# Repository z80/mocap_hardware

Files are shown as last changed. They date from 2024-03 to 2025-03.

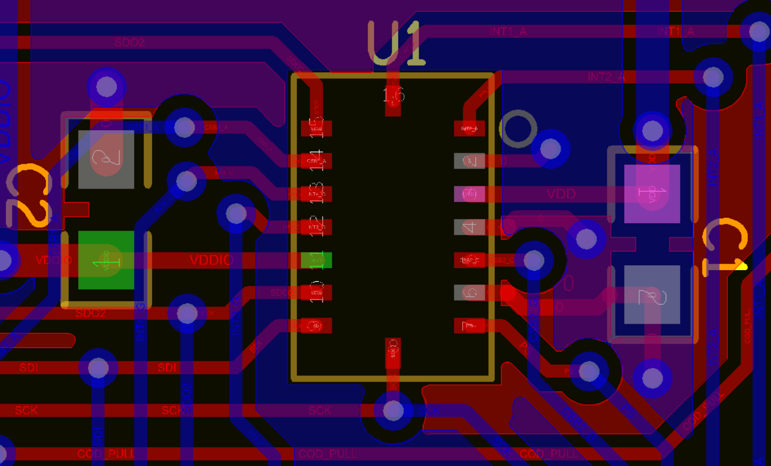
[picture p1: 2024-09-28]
part_datasheets/bmi085/typical_layout.png

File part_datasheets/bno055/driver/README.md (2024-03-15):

CONTENTS OF THIS FILE
=======================
	* Introduction
	* Version
	* Integration details
	* Driver files information
	* Supported sensor interface
	* Copyright

INTRODUCTION
===============
	- This package contains the Bosch Sensortec MEMS BNO055 sensor driver (sensor API)
	- The sensor driver package includes bno055.h, bno055.c and bno055_support.c files

VERSION
=========
	- Version of bno055 sensor driver is:
		* bno055.c 		- V2.0.3
		* bno055.h 		- V2.0.3
		* bno055_support.c 	- V1.0.4

INTEGRATION DETAILS
=====================
	- Integrate bno055.h and bno055.c file in to your project.
	- The bno055_support.c file contains only examples for API use cases, so it is not required to integrate into project.

Driver FILES INFORMATION
===========================
	bno055.h
	-----------
		* This header file has the register address definition, constant definitions, data type definition and supported sensor driver calls declarations.

	 bno055.c
	------------
		* This file contains the implementation for the sensor driver APIs.

	 bno055_support.c
	----------------------
		* This file shall be used as an user guidance, here you can find samples of
    			* Initialize the sensor with I2C communication
        				- Add your code to the I2C bus read and bus write functions.
            					- Return value can be chosen by yourself
           					- API just passes that value to your application code
        				- Add your code to the delay function
        				- Change I2C address accordingly in bno055.h
   			* Power mode configuration of the sensor
   			* Get and set functions usage
			* Reading the sensor read out data

SUPPORTED SENSOR INTERFACE
====================================
	- This BNO055 sensor driver supports I2C interface

COPYRIGHT
===========
	- Copyright (C) 2015 - 2016 Bosch Sensortec GmbH

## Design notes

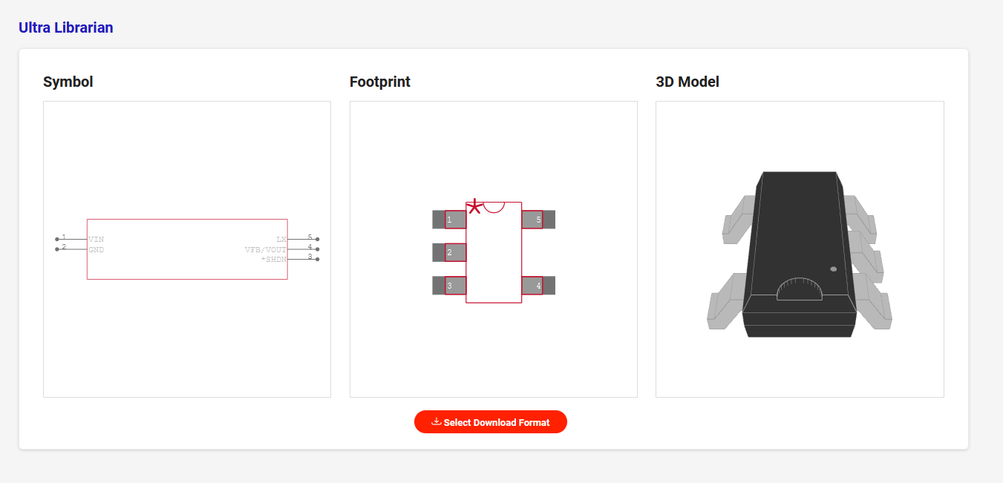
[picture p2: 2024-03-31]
part_datasheets/mcp1603_buck_converter/from_digikey_page.png

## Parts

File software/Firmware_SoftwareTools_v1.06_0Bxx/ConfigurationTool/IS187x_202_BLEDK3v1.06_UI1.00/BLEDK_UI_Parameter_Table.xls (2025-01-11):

Date: 2016/04/20
Name | Display | Range | Help | ID
Name Fragment | Edit Box | 32 characters | NameFragment is a local device name. If a remote device requires a local name, a local device replies the local device name. | IDC_STATIC_NAME_FRAGMENT
HCI Baud Rate Index | ComboBox | 0x00 : 921600 0x01 : 460800 0x02 : 230400 0x03 : 115200 0x04 : 57600 0x05 : 38400 0x06 : 28800 0x07 : 19200 0x08 : 14400 0x09 : 9600 0x0A : 4800 0x0B : 2400 | Baud rate index of the HCI UART port. | IDC_STATIC_HCI_BAUD_RATE_INDEX
H/W Flow Control | ComboBox | Disable Enable | UART H/W flow control (CTS). This parameter need to be set as disable if MCU not support flow control. If Operation Pattern select Manual Pattern, the flow control will be set as disable automatically. | IDC_STATIC_CTS_RTS_FLOW_CONTROL
Check Rx Data Interval | Edit Box | 0x00 ~ 0xFF | The time interval that BLEDK3 checks the received data buffer. When set as “00”, the default value in BLEDK3 for each baud rate is as below: 921600 ~ 19200:0x01 14400 ~ 9600:0x02 4800:0x04 Others:0x07 (Unit: 0.625ms) This parameter can be modified when the default setting can’t meet the requirement. The new set up value must greater than the default value. | IDC_STATIC_CHECK_RX_DATA_INTERVAL
UART RX_IND | ComboBox | Enable Disable | Enable / Disable UART RX IND | IDC_STATIC_UART_RX_IND
Operation Pattern | ComboBox | Auto Pattern Manual Pattern | This parameter is used to set the operation pattern between Auto Pattern and Manual Pattern. | IDC_STATIC_OPERATION_PATTERN
Configure Mode Timeout | Edit Box | 0x00: Disable Configure Mode, 0x01~0xFF | This parameter is used to set BLEDK3 configure mode timeout period in Auto Pattern Tool option. | IDC_STATIC_CONFIGURE_MODE_TIMEOUT
Power On Standby Time | Edit Box | 0x01 ~ 0xFF | The standby time duration after power on. Device will enter Shut Down mode when time is up. 0x00~0xFE: Standby time parameter range. 0xFF: Disable Enter shut down mode. | IDC_STATIC_POWER_ON_STANDBY_TIME
Disconnection Standby Time | Edit Box | 0x01 ~ 0xFF | The standby time duration after link disconnected. Device will enter shut down mode when time is up. 0x00~0xFE: Standby time parameters. 0xFF: Disable enter shut down mode. | IDC_STATIC_REMOTE_DISCONNECT_STANDBY_TIME
Wakeup Externel MCU Wait Time | Edit Box | 0x00 ~ 0xFF | The time interval between UART_TX_IND enabled and UART_TXD start transmit data. | IDC_STATIC_WAKEUP_EXTERNAL_MCU_WAIT_TIME
Wakeup Pin Option | ComboBox | Enable waken up from shutdown mode by wakeup pin Disable waken up from shutdown mode by wakeup pin | This parameter is used to decide BLEDK3 can be woken up from shutdown mode by wakeup pin or not. If option is enabled, GPIO P2_3 will be configured as wakeup Pin. | IDC_STATIC_WAKEUP_PIN_OPTION
Bluetooth 4.0 BLE Security | ComboBox | Disable Pairing Request Permission Enable | This parameter is used to set BLE Security. Refer to BLUETOOTH SPECIFICATION 4.0 or latest version for the detail. | IDC_STATIC_BLE_SECURITY
IO Capability | ComboBox | 0x00: DisplayOnly 0x01: DisplayYesNo 0x02: KeyboardOnly 0x03: NoInputNoOutput 0x04: KeyboardDisplay | This parameter is used to configure IO Capability. Refer to BLUETOOTH SPECIFICATION 4.0 or latest version for the detail. | IDC_STATIC_IO_CAPABILITY
BLE User Confirm Option | ComboBox | Disable LE user confirm refer to passkey Enable LE user confirm refer to passkey | This parameter is used to enable/disable LE(Low Energy) user confirmation referring to passkey. The passkey must set 6 digits if enabled. | IDC_STATIC_BLE_USER_CONFIRM_OPTION
Passkey | Edit Box | 6 Numbers | The Passkey which is six byte ASCII code and be used in passkey confirm. | IDC_STATIC_PASSKEY
Trust Device Connection | ComboBox | Disable Enable | This parameter is used to enable/disable trust (paired) device connection. | IDC_STATIC_TRUST_DEVICE_CONNECTION
LE Secure Connections | ComboBox | Disable Enable LE Secure Connections Only Mode | This parameter is used to enable/disable BlueTooth 4.2 LE Secure Connections. | IDC_STATIC_LE_SECURE_CONNECTIONS
Link Manager Version | ComboBox | Link Manager version is BT4.0 Link Manager version is BT4.2 | This parameter is used to choose Link Manager Version between BT4.0 and BT4.2 . | IDC_STATIC_LINK_MANAGER_VERSION
Data Length Extension | ComboBox | Disable Enable | This parameter is used to enable/disable Data Length Extension. | IDC_STATIC_DATA_LENGTH_EXTENSION
eFlash Footprint | Edit Box | (16 characters) | The 16 ASCII characters for the customers' version control code. The download tool can check by this code and reject to download the eFlash if it's mismatch. | IDC_STATIC_FOOTPRINT
Link Quality Detection | ComboBox | Disable Enable | Enable/Disable link quality detection. The RF_Tx_Power_Control_feature will be disabled if Enable this parameter. | IDC_STATIC_LINK_QUALITY_DETECTION
RSSI Normal Threshold | Edit Box | 50 ~ 90 | RSSI: RF Signal Strength Indication. This parameter is used to set RSSI normal threshold value If detected RSSI value greater or lower than normal threshold level, the configured RSSI_IND GPIO pin will output high or low level respectively. | IDC_STATIC_RSSI_NORMAL_THRESHOLD
RSSI Weak Threshold | Edit Box | 50 ~ 90 | If detected RSSI value greater or lower than weak threshold level, the configured RSSI_IND GPIO pin will output high or low level respectively. | IDC_STATIC_RSSI_WEAK_THRESHOLD
Battery Detection Interval | Edit Box | (1~255) | This parameter is used to set battery detection interval. | IDC_STATIC_BATTERY_DETECTION
High Battery Level | ComboBox | 0x00 : 0.9 V 0x01 : 1.0 V … 0x21 : 4.2 V | High battery level. | IDC_STATIC_HIGH_BATTERY_LEVEL
Normal Battery Level | ComboBox | 0x00 : 0.9 V 0x01 : 1.0 V … 0x21 : 4.2 V | This parameter is defined a normal voltage value of a battery. When the voltage is lower than this value,the device will start low battery warring. | IDC_STATIC_NORMAL_BATTERY_LEVEL
Low Battery Level | ComboBox | 0x00 : 0.9 V 0x01 : 1.0 V … 0x21 : 4.2 V | This parameter is defined a low voltage value of a battery. When the voltage is lower than this value, the configured “LOW_BATTERY_IND” GPIO will output low and the device will enter shutdown mode after the “Low Battery Into Shutdown Time”. | IDC_STATIC_LOW_BATTERY_LEVEL
Dangerous Battery Level | ComboBox | 0x00 : 0.9 V 0x01 : 1.0 V … 0x21 : 4.2 V | When the voltage is lower than Dangerous Battery Level, the device will enter shutdown mode. | IDC_STATIC_DANGEROUS_BATTERY_LEVEL
Low Battery Into Shutdown Time | Edit Box | 0x00:Disable，0x01~0xFF(Unit:640ms) | This parameter is used to set the waiting time befor enter into shutdown mode if low battery happens. (0x00: Disable enter into shutdown mode when low battery happens) | IDC_STATIC_LOW_BATTERY_INTO_POWER_DOWN_TIME
RF Class | ComboBox | 0x01: class 1 0x02: class 2 | The RF_Class is the RF class type. If class 1 is selected, GPIO P1_0 and P2_4 will be set as TX and RX control respectively (High Enable). | IDC_STATIC_RF_CLASS
P36 | Button | 0x01: UART_RTS_CONFIGURE 0x02: BATTERY_LOW_CONFIGURE 0x03: LINK_QUALITY_CONFIGURE 0x05: LINK_DROP_CONFIGURE 0x06: UART_RX_IND_CONFIGURE 0x07: PAIRING_CONFIGURE 0x08: RF_ACTIVE_IND_CONFIGURE 0x09: STATUS1_IND 0x0A: STATUS2_IND | Configure function to the GPIO pins. For detail description please refer to the BLEDK3 release note in “IS187x_BM7X BLEDK3 Application Note” document. | IDC_STATIC_P36
P10 | Button | 0x02: BATTERY_LOW_CONFIGURE 0x03: LINK_QUALITY_CONFIGURE 0x05: LINK_DROP_CONFIGURE 0x06: UART_RX_IND_CONFIGURE 0x07: PAIRING_CONFIGURE 0x08: RF_ACTIVE_IND_CONFIGURE 0x09: STATUS1_IND 0x0A: STATUS2_IND |  | IDC_STATIC_P10
P00 | Button | 0x02: BATTERY_LOW_CONFIGURE 0x03: LINK_QUALITY_CONFIGURE 0x04: UART_CTS_CONFIGURE 0x05: LINK_DROP_CONFIGURE 0x06: UART_RX_IND_CONFIGURE 0x07: PAIRING_CONFIGURE 0x08: RF_ACTIVE_IND_CONFIGURE 0x09: STATUS1_IND 0x0A: STATUS2_IND |  | IDC_STATIC_P00
P31 | Button | 0x02: BATTERY_LOW_CONFIGURE 0x03: LINK_QUALITY_CONFIGURE 0x05: LINK_DROP_CONFIGURE 0x06: UART_RX_IND_CONFIGURE 0x07: PAIRING_CONFIGURE 0x08: RF_ACTIVE_IND_CONFIGURE 0x09: STATUS1_IND 0x0A: STATUS2_IND |  | IDC_STATIC_P31
P32 | Button | 0x02: BATTERY_LOW_CONFIGURE 0x03: LINK_QUALITY_CONFIGURE 0x05: LINK_DROP_CONFIGURE 0x06: UART_RX_IND_CONFIGURE 0x07: PAIRING_CONFIGURE 0x08: RF_ACTIVE_IND_CONFIGURE 0x09: STATUS1_IND 0x0A: STATUS2_IND |  | IDC_STATIC_P32
P33 | Button | 0x02: BATTERY_LOW_CONFIGURE 0x03: LINK_QUALITY_CONFIGURE 0x05: LINK_DROP_CONFIGURE 0x06: UART_RX_IND_CONFIGURE 0x07: PAIRING_CONFIGURE 0x08: RF_ACTIVE_IND_CONFIGURE 0x09: STATUS1_IND 0x0A: STATUS2_IND |  | IDC_STATIC_P33
P34 | Button | 0x02: BATTERY_LOW_CONFIGURE 0x03: LINK_QUALITY_CONFIGURE 0x05: LINK_DROP_CONFIGURE 0x06: UART_RX_IND_CONFIGURE 0x07: PAIRING_CONFIGURE 0x08: RF_ACTIVE_IND_CONFIGURE 0x09: STATUS1_IND 0x0A: STATUS2_IND |  | IDC_STATIC_P34
P07 | Button | 0x02: BATTERY_LOW_CONFIGURE 0x03: LINK_QUALITY_CONFIGURE 0x05: LINK_DROP_CONFIGURE 0x06: UART_RX_IND_CONFIGURE 0x07: PAIRING_CONFIGURE 0x08: RF_ACTIVE_IND_CONFIGURE 0x09: STATUS1_IND 0x0A: STATUS2_IND |  | IDC_STATIC_P07
P11 | Button | 0x02: BATTERY_LOW_CONFIGURE 0x03: LINK_QUALITY_CONFIGURE 0x05: LINK_DROP_CONFIGURE 0x06: UART_RX_IND_CONFIGURE 0x07: PAIRING_CONFIGURE 0x08: RF_ACTIVE_IND_CONFIGURE 0x09: STATUS1_IND 0x0A: STATUS2_IND |  | IDC_STATIC_P11
P22 | Button | 0x02: BATTERY_LOW_CONFIGURE 0x03: LINK_QUALITY_CONFIGURE 0x05: LINK_DROP_CONFIGURE 0x06: UART_RX_IND_CONFIGURE 0x07: PAIRING_CONFIGURE 0x08: RF_ACTIVE_IND_CONFIGURE 0x09: STATUS1_IND 0x0A: STATUS2_IND |  | IDC_STATIC_P22
P24 | Button | 0x02: BATTERY_LOW_CONFIGURE 0x03: LINK_QUALITY_CONFIGURE 0x05: LINK_DROP_CONFIGURE 0x06: UART_RX_IND_CONFIGURE 0x07: PAIRING_CONFIGURE 0x08: RF_ACTIVE_IND_CONFIGURE 0x09: STATUS1_IND 0x0A: STATUS2_IND |  | IDC_STATIC_P24
P35 | Button | 0x02: BATTERY_LOW_CONFIGURE 0x03: LINK_QUALITY_CONFIGURE 0x05: LINK_DROP_CONFIGURE 0x06: UART_RX_IND_CONFIGURE 0x07: PAIRING_CONFIGURE 0x08: RF_ACTIVE_IND_CONFIGURE 0x09: STATUS1_IND 0x0A: STATUS2_IND |  | IDC_STATIC_P35
P12 | Button | 0x02: BATTERY_LOW_CONFIGURE 0x03: LINK_QUALITY_CONFIGURE 0x05: LINK_DROP_CONFIGURE 0x06: UART_RX_IND_CONFIGURE 0x07: PAIRING_CONFIGURE 0x08: RF_ACTIVE_IND_CONFIGURE 0x09: STATUS1_IND 0x0A: STATUS2_IND |  | IDC_STATIC_P12
P13 | Button | 0x02: BATTERY_LOW_CONFIGURE 0x03: LINK_QUALITY_CONFIGURE 0x05: LINK_DROP_CONFIGURE 0x06: UART_RX_IND_CONFIGURE 0x07: PAIRING_CONFIGURE 0x08: RF_ACTIVE_IND_CONFIGURE 0x09: STATUS1_IND 0x0A: STATUS2_IND |  | IDC_STATIC_P13
P16 | Button | 0x02: BATTERY_LOW_CONFIGURE 0x03: LINK_QUALITY_CONFIGURE 0x05: LINK_DROP_CONFIGURE 0x06: UART_RX_IND_CONFIGURE 0x07: PAIRING_CONFIGURE 0x08: RF_ACTIVE_IND_CONFIGURE 0x09: STATUS1_IND 0x0A: STATUS2_IND |  | IDC_STATIC_P16
P17 | Button | 0x02: BATTERY_LOW_CONFIGURE 0x03: LINK_QUALITY_CONFIGURE 0x05: LINK_DROP_CONFIGURE 0x06: UART_RX_IND_CONFIGURE 0x07: PAIRING_CONFIGURE 0x08: RF_ACTIVE_IND_CONFIGURE 0x09: STATUS1_IND 0x0A: STATUS2_IND |  | IDC_STATIC_P17
RF Active IND MCU Include | ComboBox | Indication only when RF active Indication when MCU and RF active | This parameter is used to choose the indication type of RF active. It is activated when RF_ACTIVED_IND function is configured to a GPIO pin. The GPIO will output high when activated. The option is selected between Indication when RF active and Indication when both MCU and RF active. | IDC_STATIC_RF_ACTIVE_IND_MCU_INCLUDE
LE Connection Parameter Update Request | ComboBox | Disable Enable | The LE Connection Setting will be assigned by remote side if select disable. If Enable, device will sent the LE connection parameter update request. | IDC_STATIC_LE_CONNECTION_PARAMETER_UPDATE
Min LE Connection Interval | Edit Box | 0x0008 ~ 0x0C80, Unit: 1.25ms | This parameter is used to set LE min connection interval | IDC_STATIC_MIN_LE_CONNECTION_INTERVAL
Max LE Connection Interval | Edit Box | 0x0010 ~ 0x0C80, Unit: 1.25ms | This parameter is used to set LE max connection interval | IDC_STATIC_MAX_LE_CONNECTION_INTERVAL
LE Slave Latency | Edit Box | 0x0000 ~ 0x03E8 | This parameter is used to set LE slave latency. Slave Latency allows a slave to use a reduced number of connection events. The LE Slave Latency parameter defines the number of consecutive connection events that the slave device is not required to listen for the master. More latency, more power saving but reduced connection event. For example, If slave latency=3, Connection event interval is 100msec, Slave device will wake up every 400msec. (100*(1+3)=400). That is slave only has one Connection event while master already have three connection events. | IDC_STATIC_LE_SLAVE_LATENCY
LE Supervision Timeout | Edit Box | 0x000A ~ 0x0C80 | This parameter is used to set LE supervision timeout | IDC_STATIC_LE_SUPERVISION_TIMEOUT
LE Fast Advertising Interval | Edit Box | 0x0020 ~ 0x4000 | This parameter is used to set “LE fast advertising interval”, which will make LE device work in fast advertising interval after power on. The fast advertising time period is limited and can be set in“LE Fast Advertising Timeout”. | IDC_STATIC_LE_FAST_ADVERTISING_INTERVAL
LE Reduced Power Advertising Interval | ComboBox | 645ms 768ms 961ms 1065ms 1294ms | This parameter is used to set LE reduced power advertising interval. The interval is longer than “Fast Advertising Interval” so that the power consumption can be reduced. | IDC_STATIC_LE_REDUCED_POWER_ADVERTISING
LE Fast Advertising Timeout | Edit Box | 0x00 ~ 0xFF 設為0x00就不會離開Fast Advertising Mode | This parameter is uesd to set LE fast advertising timeout value | IDC_STATIC_LE_FAST_ADVERTISING_TIMEOUT
Power On LE Reduced Power Advertising Timeout | Edit Box |  | This parameter is uesd to show Power On LE Reduced Power Advertising timeout value. Power On LE Reduced Power Advertising timeout = Power on Standby Time - LE Fast Advertising Timeout. | IDC_STATIC_POWER_ON_LE_REDUCED_POWER_ADVERTISING_TIMEOUT
Disconnection LE Reduced Power Advertising Timeout | Edit Box |  | This parameter is uesd to show Disconnection LE Reduced Power Advertising Timeout value. Disconnection LE Reduced Power Advertising Timeout = Disconnection Standby Time - LE Fast Advertising Timeout | IDC_STATIC_DISCONNECTION_LE_REDUCED_POWER_ADVERTISING_TIMEOUT
Advertising Prefered Power Level | ComboBox | 0x00: 0 dBm 0x01: -6 dBm 0x02: -12 dBm 0x03: -18 dBm 0x04: -24 dBm 0x05: -30 dBm | Preferred Tx power level when advertising. There are six power level can be selected.(0,-5,-10,-15,-20,-25 dBm) | IDC_STATIC_ADVERTISING_TX_POWER_LEVEL
Connected Prefered Power Level | ComboBox | 0x00: 0 dBm 0x01: -6 dBm 0x02: -12 dBm 0x03: -18 dBm 0x04: -24 dBm 0x05: -30 dBm | Preferred TX power level when connected. (0,-5,-10,-15,-20,-25 dBm) | IDC_STATIC_CONNECTED_TX_POWER_LEVEL
Advertising Data Setting |  |  | This parameter is uesd to set advertising data. | IDC_STATIC_ADVERTISING_DATA_SETTING
Scan Response Data Setting |  |  | This parameter is uesd to set scan response data | IDC_STATIC_SCAN_RESPONSE_DATA_SETTING
Type | ComboBox | 0x00 : LED1 OFF, LED2 OFF 0x01 : LED1 ON, LED2 ON 0x02 : LED1 ON, LED2 OFF 0x03 : LED1 OFF, LED2 ON 0x04 : LED1 OFF, LED2 FLASH 0x05 : LED1 FLASH, LED2 OFF 0x06 : LED1 ON, LED2 FLASH 0x07 : LED1 FLASH, LED2 ON 0x08 : LED1, LED2 FLASH (simultaneous) 0x09 : LED1, LED2 FLASH (alternate) | The LED0(P0_2)display type setting for Standby, Link, Power On and Low Battery mode. There are 3 types are selectable: Always OFF, Always ON and Flash. The Flash method is set as below: | IDC_STATIC_LED_TYPE
On Duration | Edit Box | (1-255) Unit: 50ms | The LED on time during flash. | IDC_STATIC_LED_ON_TIME
Off Duration | Edit Box | (1-255) Unit: 50ms | The LED off time during flash. | IDC_STATIC_LED_OFF_TIME
Count | Edit Box | (0-3) or (0-255) | This is the number of the flashing times for a cycle. | IDC_STATIC_LED_COUNT
Interval | Edit Box | (0-255) Unit: 50ms | This is the time interval of a cycle. | IDC_STATIC_LED_INTERVAL
Interval | Edit Box | 0x00:Disable，0x01~0xFF(Unit:1sec) | This parameter is uesd to set LED warning time interval if low battery happens | IDC_STATIC_LOW_BATTERY_LED_INTERVAL
LED Brightness | ComboBox | 1 mA 2 mA ... 16 mA |  | IDC_STATIC_LED1_BRIGHTNESS
Beacon Feature | ComboBox | Disable Enable | Enable/Disable Beacon function | IDC_STATIC_BEACON_FEATURE
Beacon Admin Mode | ComboBox | Disable Enable | Enable/Disable Beacon administration mode. | IDC_STATIC_BEACON_ADMIN_MODE
Beacon Admin Timeout | Edit Box | (0-255) Unit: 640ms | This parameter is used to configure Beacon administration timeout value 0x00: Disable Beacon Administration Feature Range: 0x01~0xFF, Unit: 640mS | IDC_STATIC_BEACON_ADMIN_TIMEOUT
Beacon In Connection | ComboBox | Stop Beacon Advertising Beacon Advertising | This option is enabled when BeaconThings function enabled on UI Feature page. If BeaconThings function is enabled: Stop Beacon Advertising: Stop beacon advertising when LE connection is established. Beacon Advertising: Continue beacon advertising when LE connection is established. | IDC_STATIC_BEACON_IN_CONNECTION
Beacon Advertising Interval | Edit Box | (2 Bytes) | This parameter is used to configure the advertising interval for Beacon. | IDC_STATIC_BEACON_ADVERTISING_INTERVAL
Beacon Advertising Data Length | Edit Box | (1 Bytes) | This paraeter is used to configure advertising data length for Beacon using | IDC_STATIC_BEACON_ADVERTISING_DATA_LENGTH
Beacon Advertising Data | Edit Box | Max: 31 bytes | This paraeter is used to configure advertising data for Beacon using | IDC_STATIC_BEACON_ADVERTISING_DATA
Beacon Secret Key | Edit Box | (6 Bytes) | This parameter is used to configure Secret key for Beacon Admin usage | IDC_STATIC_BEACON_SECRET_KEY

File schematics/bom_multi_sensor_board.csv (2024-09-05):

Value | Qty | URL | url
"18p" | 2
"100n" | 6 | https://www.digikey.com/product-detail/en/yageo/CC0603KRX7R7BB104/311-1088-1-ND/302998
"100n" | 5
"4.7uH" | 1 | https://www.digikey.com/en/products/detail/murata-electronics/LQM2HPN4R7MG0L/1893673
"100" | 1 | https://www.digikey.com/en/products/detail/yageo/AC0603JR-07100RL/5896356
"1k" | 4 | https://www.digikey.com/en/products/detail/yageo/RC0603JR-131KL/13694162
"2k" | 83 | https://www.digikey.com/en/products/detail/yageo/AC0603JR-072K2L/5896418
"10k" | 3 | https://www.digikey.com/product-detail/en/yageo/RC0603JR-072K2L/311-2.2KGRCT-ND/729676
"10k" | 2 | https://www.digikey.com/en/products/detail/yageo/RC0603JR-1010KL/13694233
"100k" | 2
+ | 1
- | 1
"1N5819" | 2 | https://www.digikey.com/en/products/detail/stmicroelectronics/1N5819/1037326
"2u2" | 2
"4u7" | 16 | https://www.digikey.com/product-detail/en/samsung-electro-mechanics-america-inc/CL10B475KQ8NQNC/1276-2087-1-ND/3890173
"74HC165" | 4 | https://www.digikey.com/en/products/detail/nexperia-usa-inc/74LV165D-118/1231120
"BM71BLES1FC2-0B02AA" | 1 | https://www.digikey.com/en/products/detail/microchip-technology/BM71BLES1FC2-0B02AA/7164757
bm_cfg | 1
"Crystal" | 1 | https://www.digikey.com/en/products/detail/yic/8M20P2-49US/15648614
gnd | 1
LED | 4
"left hand 0" | 1 | https://www.digikey.com/en/products/detail/assmann-wsw-components/A-MJH-8-EA-GTP-W4/20522480
"left hand 1" | 1 | https://www.digikey.com/en/products/detail/assmann-wsw-components/A-MJH-8-EA-GTP-W4/20522480
"left hand 2" | 1 | https://www.digikey.com/en/products/detail/assmann-wsw-components/A-MJH-8-EA-GTP-W4/20522480
"left hand 3" | 1 | https://www.digikey.com/en/products/detail/assmann-wsw-components/A-MJH-8-EA-GTP-W4/20522480
"left leg 0" | 1 | https://www.digikey.com/en/products/detail/assmann-wsw-components/A-MJH-8-EA-GTP-W4/20522480
"left leg 1" | 1 | https://www.digikey.com/en/products/detail/assmann-wsw-components/A-MJH-8-EA-GTP-W4/20522480
"MCP111" | 1 | https://www.digikey.com/en/products/detail/microchip-technology/MCP111T-315E-TT/716028
"MCP1603" | 1 | https://www.digikey.com/en/products/detail/microchip-technology/MCP1603T-330I-OS/1098431
"MCP73812" | 1 | https://www.digikey.com/en/products/detail/microchip-technology/MCP73812T-420I-OT/1626618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
"MY_USB_B" | 1 | https://www.digikey.com/en/products/detail/on-shore-technology-inc/USB-B1HSB6/2677744
"right hand 0" | 1 | https://www.digikey.com/en/products/detail/assmann-wsw-components/A-MJH-8-EA-GTP-W4/20522480
"right hand 1" | 1 | https://www.digikey.com/en/products/detail/assmann-wsw-components/A-MJH-8-EA-GTP-W4/20522480
"right hand 2" | 1 | https://www.digikey.com/en/products/detail/assmann-wsw-components/A-MJH-8-EA-GTP-W4/20522480
"right hand 3" | 1 | https://www.digikey.com/en/products/detail/assmann-wsw-components/A-MJH-8-EA-GTP-W4/20522480
"right lef 0" | 1 | https://www.digikey.com/en/products/detail/assmann-wsw-components/A-MJH-8-EA-GTP-W4/20522480
"right leg 1" | 1 | https://www.digikey.com/en/products/detail/assmann-wsw-components/A-MJH-8-EA-GTP-W4/20522480
rst | 1
rx | 1
stm_boot | 1
swd | 1
"TCA9548A_TSSOP" | 2 | https://www.digikey.com/product-detail/en/texas-instruments/TCA9548APWR/296-34905-1-ND/3615448
"torso 0" | 1 | https://www.digikey.com/en/products/detail/assmann-wsw-components/A-MJH-8-EA-GTP-W4/20522480
"torso 1" | 1 | https://www.digikey.com/en/products/detail/assmann-wsw-components/A-MJH-8-EA-GTP-W4/20522480
"torso 2" | 1 | https://www.digikey.com/en/products/detail/assmann-wsw-components/A-MJH-8-EA-GTP-W4/20522480
"torso 3" | 1 | https://www.digikey.com/en/products/detail/assmann-wsw-components/A-MJH-8-EA-GTP-W4/20522480
tx | 1
uart1 | 1
Vdd | 1
"~" | 1 | https://www.digikey.com/en/products/detail/stmicroelectronics/stm32f405rgt6/2754208

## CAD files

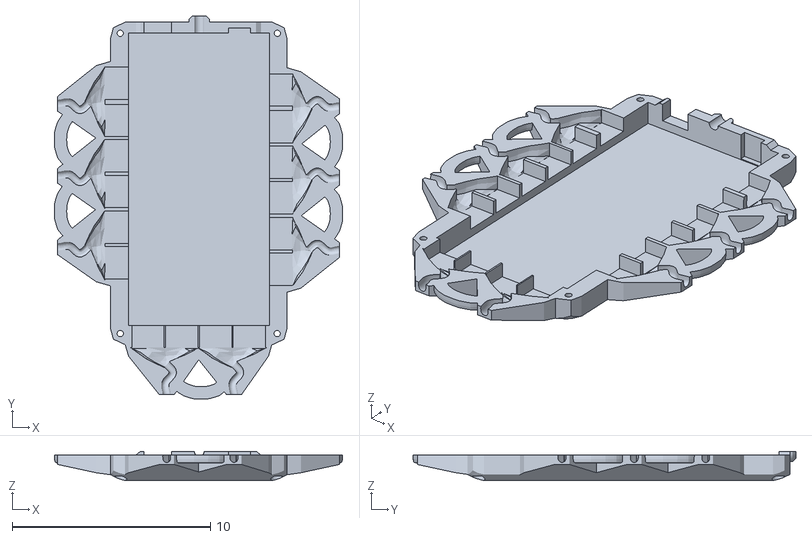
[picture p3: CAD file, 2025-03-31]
cad_drawings/case_for_host_board/case_for_host_board_bottom.stl
14.5 x 19.3 x 1.48

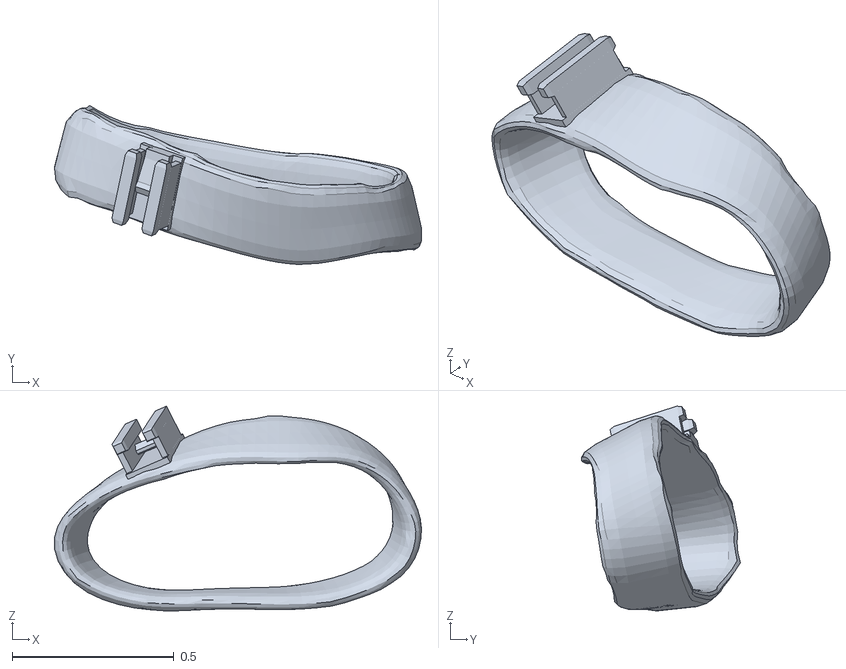
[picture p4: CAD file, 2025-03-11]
cad_drawings/foot/foot_holder_right.stl
1.13 x 0.491 x 0.632

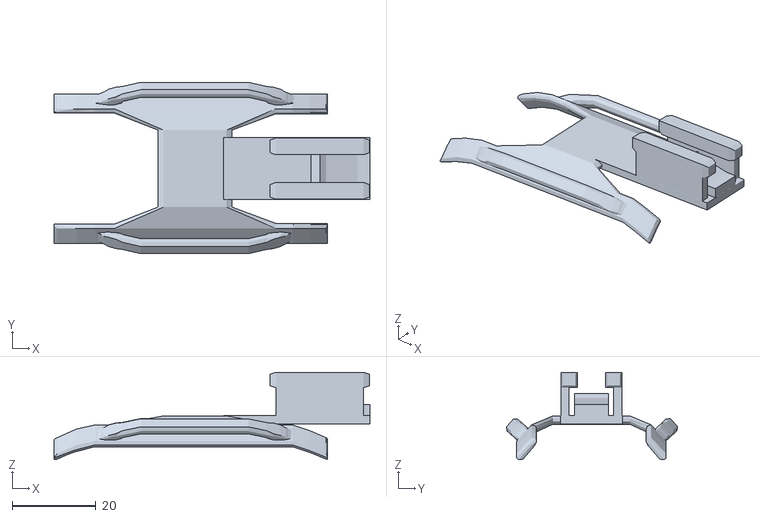
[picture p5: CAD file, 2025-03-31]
cad_drawings/generic_holder/generic_holder.stl
75.3 x 40.8 x 20.9

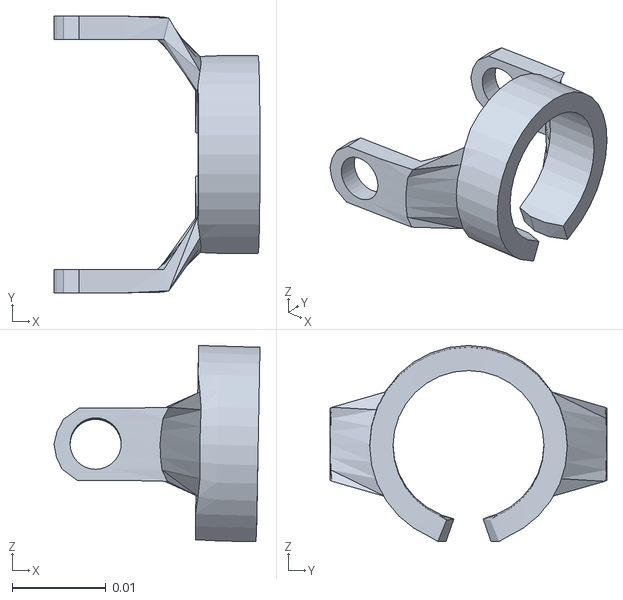
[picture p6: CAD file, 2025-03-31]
cad_drawings/hand/pointing_c.stl
0.022 x 0.0296 x 0.0209

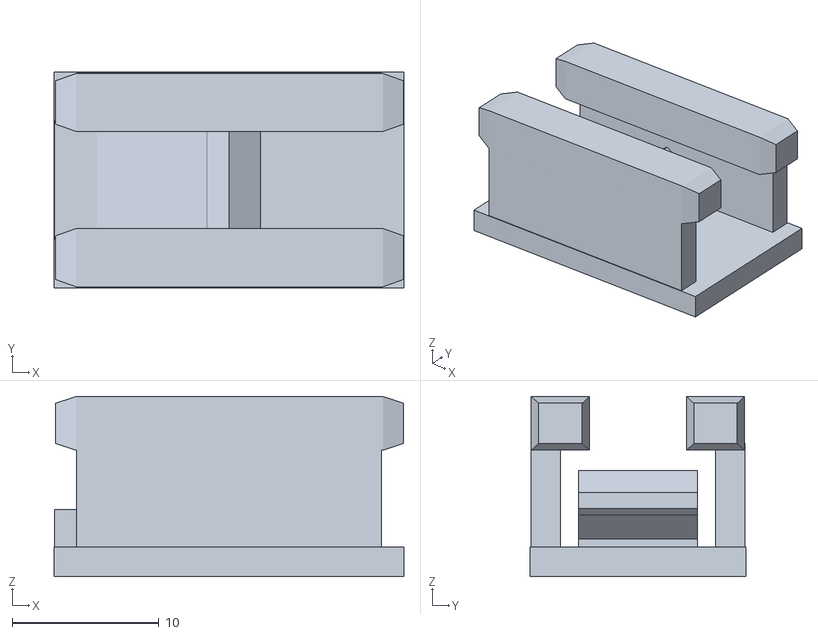
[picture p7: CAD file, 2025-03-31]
cad_drawings/imu_case/receptacle.stl
23.9 x 14.7 x 12.3

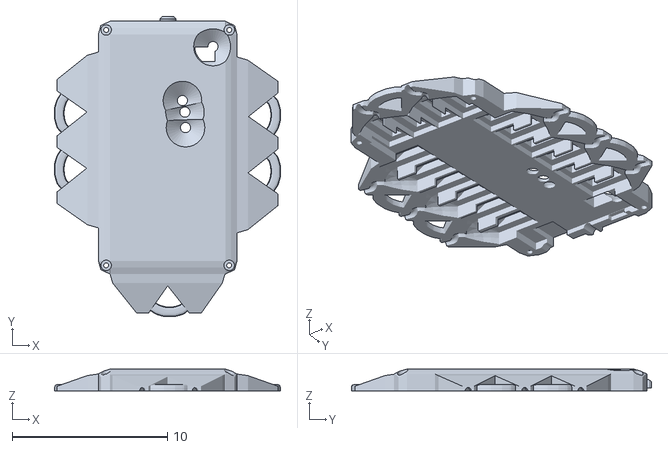
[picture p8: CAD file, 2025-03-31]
cad_drawings/case_for_host_board/case_for_host_board_top.stl
14.5 x 19.3 x 1.40

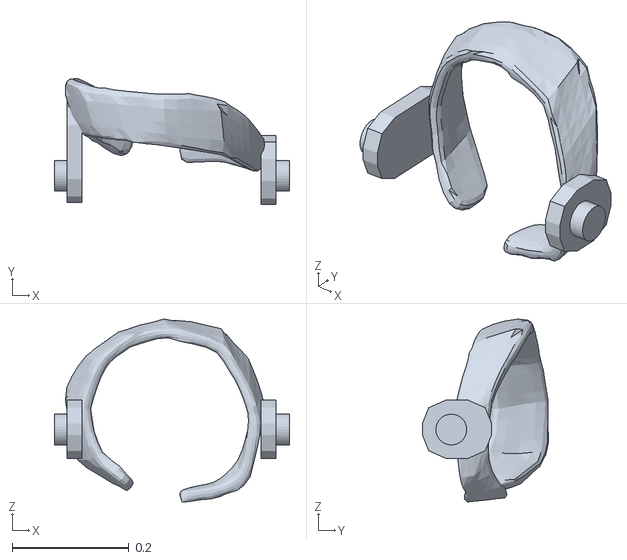
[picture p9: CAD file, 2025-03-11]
cad_drawings/foot/toe_left_a.stl
0.403 x 0.217 x 0.314

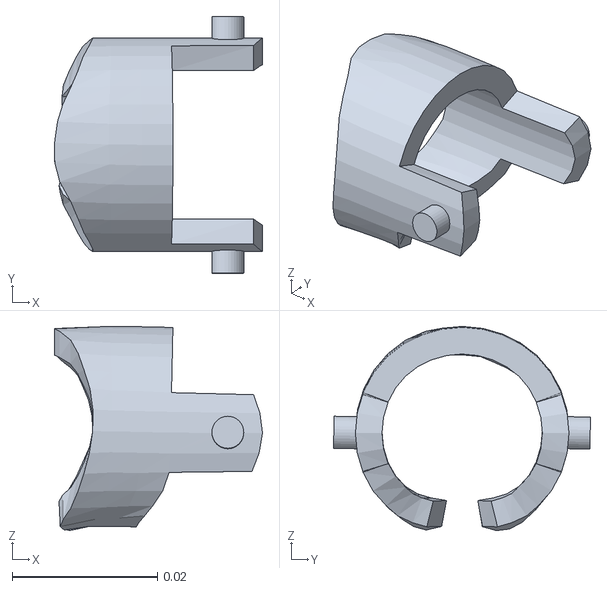
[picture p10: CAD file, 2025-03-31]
cad_drawings/hand/thumb_a.stl
0.0286 x 0.0353 x 0.0281

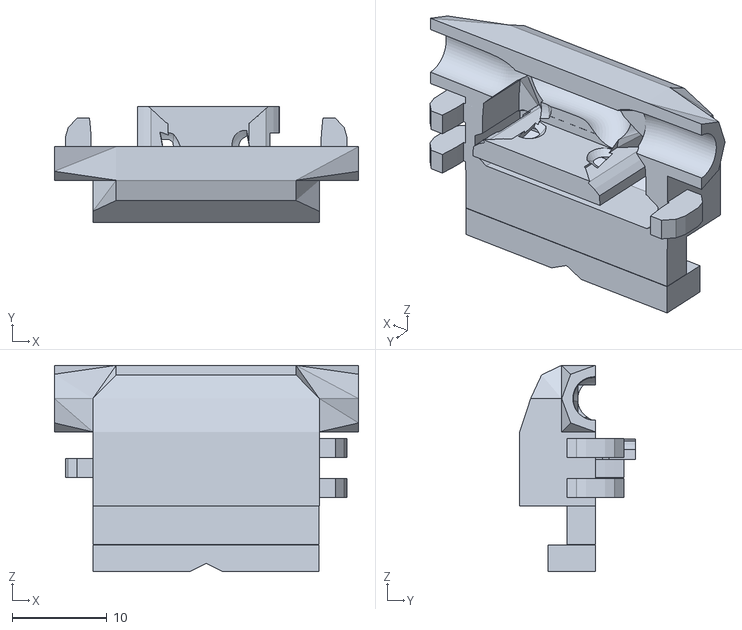
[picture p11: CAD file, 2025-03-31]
cad_drawings/imu_case/imu_case_left.stl
32.1 x 12.2 x 21.8

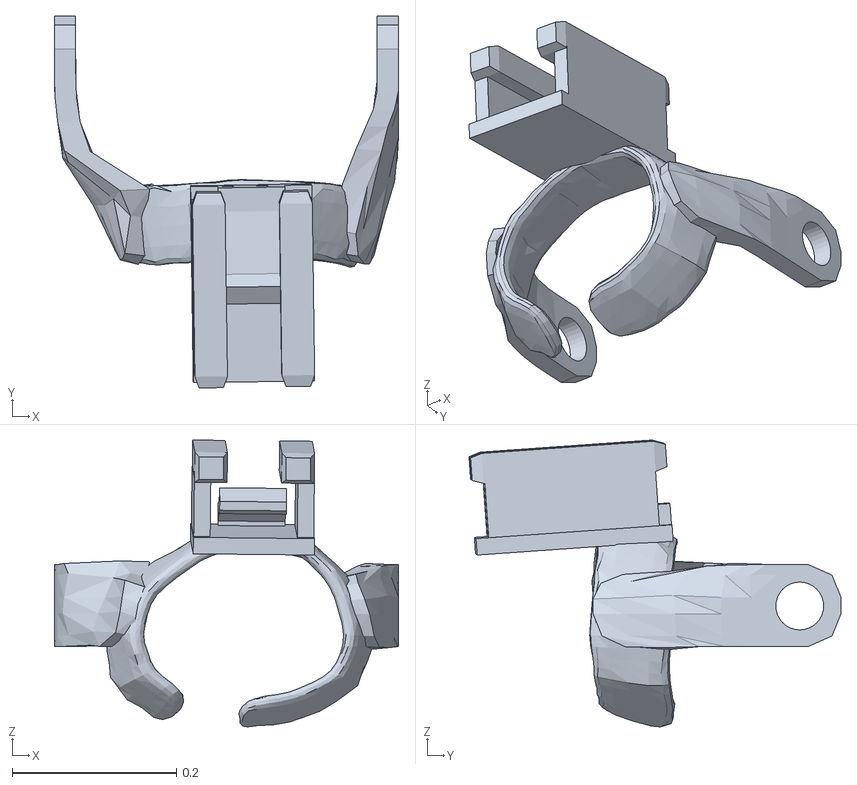
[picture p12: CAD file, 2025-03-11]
cad_drawings/foot/toe_left_b.stl
0.419 x 0.452 x 0.349

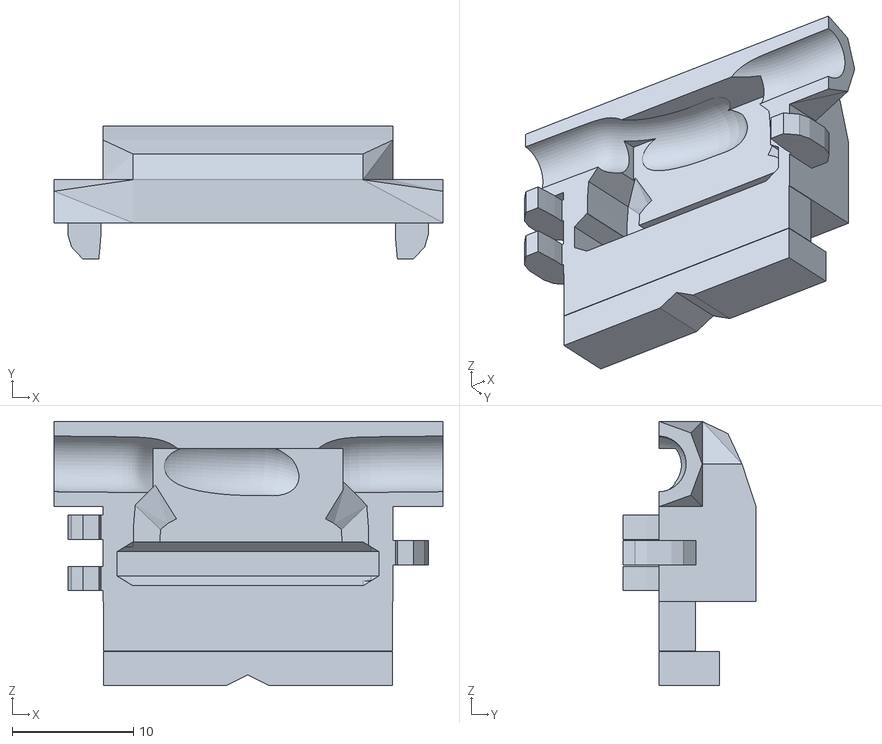
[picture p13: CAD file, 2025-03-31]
cad_drawings/imu_case/imu_case_right.stl
32.1 x 11.0 x 21.8

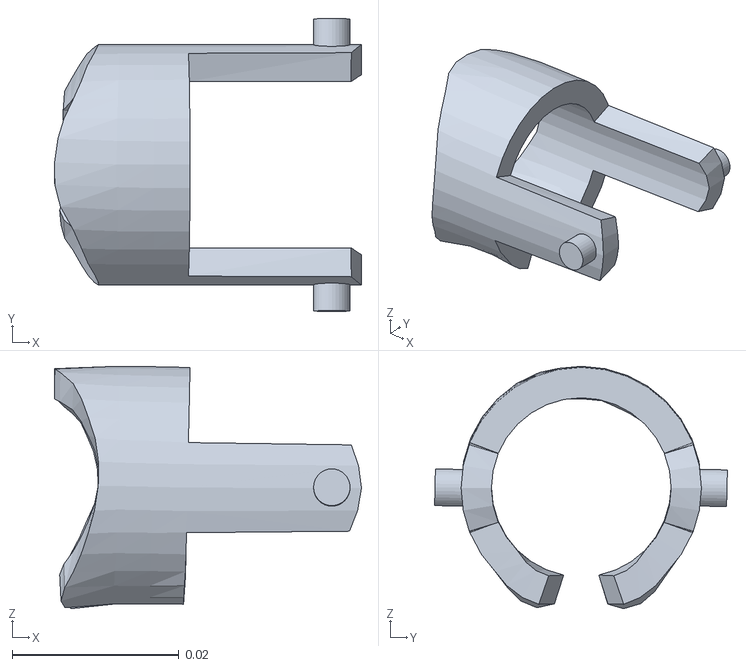
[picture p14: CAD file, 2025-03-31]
cad_drawings/hand/middle_a.stl
0.0369 x 0.0352 x 0.0291

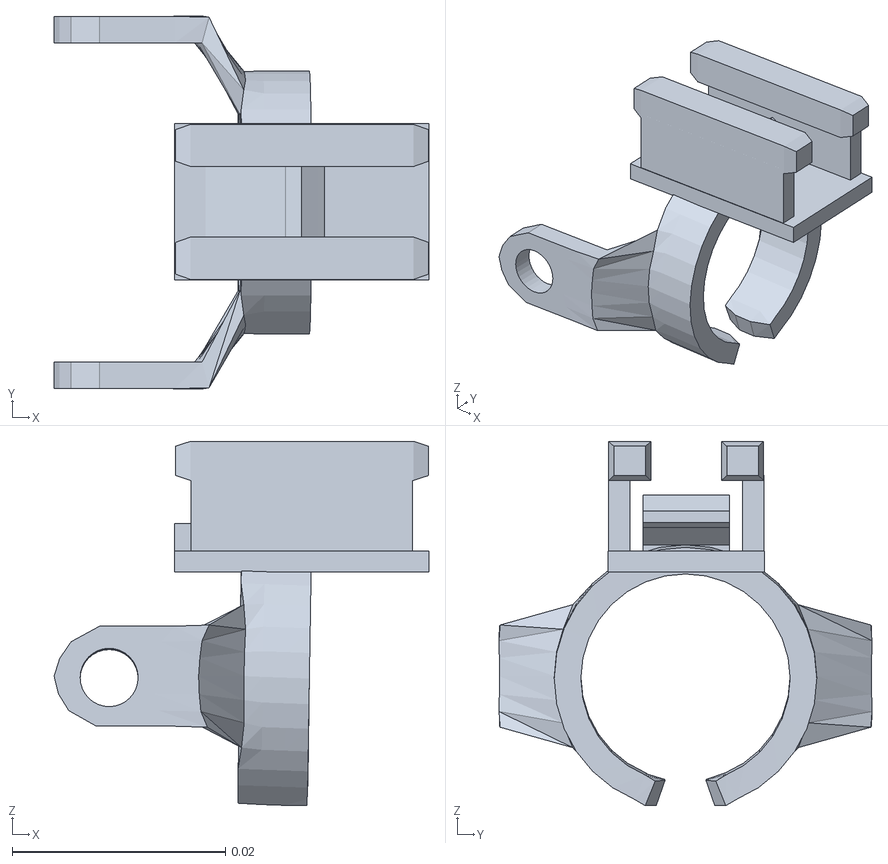
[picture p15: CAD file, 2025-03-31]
cad_drawings/hand/imu_holder_thumb.stl
0.0352 x 0.035 x 0.0342

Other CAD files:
cad_drawings/hand/middle_c.stl
cad_drawings/foot/foot_holder_left.stl
cad_drawings/foot/toe_right_a.stl
cad_drawings/hand/hand_c.stl
cad_drawings/foot/toe_right_b.stl
cad_drawings/generic_holder/generic_holder.blend
cad_drawings/hand/hand.blend
cad_drawings/hand/hand_b.stl
cad_drawings/hand/imu_holder_middle.stl
cad_drawings/hand/imu_holder_palm_l.stl
cad_drawings/hand/imu_holder_palm_r.stl
cad_drawings/hand/imu_holder_pinky.stl
cad_drawings/hand/imu_holder_pointing.stl
cad_drawings/hand/middle_b.stl
cad_drawings/hand/palm_a.stl
cad_drawings/hand/palm_b.stl
cad_drawings/hand/pinky_a.stl
cad_drawings/hand/pinky_b.stl
cad_drawings/hand/pinky_c.stl
cad_drawings/hand/pointing_a.stl
cad_drawings/hand/pointing_b.stl
cad_drawings/hand/thumb_b.stl
cad_drawings/imu_case/imu_case.blend
cad_drawings/locking_mechanism.blend

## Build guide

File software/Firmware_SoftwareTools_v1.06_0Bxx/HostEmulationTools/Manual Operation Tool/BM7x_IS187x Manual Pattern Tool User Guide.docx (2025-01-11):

# IS187x - BLEDK3 v1.00 Manual Pattern Tool

# User Guide

Table of Contents

# 1. Overview

BLEDK3 v0.9 manual pattern test tool is designed to be installed in Microsoft Windows based PC to act as an MCU emulator to transmit and receive commands and events through USB interface during Bluetooth LE profiles communications with a cellular phone.

This document describes how to use the BLEDK3 v0.9 manual pattern test tool, and introduces some supported commands with some examples. Not every single command is defined herein. Please refer to BLEDK3 Command Set document for details.

# 2. Hardware Environment

## 2.1 Top View of BM70BLES1FC2 EVB

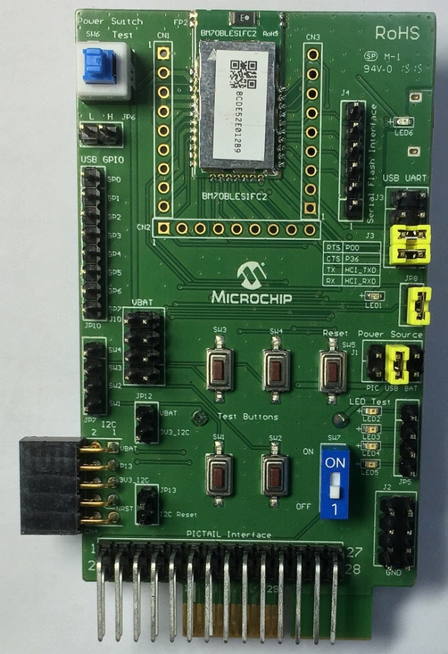
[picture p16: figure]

Figure 2.1 BLEDK3 EVB outlooks

## 2.2 Environment Setup

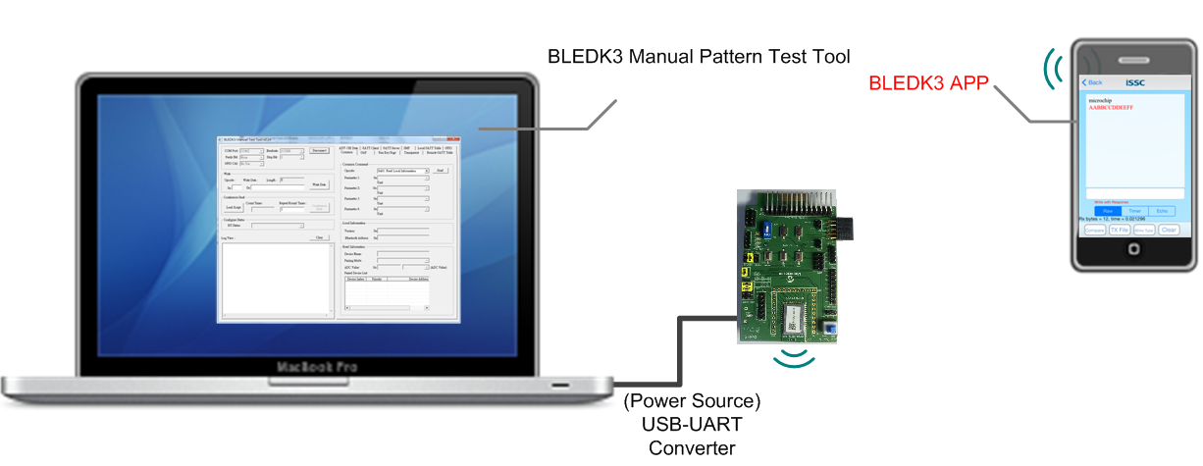
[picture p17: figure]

Figure 2.2 BLEDK3 environment setup

# 3. Tool Overview

Figure 3.1 Tool view

There are four groups of panels labeled by numbers from to in this tool:

1. Settings: The configuration of COM Port, Baud rate, Parity Bit, Stop Bit and GPIO Ctrl. GPIO Ctrl is used to do MCU emulation for specific GPIOs control by MCP2200.

2. Write and Continuous Send: This panel is used for developing only.

3. Log View: It displays all traffic between tool and BLEDK3. Commands will show in red texts and events will come out in blue ones.

4. Function Pages: They are used to do different function controls for BLEDK3. All commands supported by BLEDK3 are divided into several categories: [Common]、[GAP]、[Passkey Page]、[Transparent]、 [ADV/SR Data]、[SMP]、[DIO] 、[GATT Client]、[GATT Server]、[Remote GATT Table] and [Local GATT Table] are described in next chapter.

# 4. BLEDK3 Commands

## 4.1 Common Page

The Common Page includes commands for retrieving configuration or information of BLEDK3.

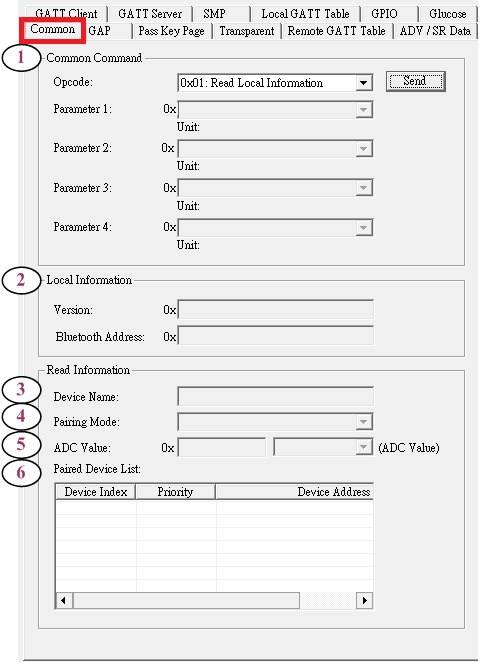
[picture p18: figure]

Figure 4.1 Common page view

1. The command set controller.

2. The response of the command (0x01: Read Local Information).

3. The response of the command (0x07: Read Device Name)

4. The response of the command (0x0A: Read Pairing Mode Setting)

5. The response of the command (0x04: Read ADC Value)

6. The response of the command (0x0C: Read All Paired Device Information)

## 4.2 GAP Page

The GAP Page includes commands for creating or releasing the Link and retrieve some connection information.

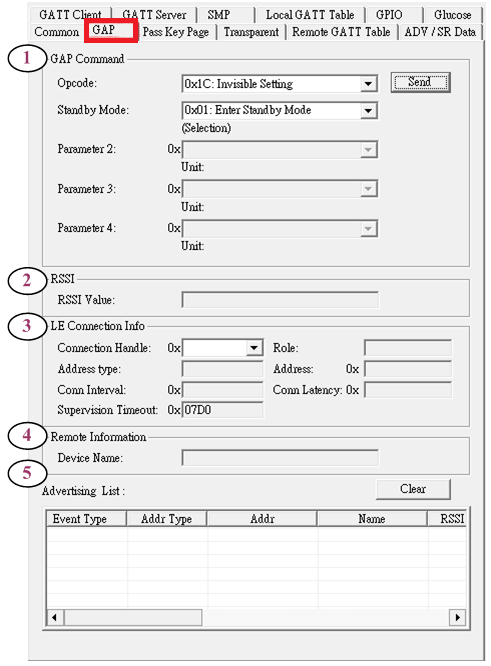
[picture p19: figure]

Figure 4.2 GAP page view

1. The command set controller.

2. The response of the command (0x10: Read RSSI Value).

3. The LE connection information will be displayed here when the LE connection is established.

4. The response of the command (0x1F: Read Remote Device Name).

5. The response of the command (0x16: Set Scan Enable).

## 4.3 Passkey Page

The Passkey Page includes commands for sending Passkey after receiving the pairing request event.

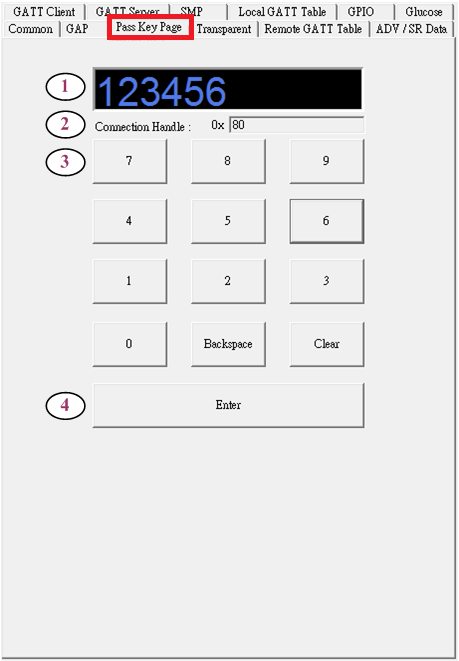
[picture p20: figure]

Figure 4.3 Passkey page view

1. This view will display the Passkey that user entered.

2. When the connection established, the Connection Handle will be filled automatically.

3. These buttons are used to send the command (0x40: Passkey Entry Response).

4. The Enter button is used to send passkey entry completed.

## 4.4 Transparent Page

The Transparent Page includes commands and settings for transmitting data (from BM70 to remote device), a display console for raw data between BM70 and remote device and some related parameter and status display.

Figure 4.4 Transparent page view

1. This is used to send a segment of data.

2. When a connection is established, the Connection Handle will be filled automatically.

3. The repeated round times of data file transmission. (Keep repeating if this parameter set to 0).

4. The delay time between data blocks.

5. The size of an UART data block.

6. The current round of repeating transmission.

7. Amount of transmitted data.

8. Amount of received data.

9. The received data will be sent back while it is enabled.

10. Enable/disable the Compare function. The comparison will be triggered without incoming data for more than 3 seconds.

11. The result of comparison.

12. The elapsed time of the data receiving

13. Load a text file for transmission or received data comparison

14. Start to transmit the file

15. Save received data as a file

16. Clear the received data in the temporary file.

17. The raw data console included transmitted (displayed as red text) and received (displayed as blue text) data.

18. Clear the raw data in the console

## 4.5 ADV / SR Data Page

The ADV / SR Data Page is used for updating the advertising and scan response data.

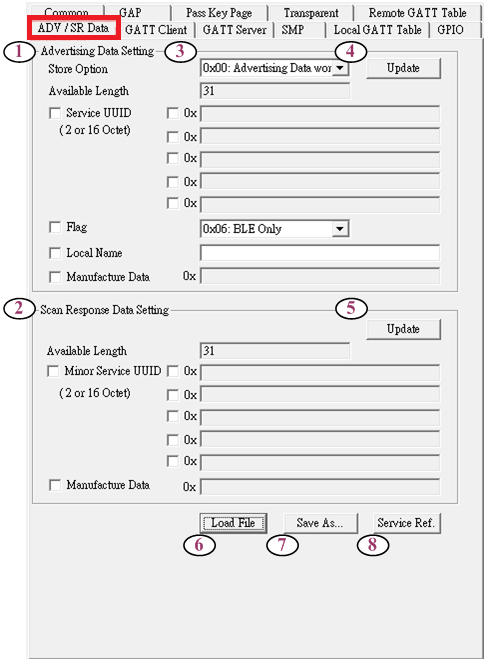
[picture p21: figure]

Figure 4.5 ADV/SR data page view

1. The advertising data editor.

2. The scan response data editor.

3. The store option of advertising data, save in EEPROM or not

4. To update the advertising data by sending command (0x11: Write ADV Data).

To update the scan response data by sending command (0x12: Write Scan Response Data).

To load the ADV / SR data file.

7. To save the ADV / SR data as a file.

8. To visit the services reference on the Bluetooth SIG official website.

## 4.6 SMP Page

The SMP Page is used to initiate pairing procedure.

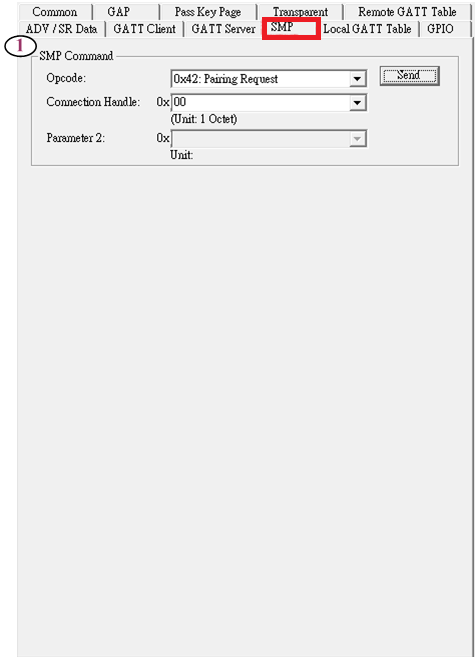
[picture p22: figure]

Figure 4.6 SMP page view

1. The command set controller.

## 4.7 DIO Page

The DIO Page includes commands for control Configurable DIOs and PWM of BLEDK3.

Figure 4.7 DIO page view

1. The command set of DIO control.

2. The command set of PWM control.

## 4.8 GATT Client Page

The GATT Client Page includes GATT client group commands for GATT client procedure.

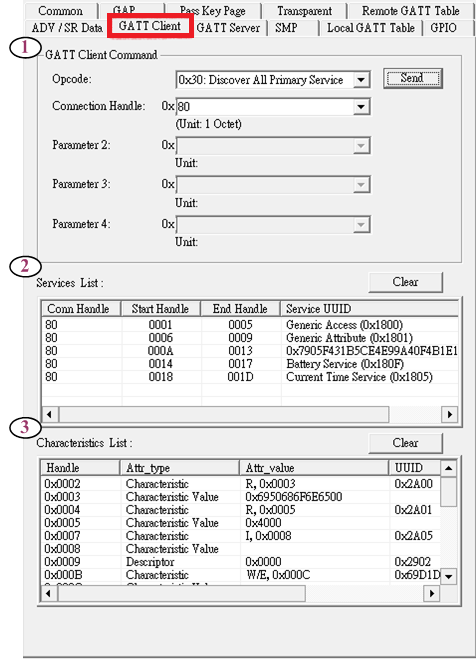
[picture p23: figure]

Figure 4.8 GATT client page view

1. The command set controller.

2. The response of the command (0x30: Discover All Primary Services).

3. The response of the command (0x31: Discover Specific Primary Service Characteristics and Descriptor)(0x32: Read Characteristic Value).

## 4.9 GATT Server Page

The GATT Server Page includes GATT Server group commands for GATT server procedure.

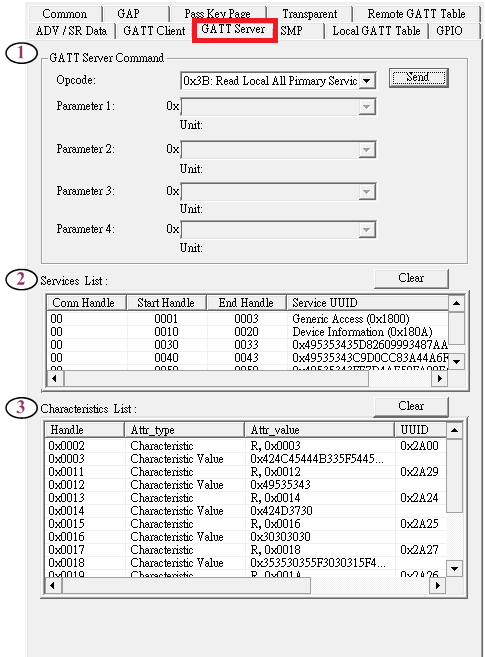
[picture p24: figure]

Figure 4.9 GATT server page view

1. The command set controller.

2. The response of the command (0x3B: Read Local All Primary Services).

3. The response of the command (0x3C: Read Local Specific Primary Service)(0x3A: Read Characteristic Value).

## 4.10 Remote GATT Table Page

The Remote GATT Table Page is used for asking client’s service from server.

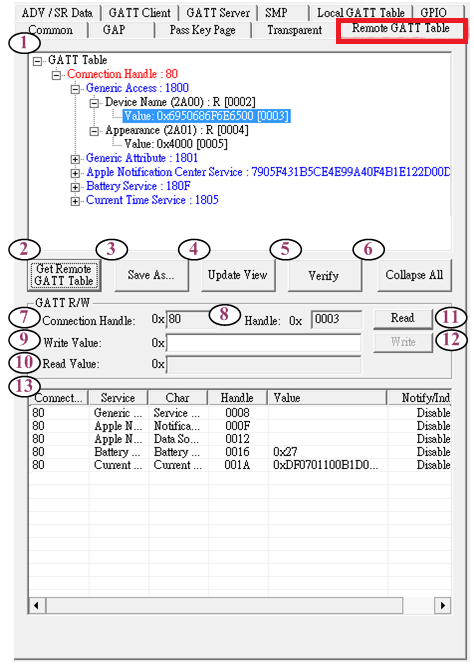
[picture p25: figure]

Figure 4.10 Remote GATT table page view

1. Show supported service of client

2. Start to get the GATT table.

3. Save the GATT table.

4. To update the GATT table.

5. To verify the GATT table.

6. To collapse or expand the GATT table.

7. When the GATT table is clicked, the Connection Handle will be filled automatically.

8. When the GATT table is clicked, the Characteristic Handle will be filled automatically

9. Write a characteristic value

10. Show characteristic value

11. Read Characteristic Value from server.

12. Write Characteristic Value to server.

13. Show support service of client

## 4.11 Local GATT Table Page

The Local GATT Table Page is used for asking server’s service.

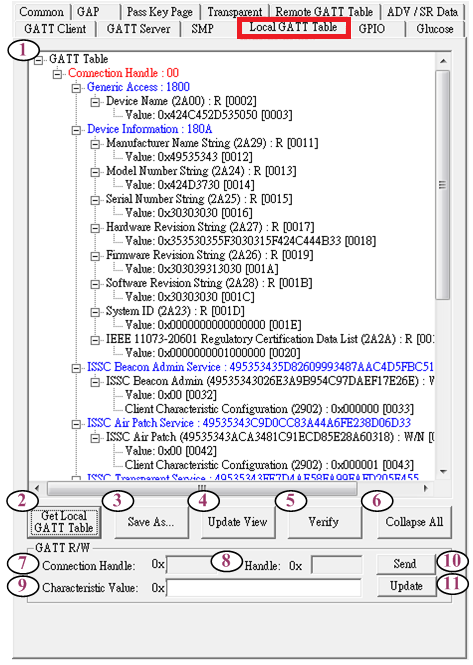
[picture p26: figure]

Figure 4.11 Local GATT table page view

1. Show support service of server

2. Start to get the Local GATT table.

3. Save the Local GATT table.

4. Update the Local GATT table.

5. Verify the Local GATT table.

6. Collapse or expand the Local GATT table.

7. When the Local GATT table is clicked, the Connection Handle will be filled automatically.

8. When the Local GATT table is clicked, the Characteristic Handle will be filled automatically

9. Write a characteristic value

10. Send characteristic value to GATT client

11. Update existing characteristic value of BLEDK3.

# 5. Examples of Operation

## 5.1 Connection

### 5.1.1 Slave Role

As a slave role, BLEDK3 must enter Standby Mode to be discoverable before a connection is established.

1. Select [GAP] Page.
2. Choose the command (0x1C: Invisible Setting).
3. Set the Enter Standby Mode to be discoverable. (0x01 or 0x02).
4. Press the [Send] button to let BLEDK3 advertise and enter Standby Mode.

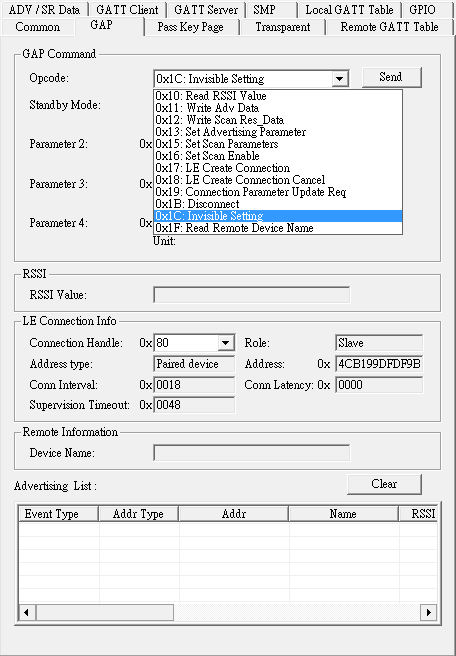
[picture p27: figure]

Figure 5.1.1 BLEDK3 enter standby mode

### 5.1.2 Connection Complete

The following information shows you how to check BLE connection is established successfully.

1. The BT Status will change to LE Connected Mode
2. The connection parameters will be displayed in the [GAP] page.

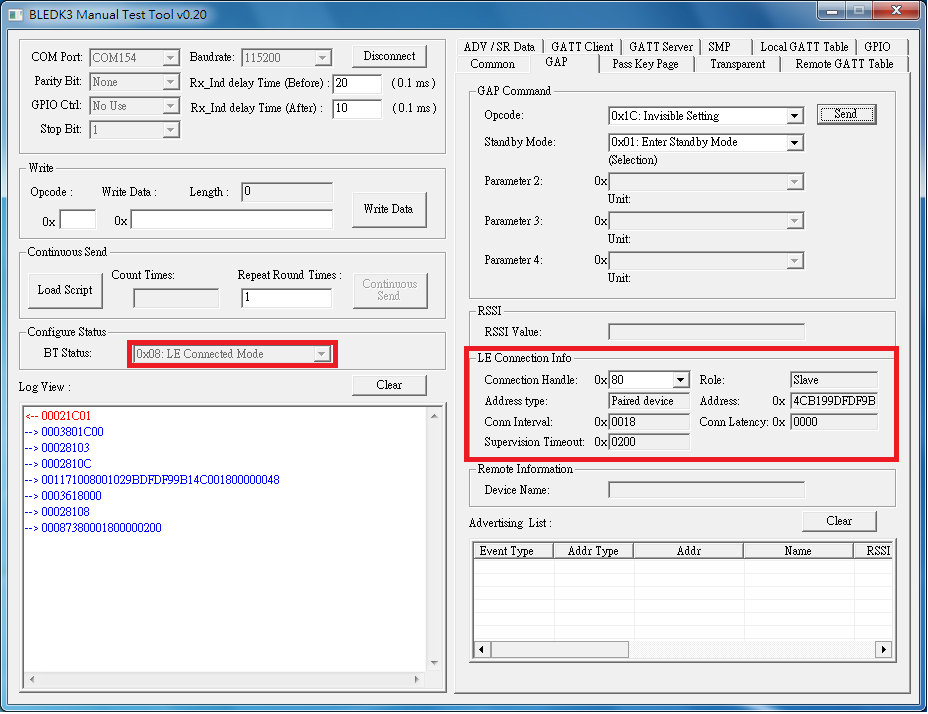
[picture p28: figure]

Figure 5.1.2 BLEDK3 in connected mode

## 5.2 Disconnection

Disconnect a link as below steps:

1. Select the [GAP] Page.
2. Choose the command (0x1B: Disconnect).
3. Press the [Send] button to disconnect the connection.

Figure 5.2.1 BLEDK3 disconnect the connection

There will pop up a message to show the disconnection reason after disconnection is completed.

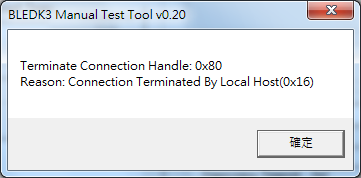
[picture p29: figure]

Figure 5.2.2 The disconnection message

## 5.3 Transparent Service

### 5.3.1 Transparent Operation

There are three ways to transmit data, send data、send a file and loop back mode.

- Send data:
1. Input a segment of send data in the field.
2. Press [Send] button to start the transmission.

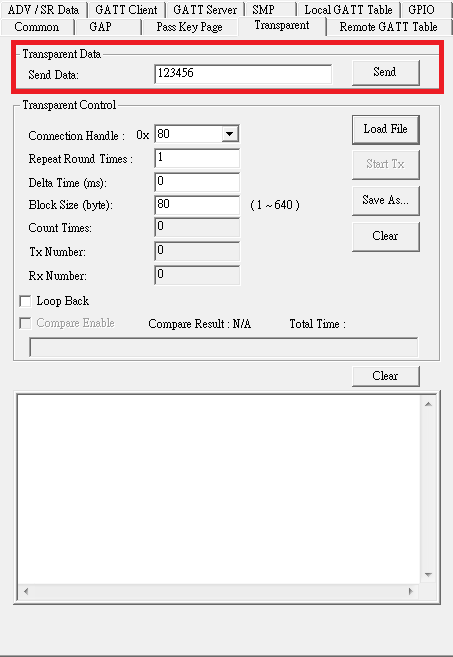
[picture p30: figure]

Figure 5.3.1 Send data

- Send a file:
1. Press [Load File] button to load a text file.
2. Type the [Repeat Round Times], [Delta Time] and [Block Size].
3. Press [Start TX] button to start the transmission.

Figure 5.3.2 Send file

#### Loop back mode:

1. Check the Loop Back item.
2. The received data will be sent back.

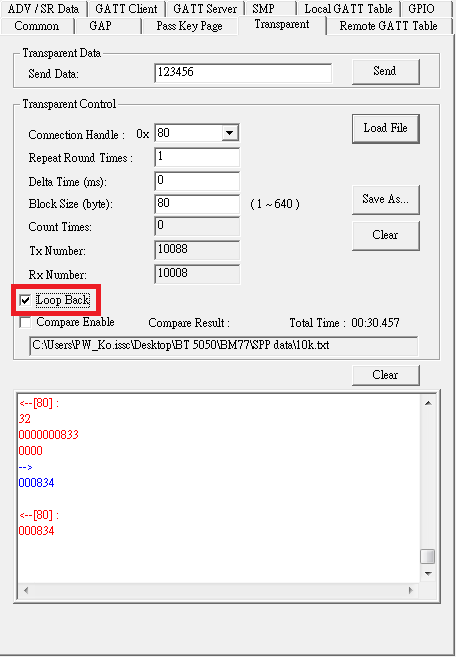
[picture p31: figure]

Figure 5.3.3 Send data with loopback mode

## 5.4 ADV / SR Data Editor

1. Edit the advertising data and the scan response data.
2. Save / update ADV data.

### 5.4.1 Edit the advertising data and the scan response data

The data setting is the same with the BLEDK3 UI tool, users can edit the Service UUID、Local name、Flag and Manufacture Data.

Figure 5.4.1 ADV/SR data editor

### 5.4.2 Save as a file

Press [Save As…] to save the setting as a file. The file can be reused next time by [Load File]. This step is optional.

### 5.4.3 Update ADV data

Press [Update] to update the ADV/SR data and start advertising automatically.

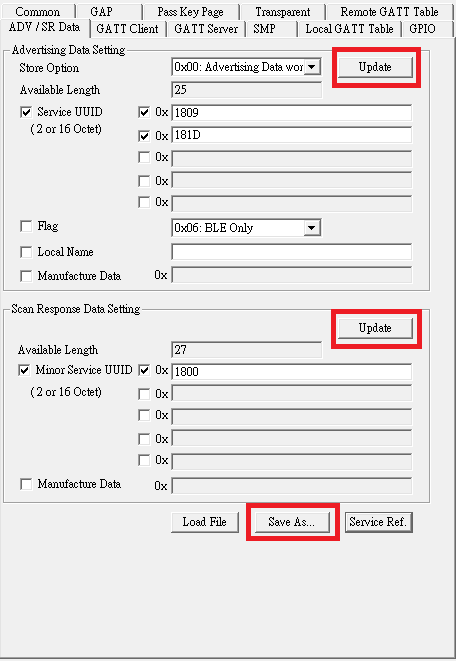
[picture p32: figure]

Figure 5.4.2 Update ADV/SR data

## 5.5 Pairing

### 5.5.1 Pairing Mode

There are 4 pairing mode: JustWork、Passkey Entry、User Confirm and Passkey Confirm ，but MCU just needs to take care of Passkey Entry and User Confirm only.

- Passkey Entry Request

MCU needs to send the passkey after receiving the following message.

Figure 5.5.1 Passkey entry request message

  - Send Pass Key

Press Enter button after entering the passkey.

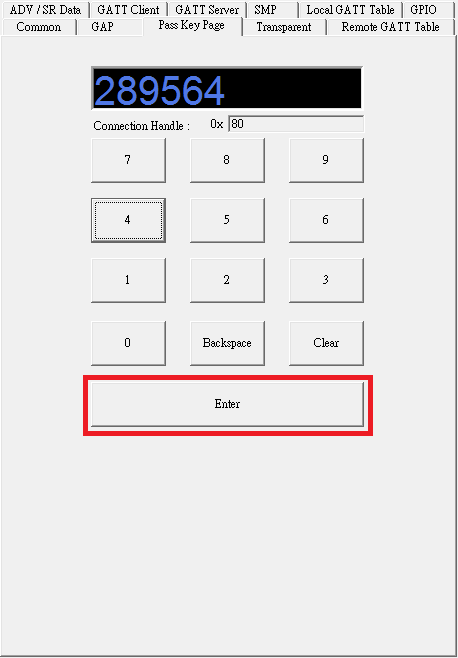
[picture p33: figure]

Figure 5.5.2 Send passkey

- Passkey Confirm Request

MCU need to send passkey confirm after receiving the following message.

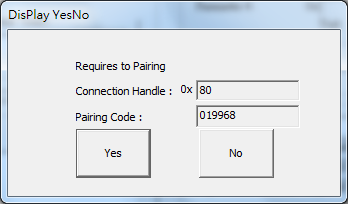
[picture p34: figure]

Figure 5.5.3 Passkey confirm request message

### 5.5.2 Pairing Mode Setting

- Read Pairing Mode
1. Select the [Common] Page.
2. Choose the command (0x0A: Read Pairing Mode Setting).
3. Press the [Send] button to read the pairing mode.

Figure 5.5.4 Read pairing mode

- Write Pairing
1. Select the [Common] Page.
2. Choose the command (0x0B: Write Pairing Mode Setting).
3. Select [Pairing Mode]
4. Press the [Send] button to disconnect the connection.

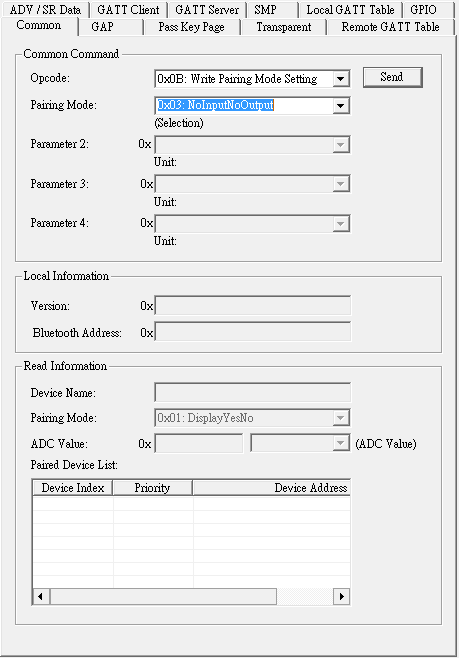
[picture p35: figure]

Figure 5.5.5 Write pairing mode

### 5.5.3 Paired Device Information

- Read Pairing Data
1. Select the [Common] Page.
2. Choose the command (0x0C: Read All Paired Device Information).
3. Press the [Send] button to read all paired device information.

Figure 5.5.6 Read paired device information

- Erased Pairing Data

There two command to erase the paired device information saved in BLEDK3 eFlash.

  - Delete Paired Device
1. Select the [Common] Page.
2. Choose the command (0x0D: Delete Paired Device).
3. Choose the index of the paired device you want to remove.
4. Press the [Send] button to delete the paired device by index.

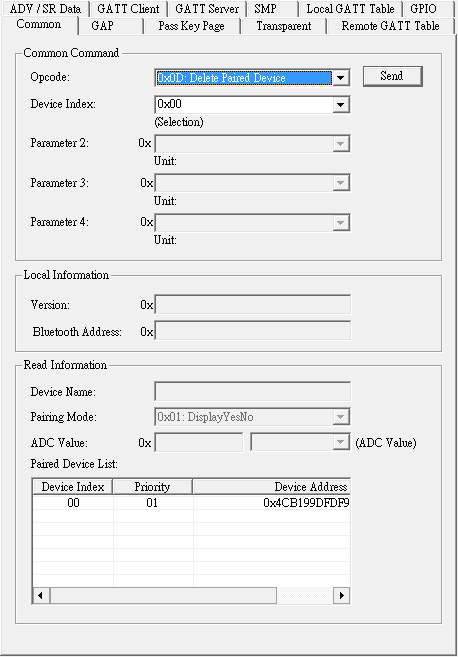
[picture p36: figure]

Figure 5.5.7 Delete paired device

  - Delete all Paired Devices
1. Select the [Common] Page.
2. Choose the command (0x09: Erase All Paired Device Information).
3. Press the [Send] button to erase all paired devices.

Figure 5.5.8 Delete all paired device

### 5.5.4 Pairing Complete

When the pairing process is finished, MCU will receive a paining complete event from BLEDK3.

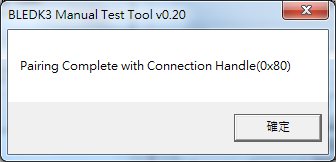
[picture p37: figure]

Figure 5.5.9 Pairing complete message

## 5.6 Get Remote GATT Table

When the connection is established, the client can ask the service from the server.

1. Select the [Remote GATT Table] Page.
2. Press the [Get Remote GATT Table] button.

Figure 5.6.1 Get remote GATT table

## 5.7 Get Local GATT Table and Specific service

The server can ask the service from local, and if server support [Weight Scale]、[Heart Rate]、[Health Thermometer]、[Blood Pressure] or [Glucose], after get Local GATT Table the Manual Pattern Test Tool will show specific service page.

1. Select the [Local GATT Table] Page.
2. Press the [Get Local GATT Table] button.

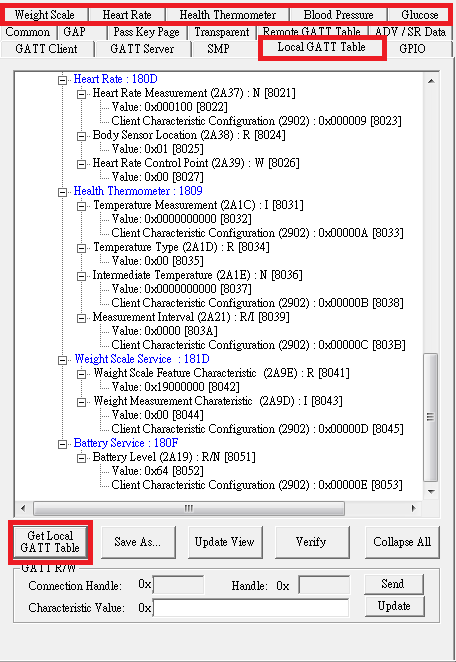
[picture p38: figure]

Figure 5.7.1 Get local GATT table

### 5.7.1 Weight Scale Service

The Weight Scale Service exposes weight and related data from a weight scale (Server) intended for consumer healthcare as well as sports/fitness applications.

Figure 5.7.2 Weight scale service view

1. Demo Weight Scale Service.

2. Indicate Battery Level Characteristics

3. Read Battery Level Characteristics.

4. Read Weight Scale Feature Characteristics.

5. Indicate Weight Measurement Characteristics.

### 5.7.2 Heart Rate Service

The HEART RATE Service exposes heart rate and other data related to a heart rate sensor intended for fitness applications.

Figure 5.7.3 Heart rate service view

1. Demo Heart Rate Service.

2. Read Body Sensor Location Characteristics.

3. Indicate Heart Rate Measurement Characteristics.

### 5.7.3 Health Thermometer Service

The Health Thermometer service exposes temperature and other data from a thermometer intended for healthcare and fitness applications.

Figure 5.7.4 Health thermometer service view

1. Demo Health Thermometer Service.

2. Read Temperature Type Characteristics.

3. Read Measurement Interval Characteristics.

4. Indicate Measurement Interval Characteristics.

5. Indicate Intermediate Temperature Characteristics.

6. Indicate Temperature Measurement Characteristics.

### 5.7.4 Blood Pressure Service

The Blood Pressure Service exposes blood pressure and other data related to a blood pressure monitor.

Figure 5.7.5 Blood pressure service view

1. Demo Blood Pressure Service.

2. Read Blood Pressure Feature Characteristics.

3. Choose indicate Blood Pressure Measurement Characteristics or Intermediate Cuff Pressure Characteristics.

### 5.7.5 Glucose Service

The Glucose Service exposes glucose and other data related to a glucose sensor for consumer and professional healthcare applications.

Figure 5.7.6 Glucose service view

1. Demo Glucose Service.

2. Glucose Measurement Characteristics.

3. Glucose Feature Characteristics.

4. Glucose Measurement Context Characteristics,

5. Record Access Control Point Characteristics.

- Glucose Measurement Characteristics

Figure 5.7.7 Glucose measurement characteristics

- Glucose Feature Characteristics

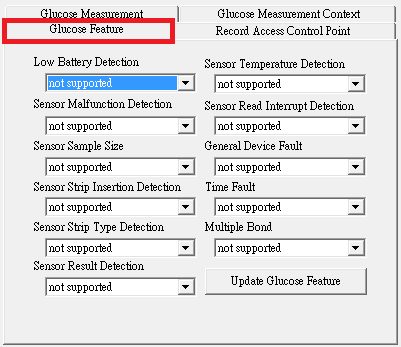
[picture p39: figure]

Figure 5.7.8 Glucose feature characteristics

- Glucose Measurement Context Characteristics

Figure 5.7.9 Glucose Measurement context characteristics

- Record Access Control Point Characteristics

Figure 5.7.10 Record access control point chatacteristics

1. Display received Record Access Control Point command.

2. Indicate the Record Access Control Point with stored records.

3. Indicate the Record Access Control Point with number of stored records.

4. Indicate the Record Access Control Point with a Response Code Op Code and Response Code Value.

# 6. Revision History

Version | Date | History
D026R01 | 2015/03/31 | First Edition of BLEDK3 Manual Pattern Tool User Guide

BLEDK3 Manual Pattern Tool User Guide

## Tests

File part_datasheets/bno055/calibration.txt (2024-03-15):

https://www.youtube.com/watch?v=Bw0WuAyGsnY

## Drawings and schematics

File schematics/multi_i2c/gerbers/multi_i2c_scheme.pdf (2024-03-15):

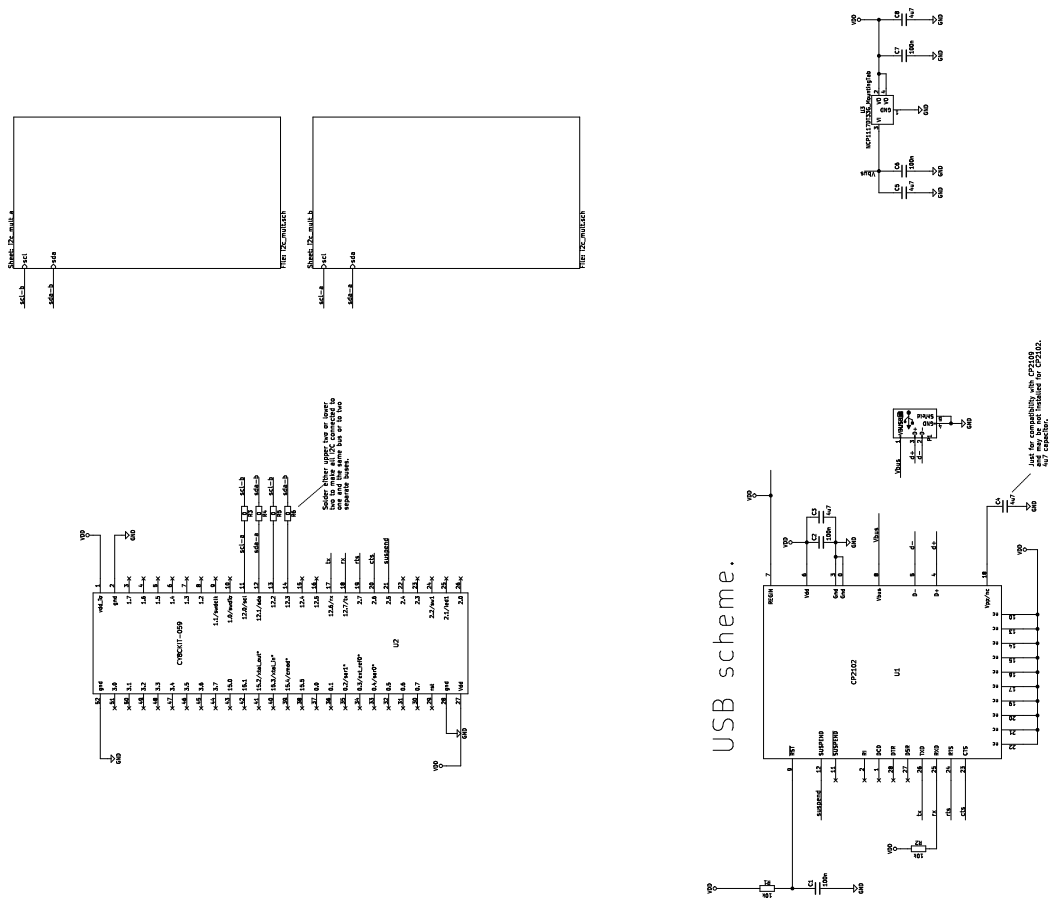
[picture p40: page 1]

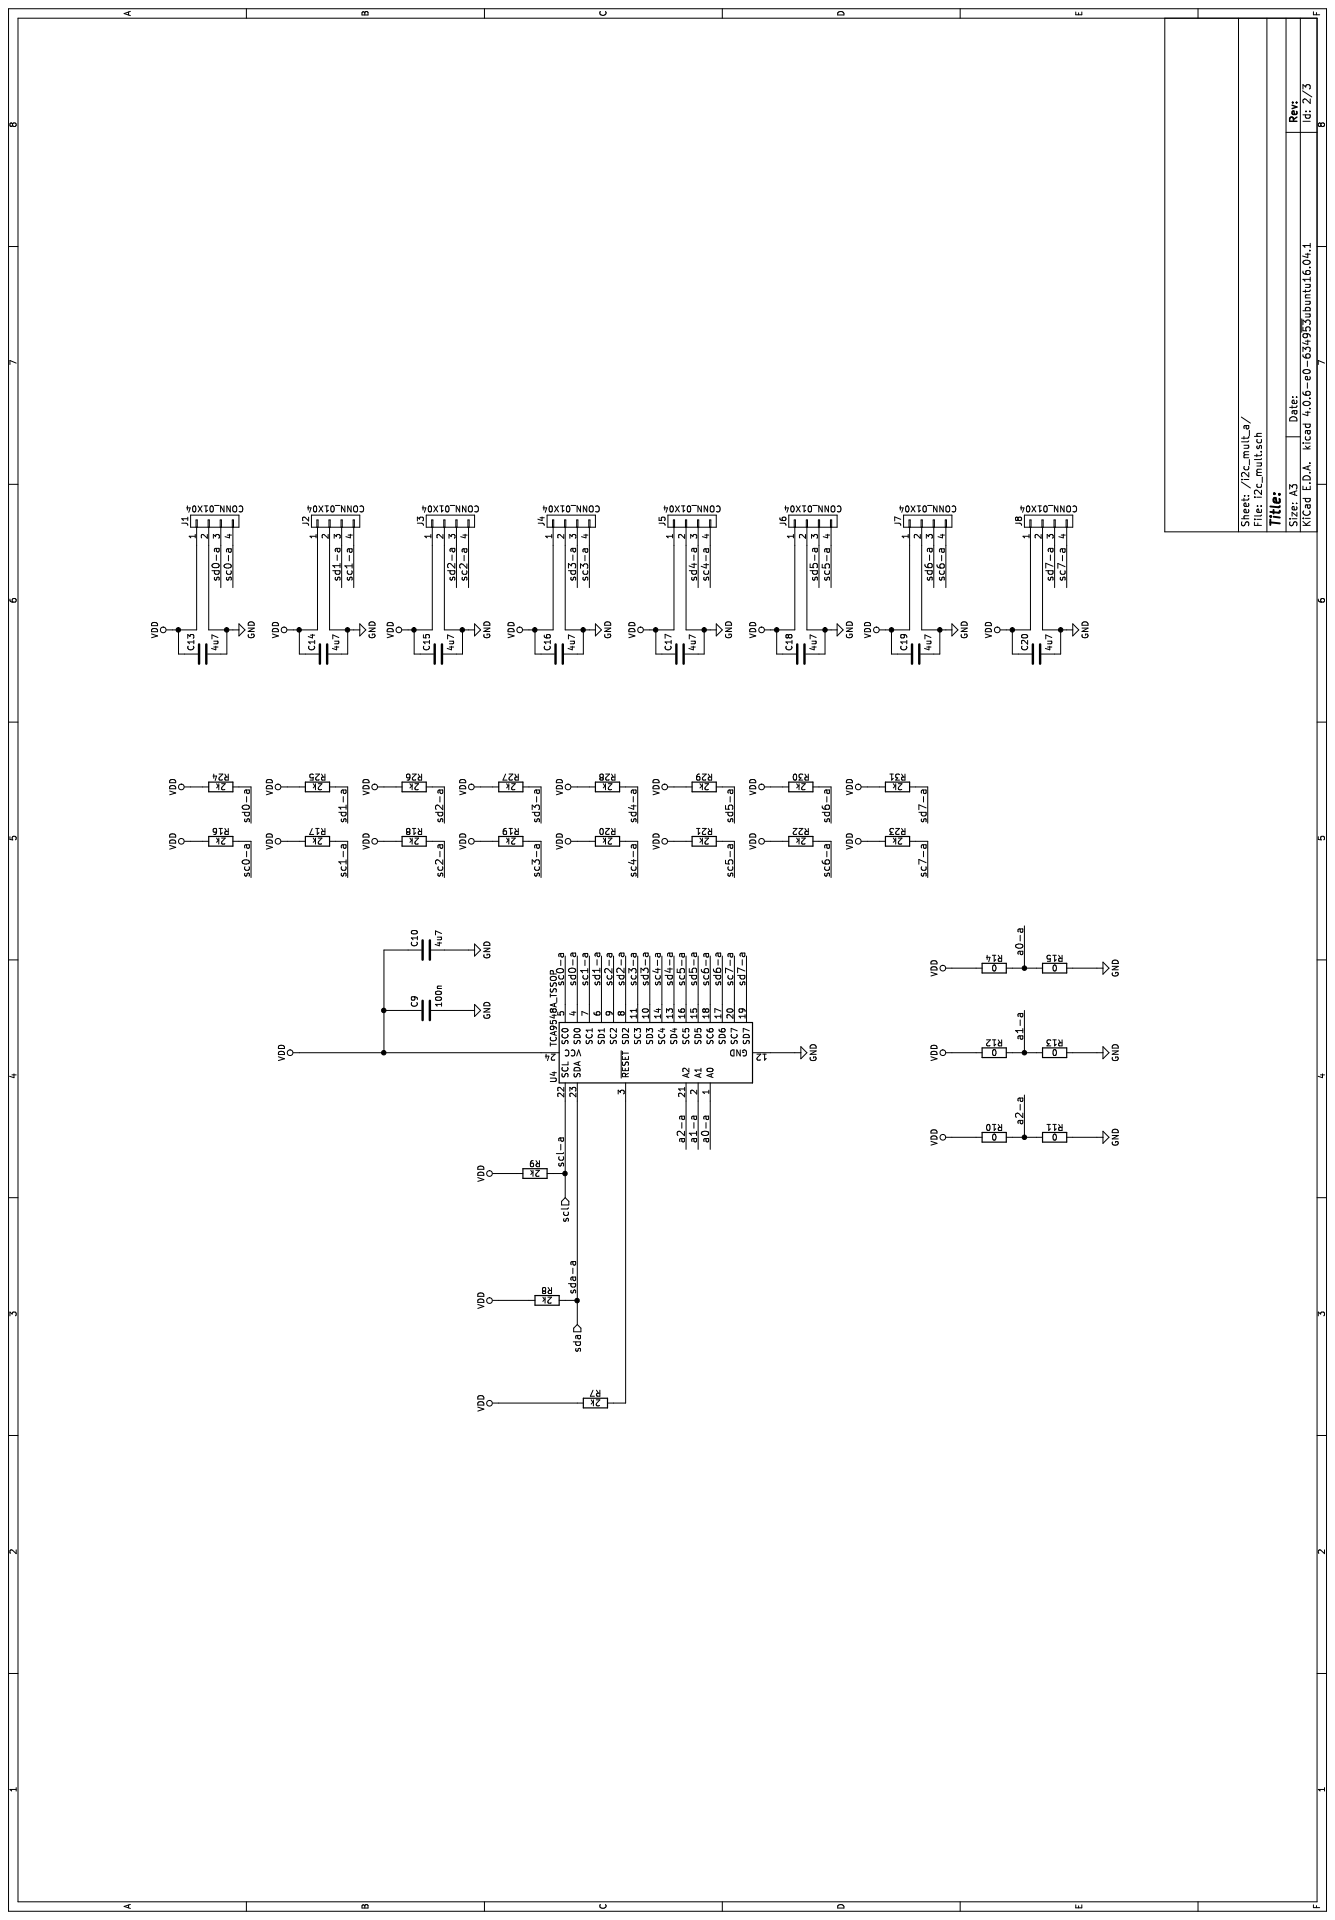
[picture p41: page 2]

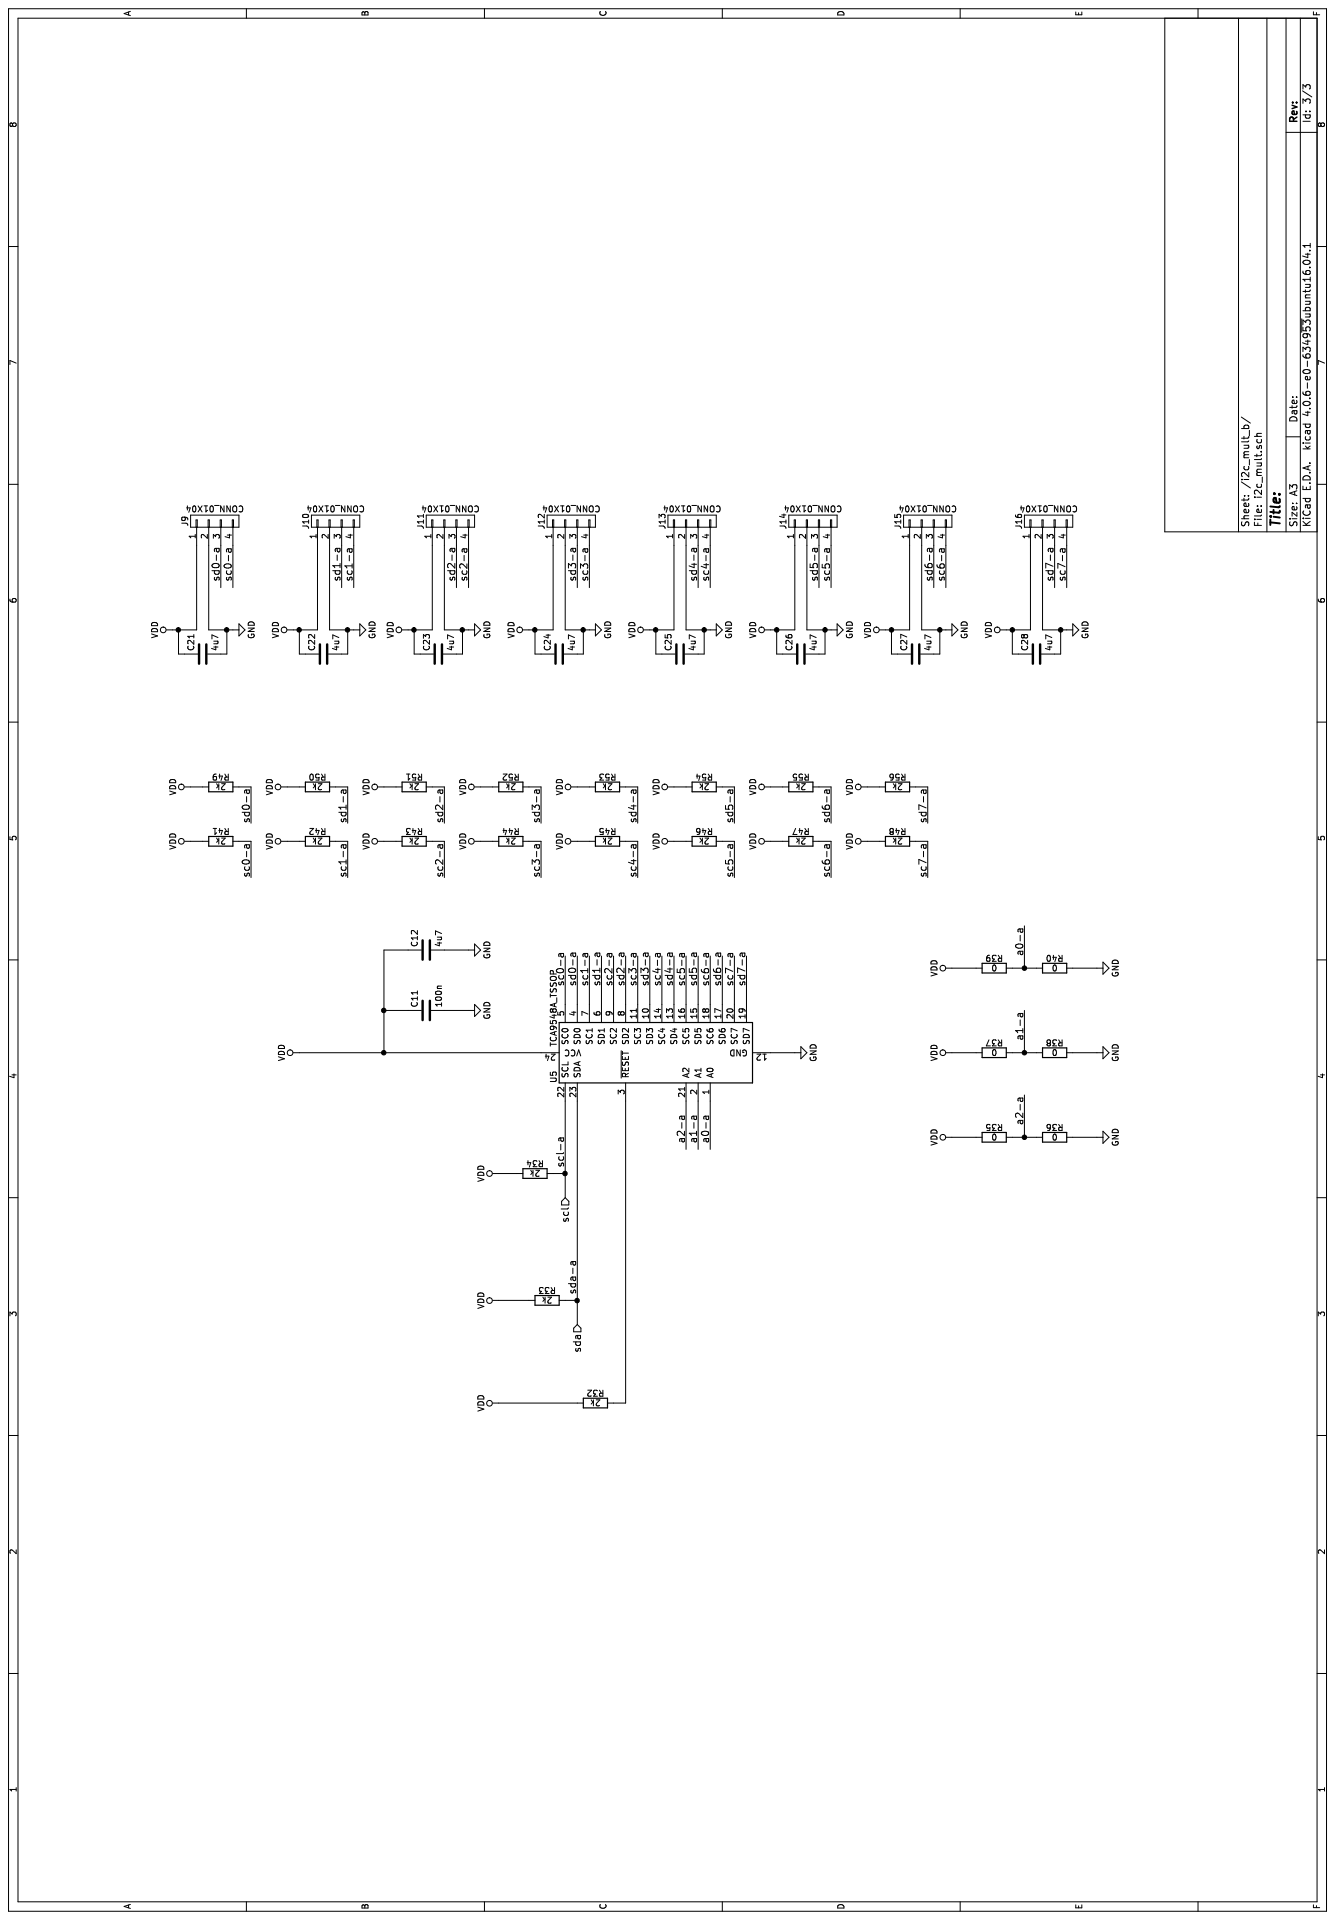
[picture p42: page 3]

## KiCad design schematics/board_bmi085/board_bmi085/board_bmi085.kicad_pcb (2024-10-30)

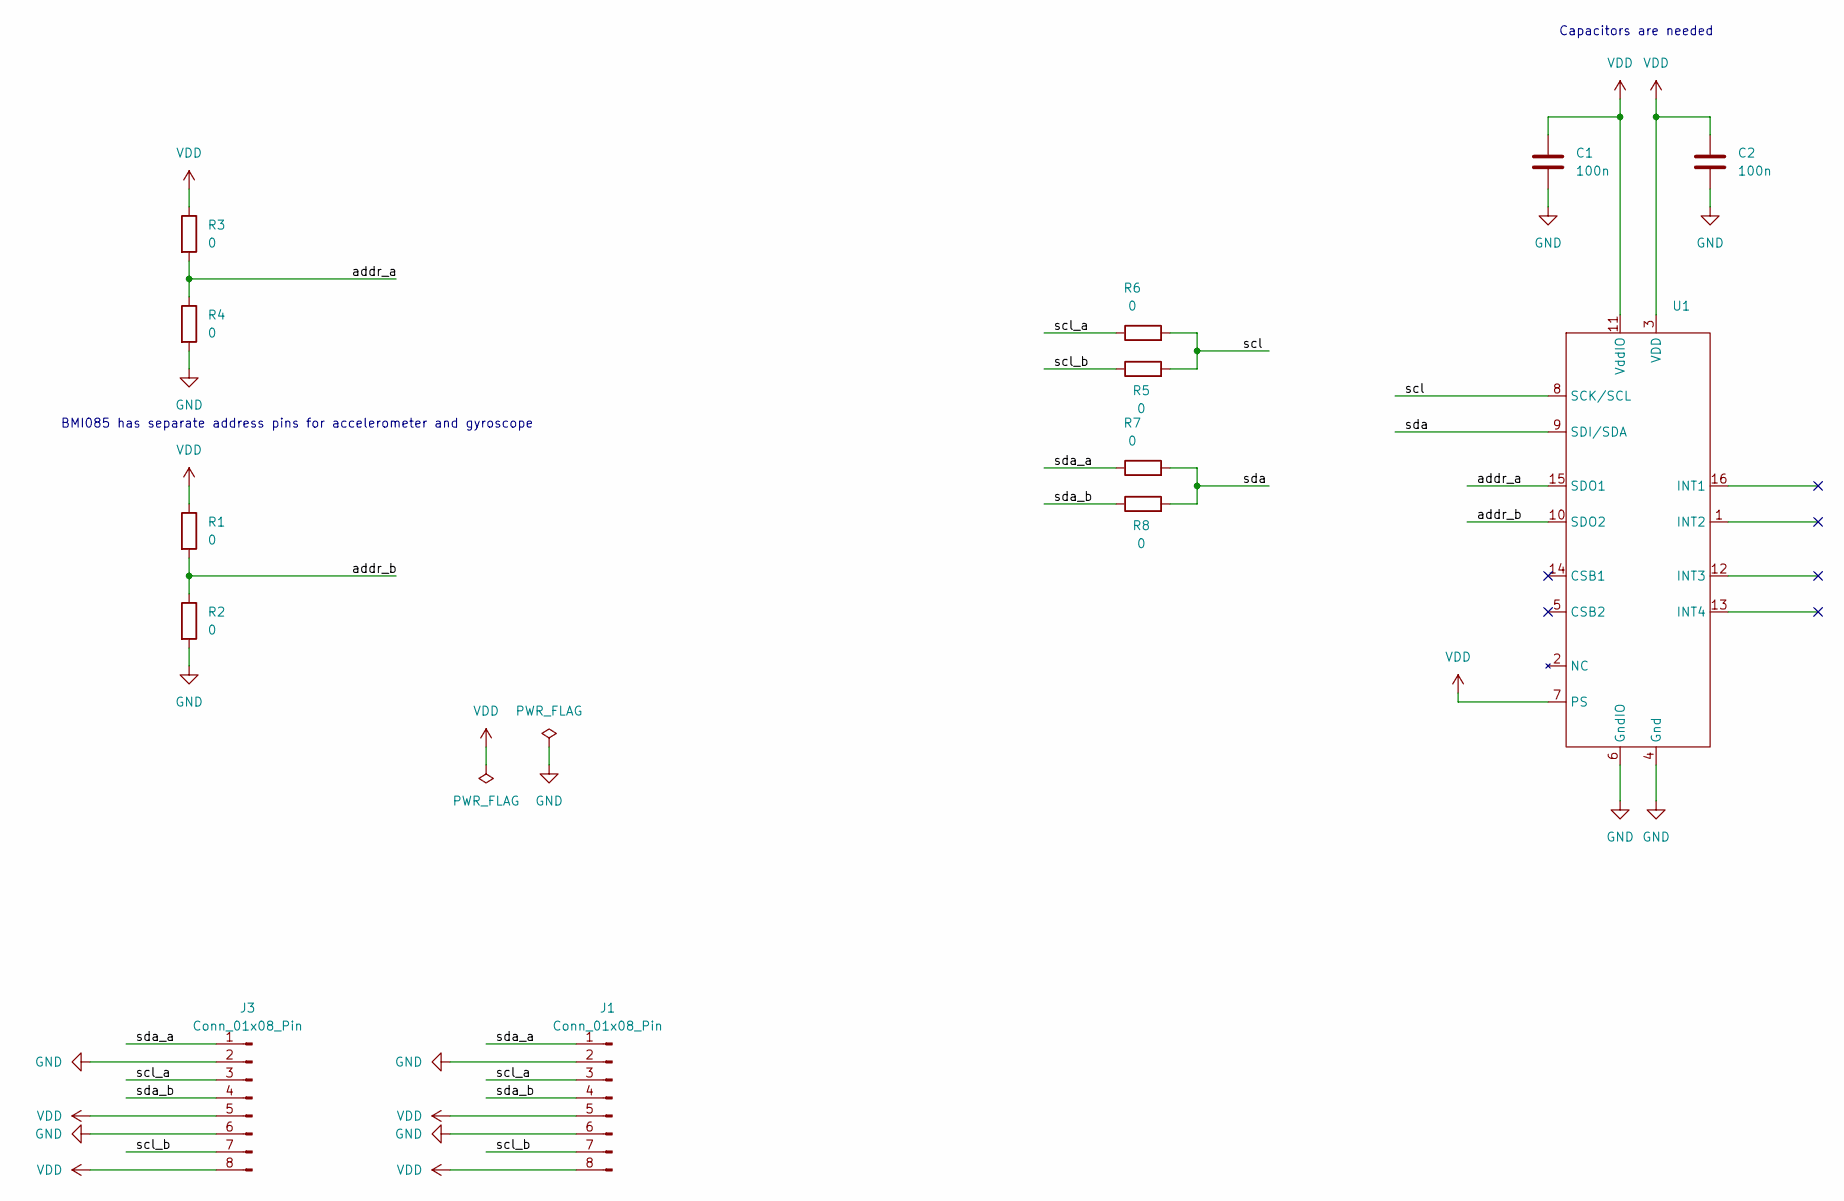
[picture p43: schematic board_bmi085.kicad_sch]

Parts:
C1, C2: 100n; C_0603_1608Metric
J1, J3: Conn_01x08_Pin; PinHeader_1x08_P1.27mm_Vertical
R1, R2, R3, R4, R5, R6, R7, R8: 0; R_0402_1005Metric
U1: BMI085

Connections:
/addr_a: R3.2, R4.1, U1.15 (SDO1)
/addr_b: R1.2, R2.1, U1.10 (SDO2)
/scl: R5.2, R6.2, U1.8 (SCK/SCL)
/scl_a: J1.3, J3.3, R6.1
/scl_b: J1.7, J3.7, R5.1
/sda: R7.2, R8.2, U1.9 (SDI/SDA)
/sda_a: J1.1, J3.1, R7.1
/sda_b: J1.4, J3.4, R8.1
GND: C1.2, C2.2, J1.2, J1.6, J3.2, J3.6, R2.2, R4.2, U1.4 (Gnd), U1.6 (GndIO)
VDD: C1.1, C2.1, J1.5, J1.8, J3.5, J3.8, R1.1, R3.1, U1.3 (VDD), U1.7 (PS), U1.11 (VddIO)

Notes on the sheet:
Capacitors are needed
BMI085 has separate address pins for accelerometer and gyroscope

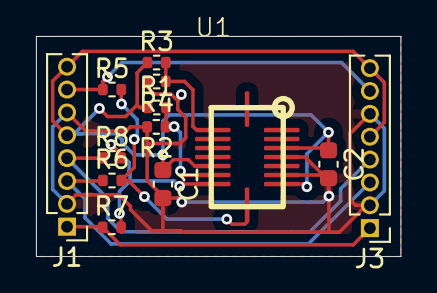
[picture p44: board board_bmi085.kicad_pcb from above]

Board: 2 copper layers, 20.2 x 12.2 mm, 13 parts (0 on the bottom side), 10 nets.

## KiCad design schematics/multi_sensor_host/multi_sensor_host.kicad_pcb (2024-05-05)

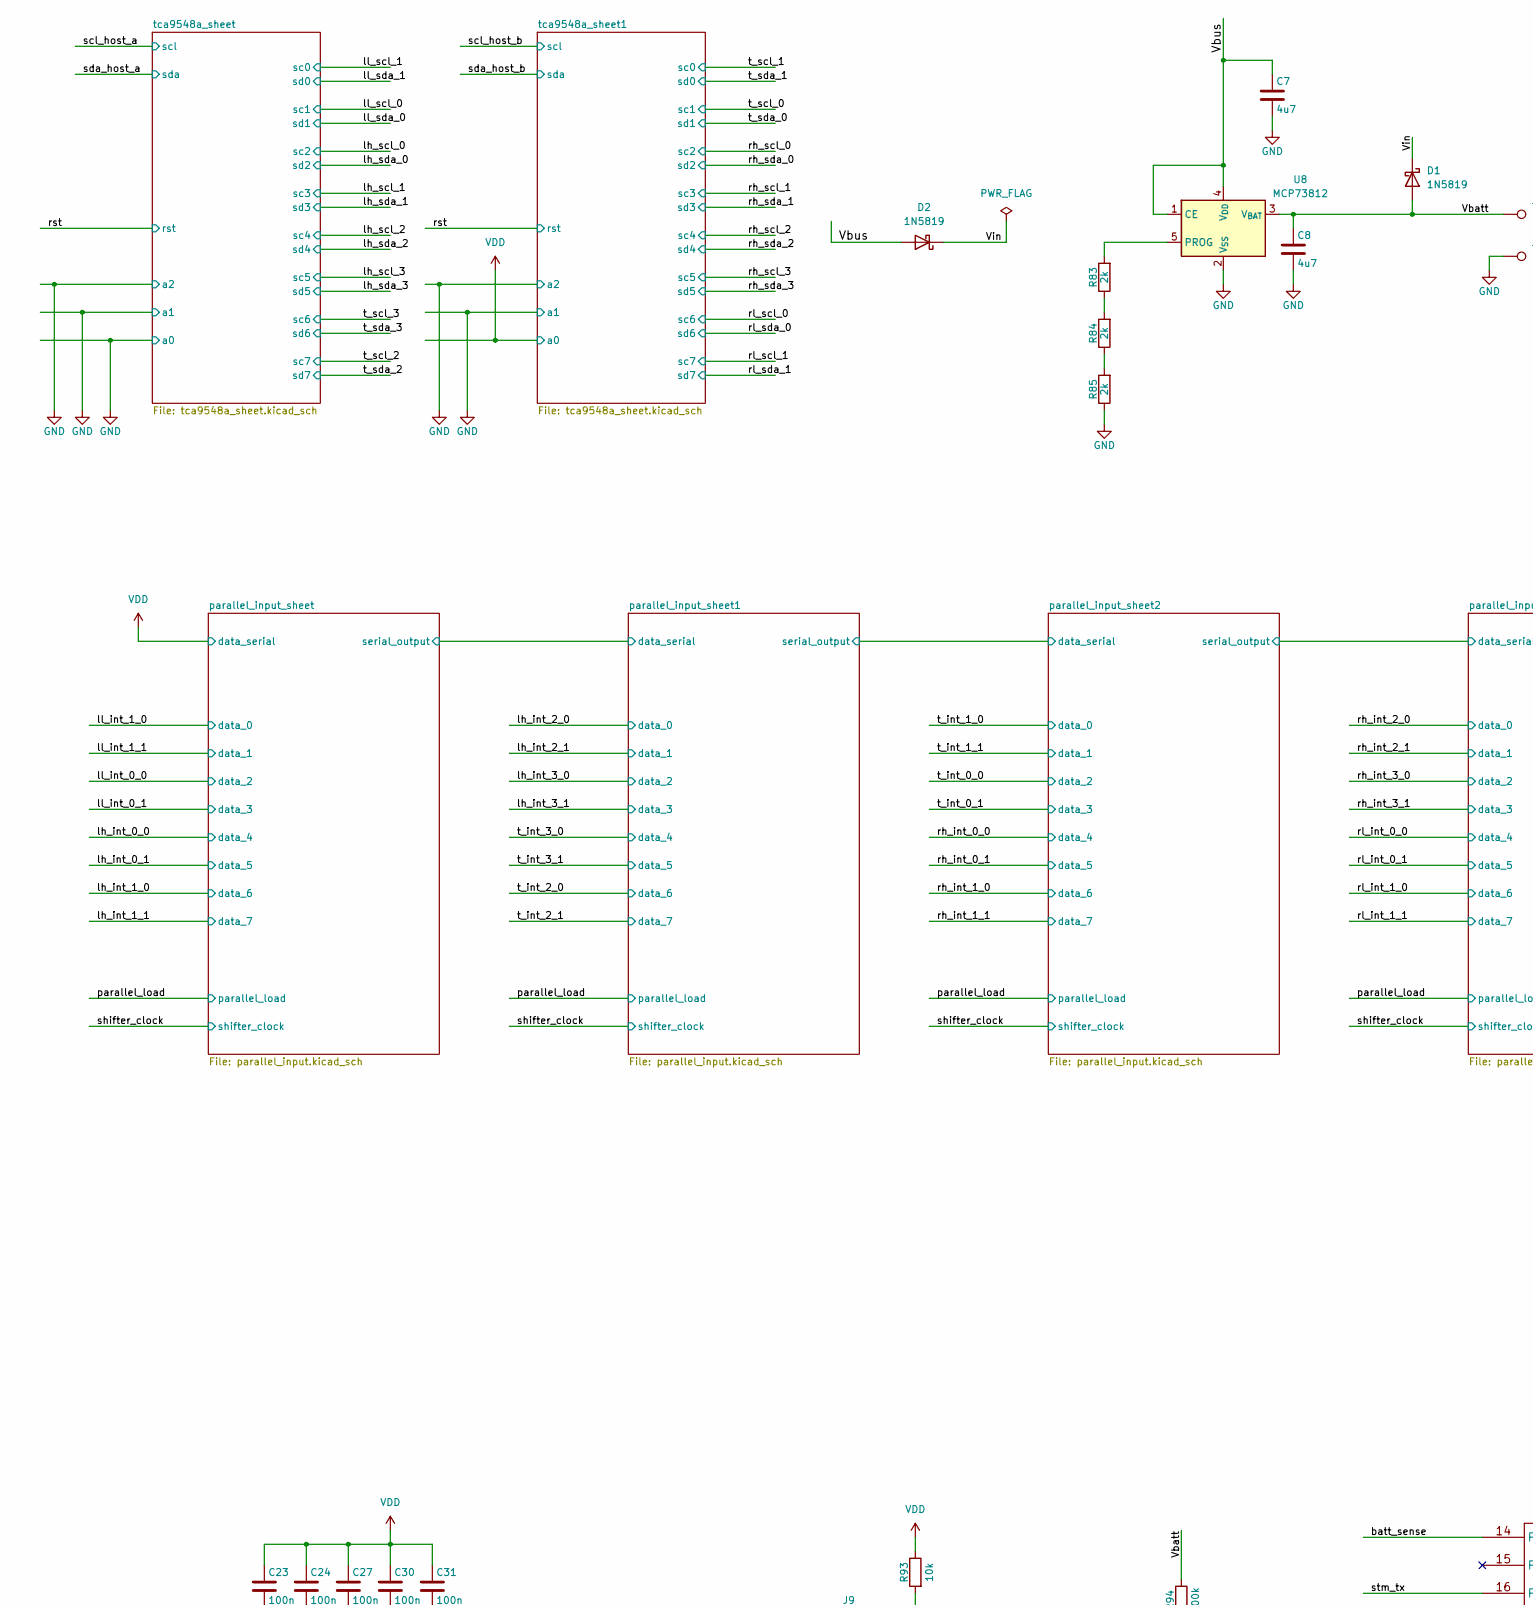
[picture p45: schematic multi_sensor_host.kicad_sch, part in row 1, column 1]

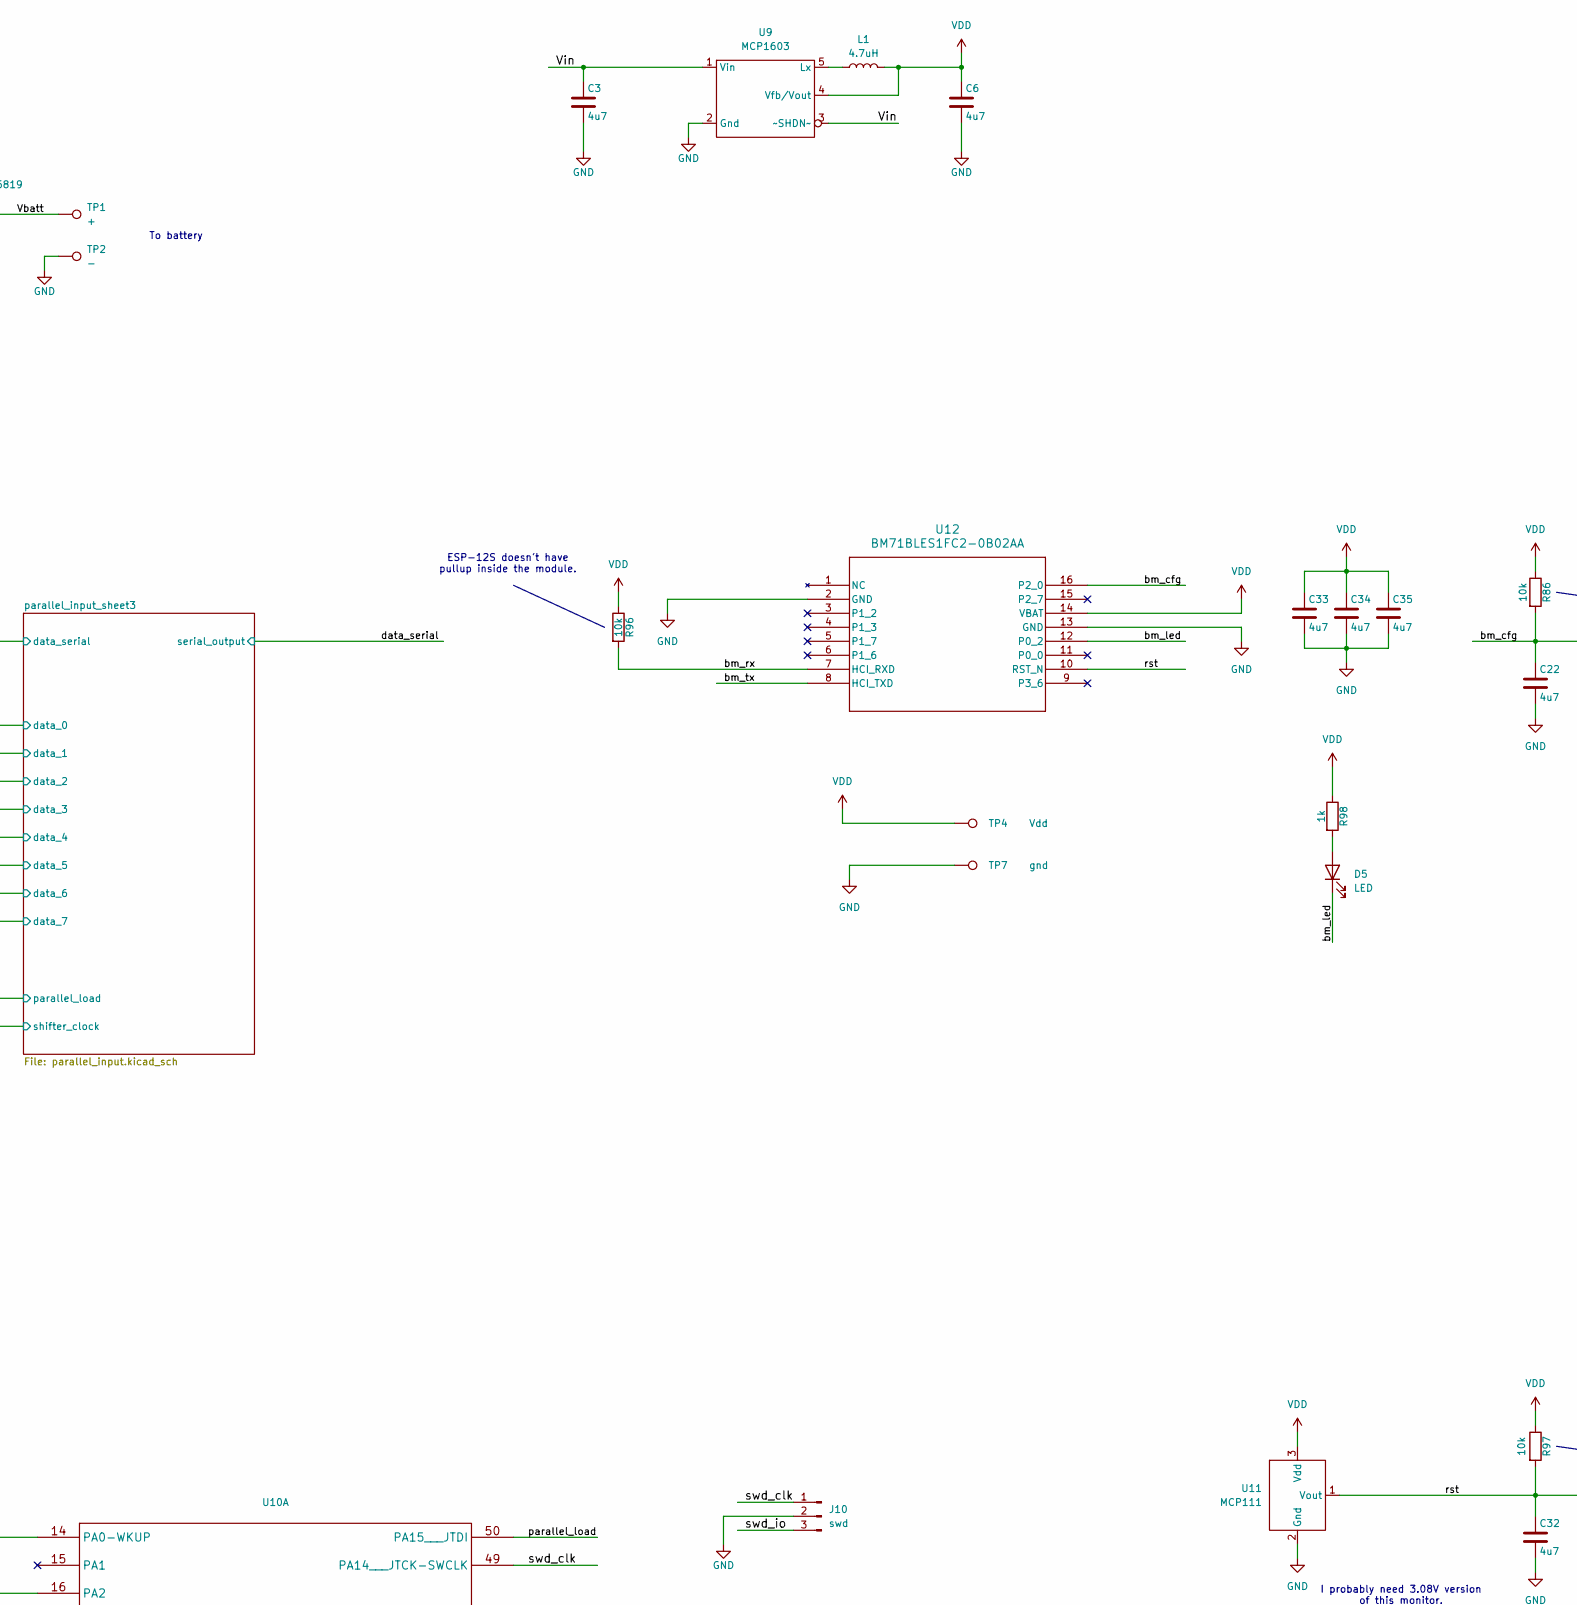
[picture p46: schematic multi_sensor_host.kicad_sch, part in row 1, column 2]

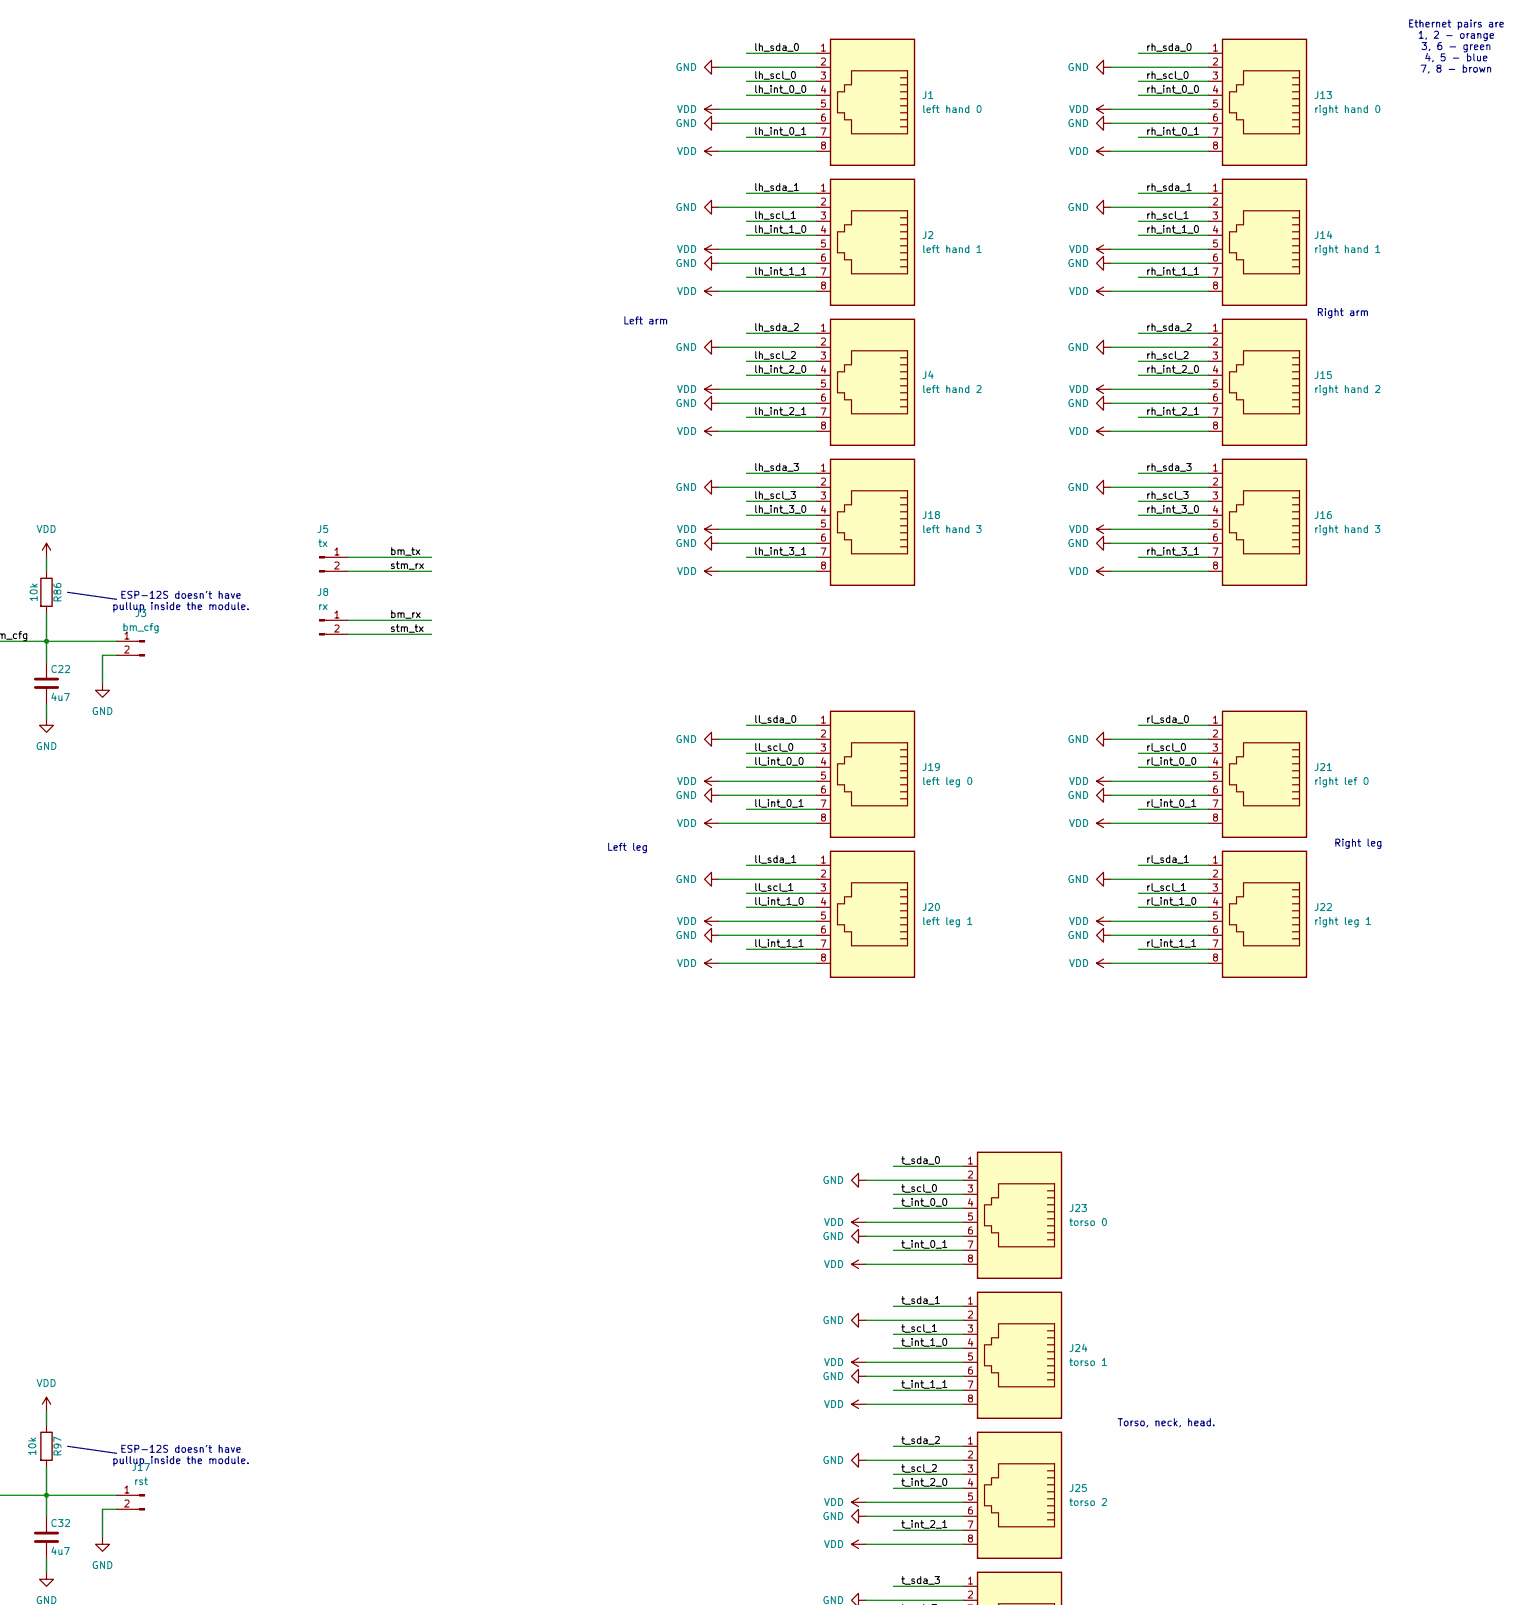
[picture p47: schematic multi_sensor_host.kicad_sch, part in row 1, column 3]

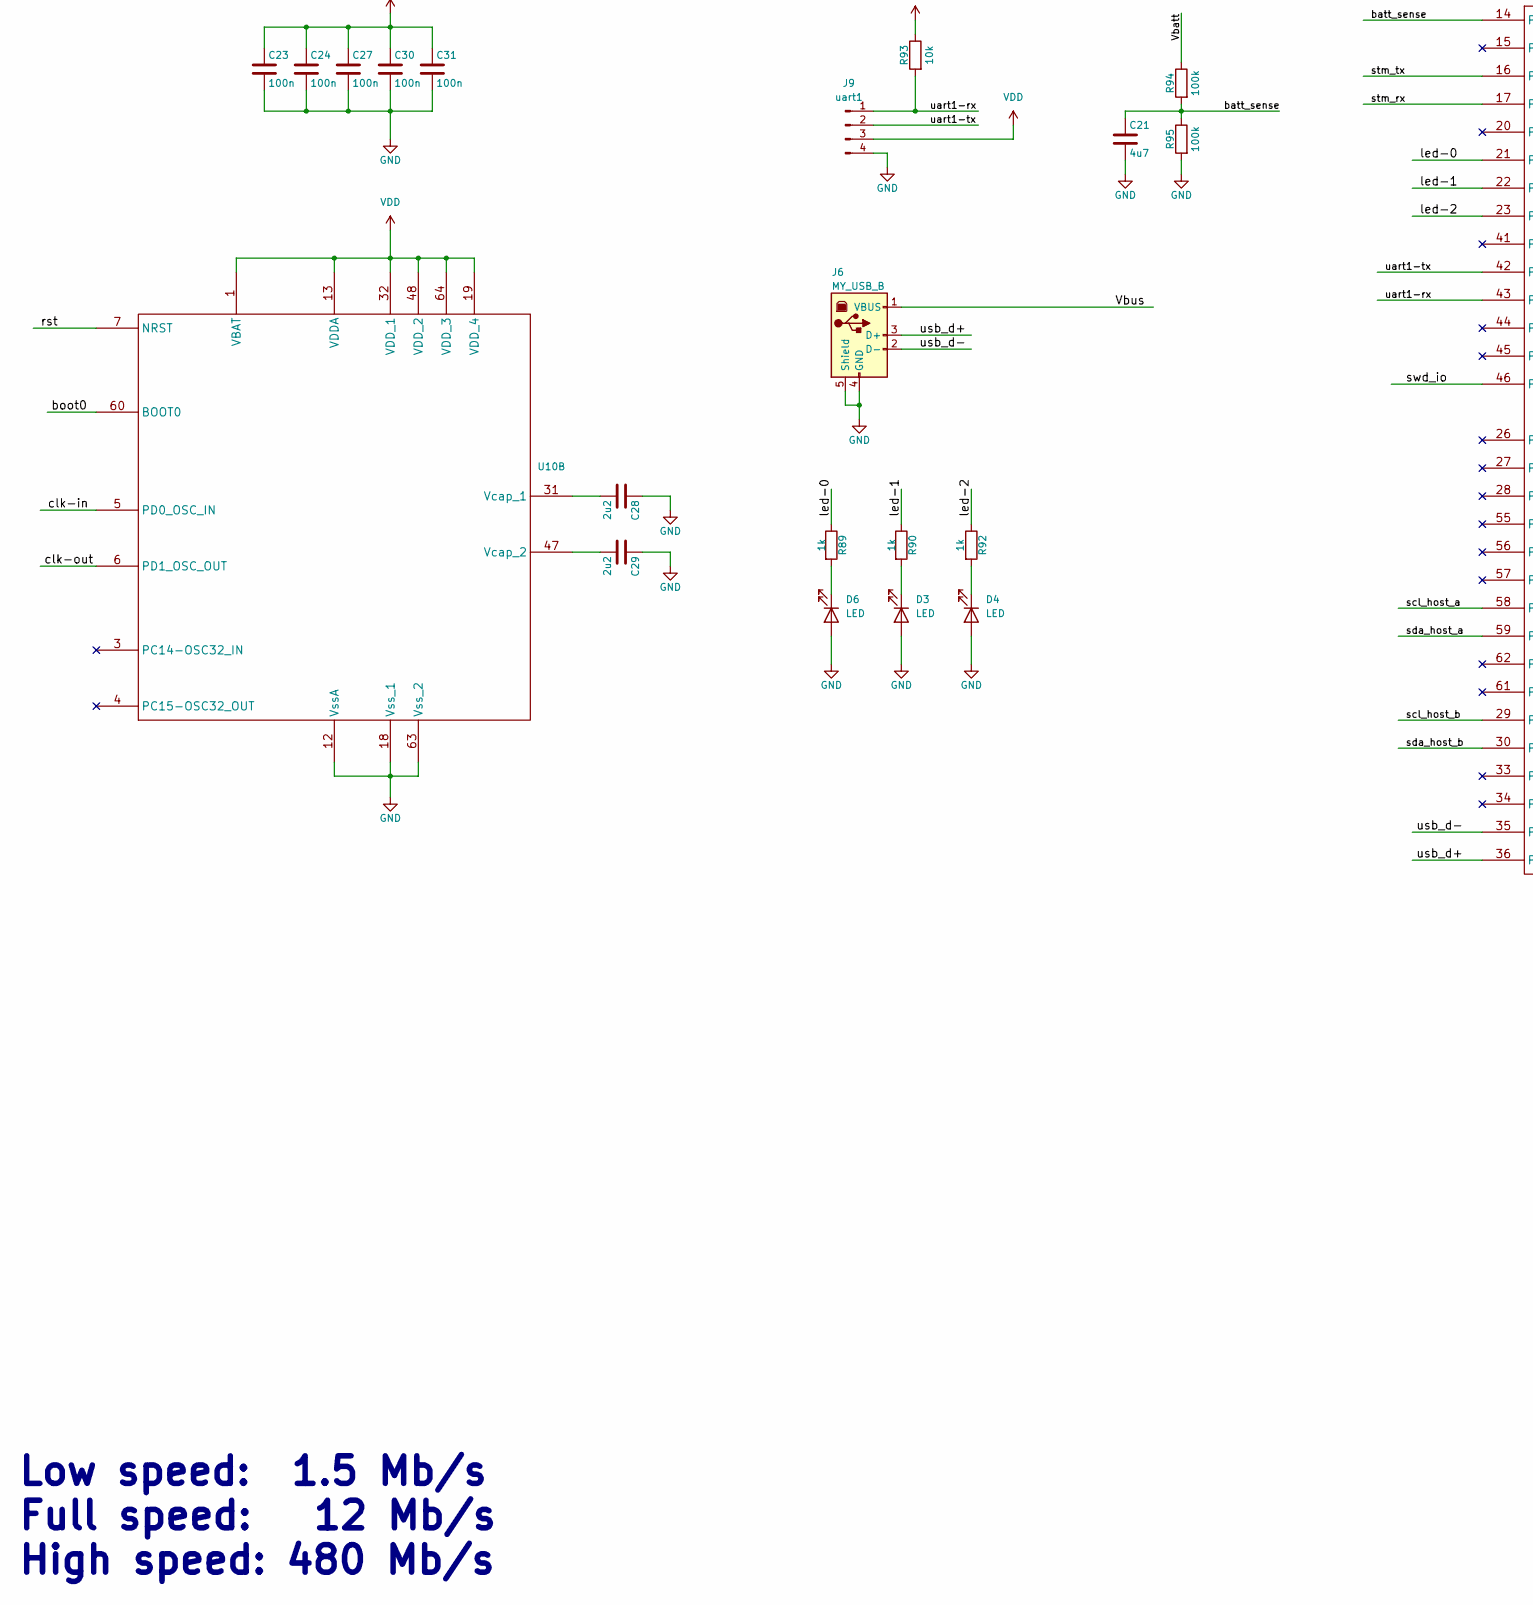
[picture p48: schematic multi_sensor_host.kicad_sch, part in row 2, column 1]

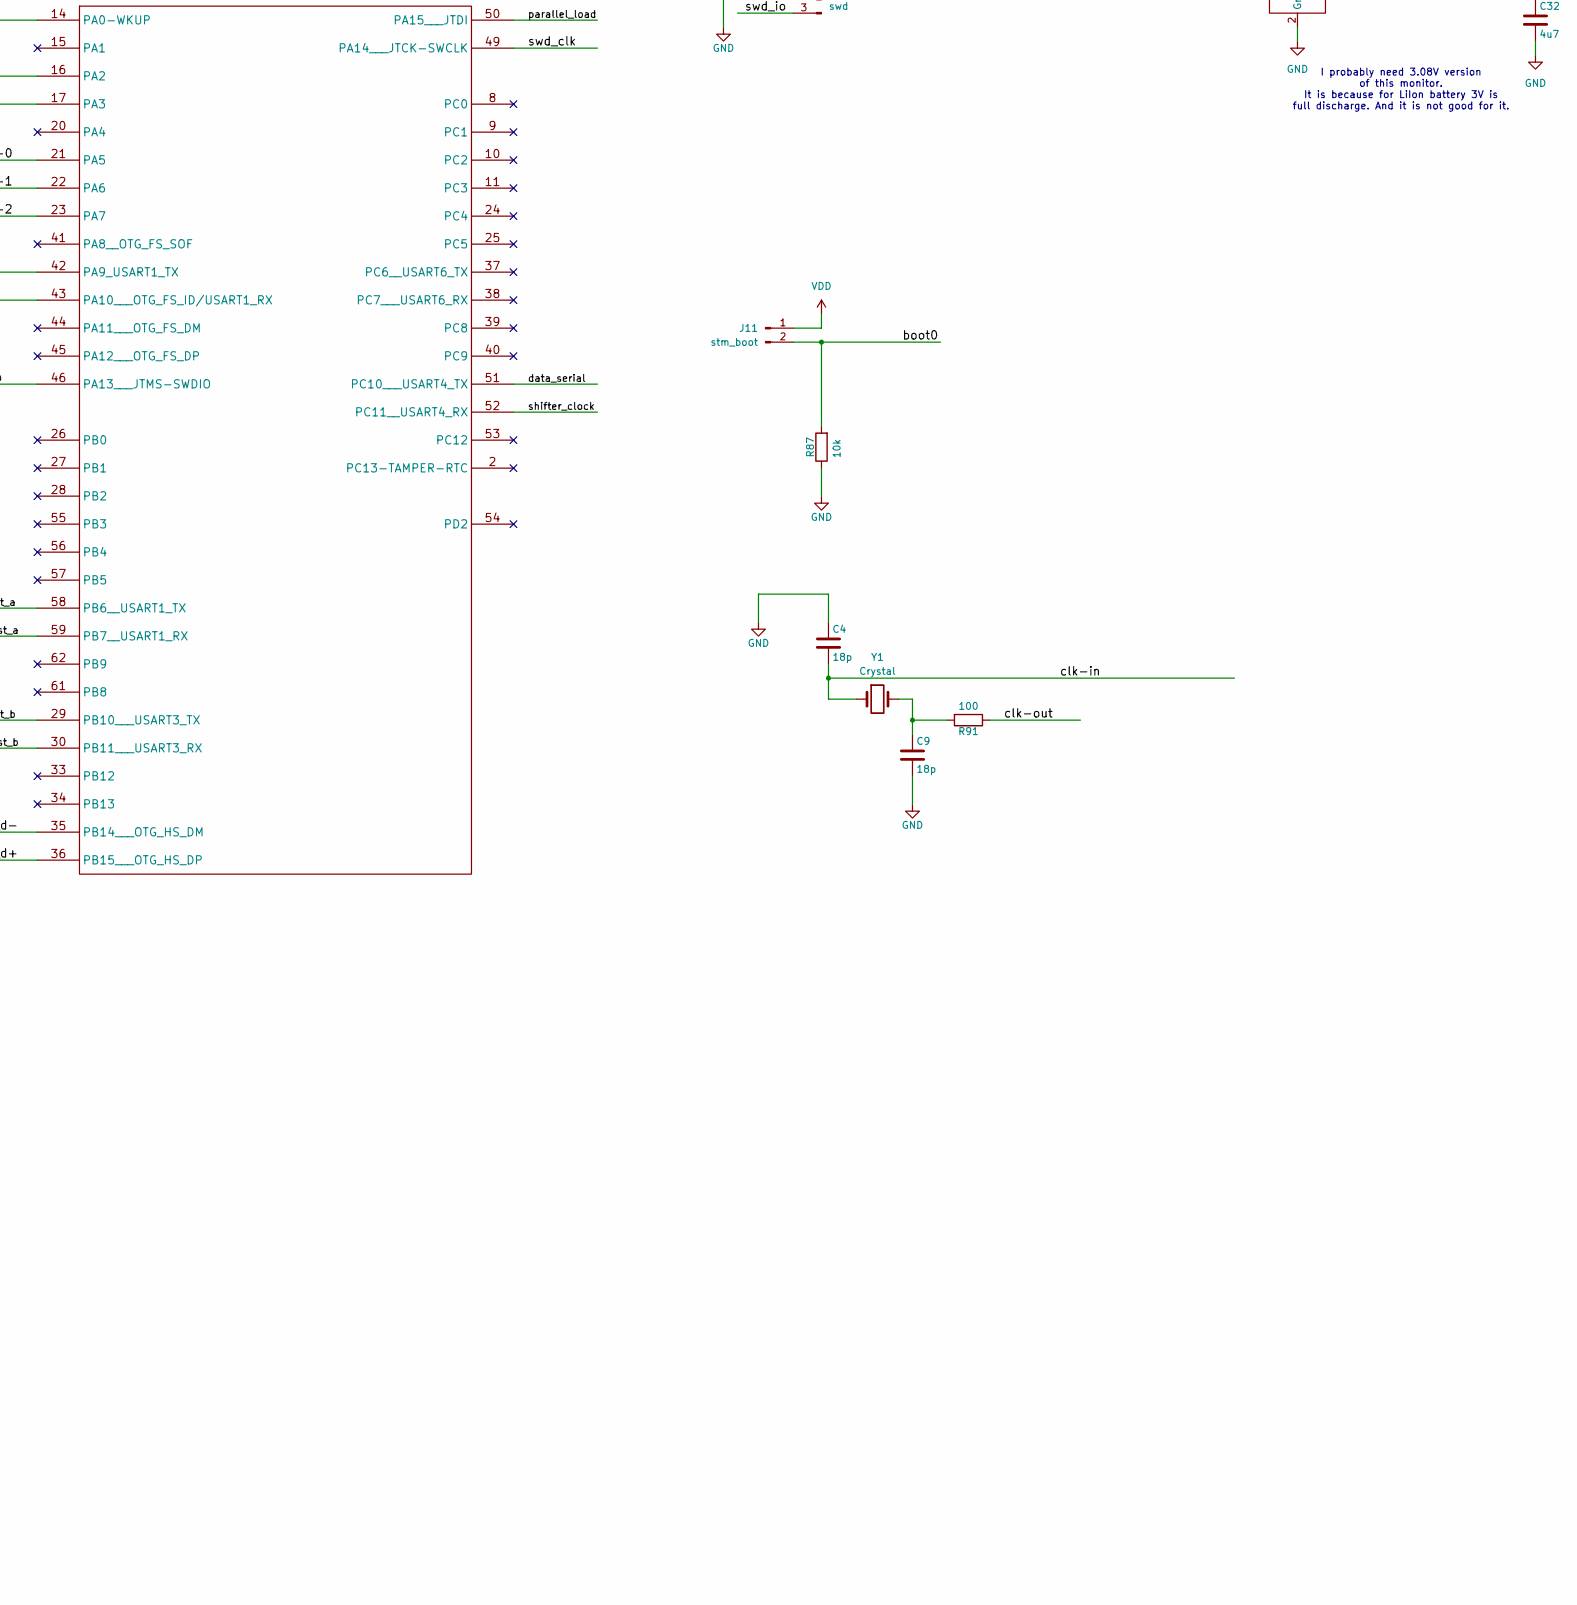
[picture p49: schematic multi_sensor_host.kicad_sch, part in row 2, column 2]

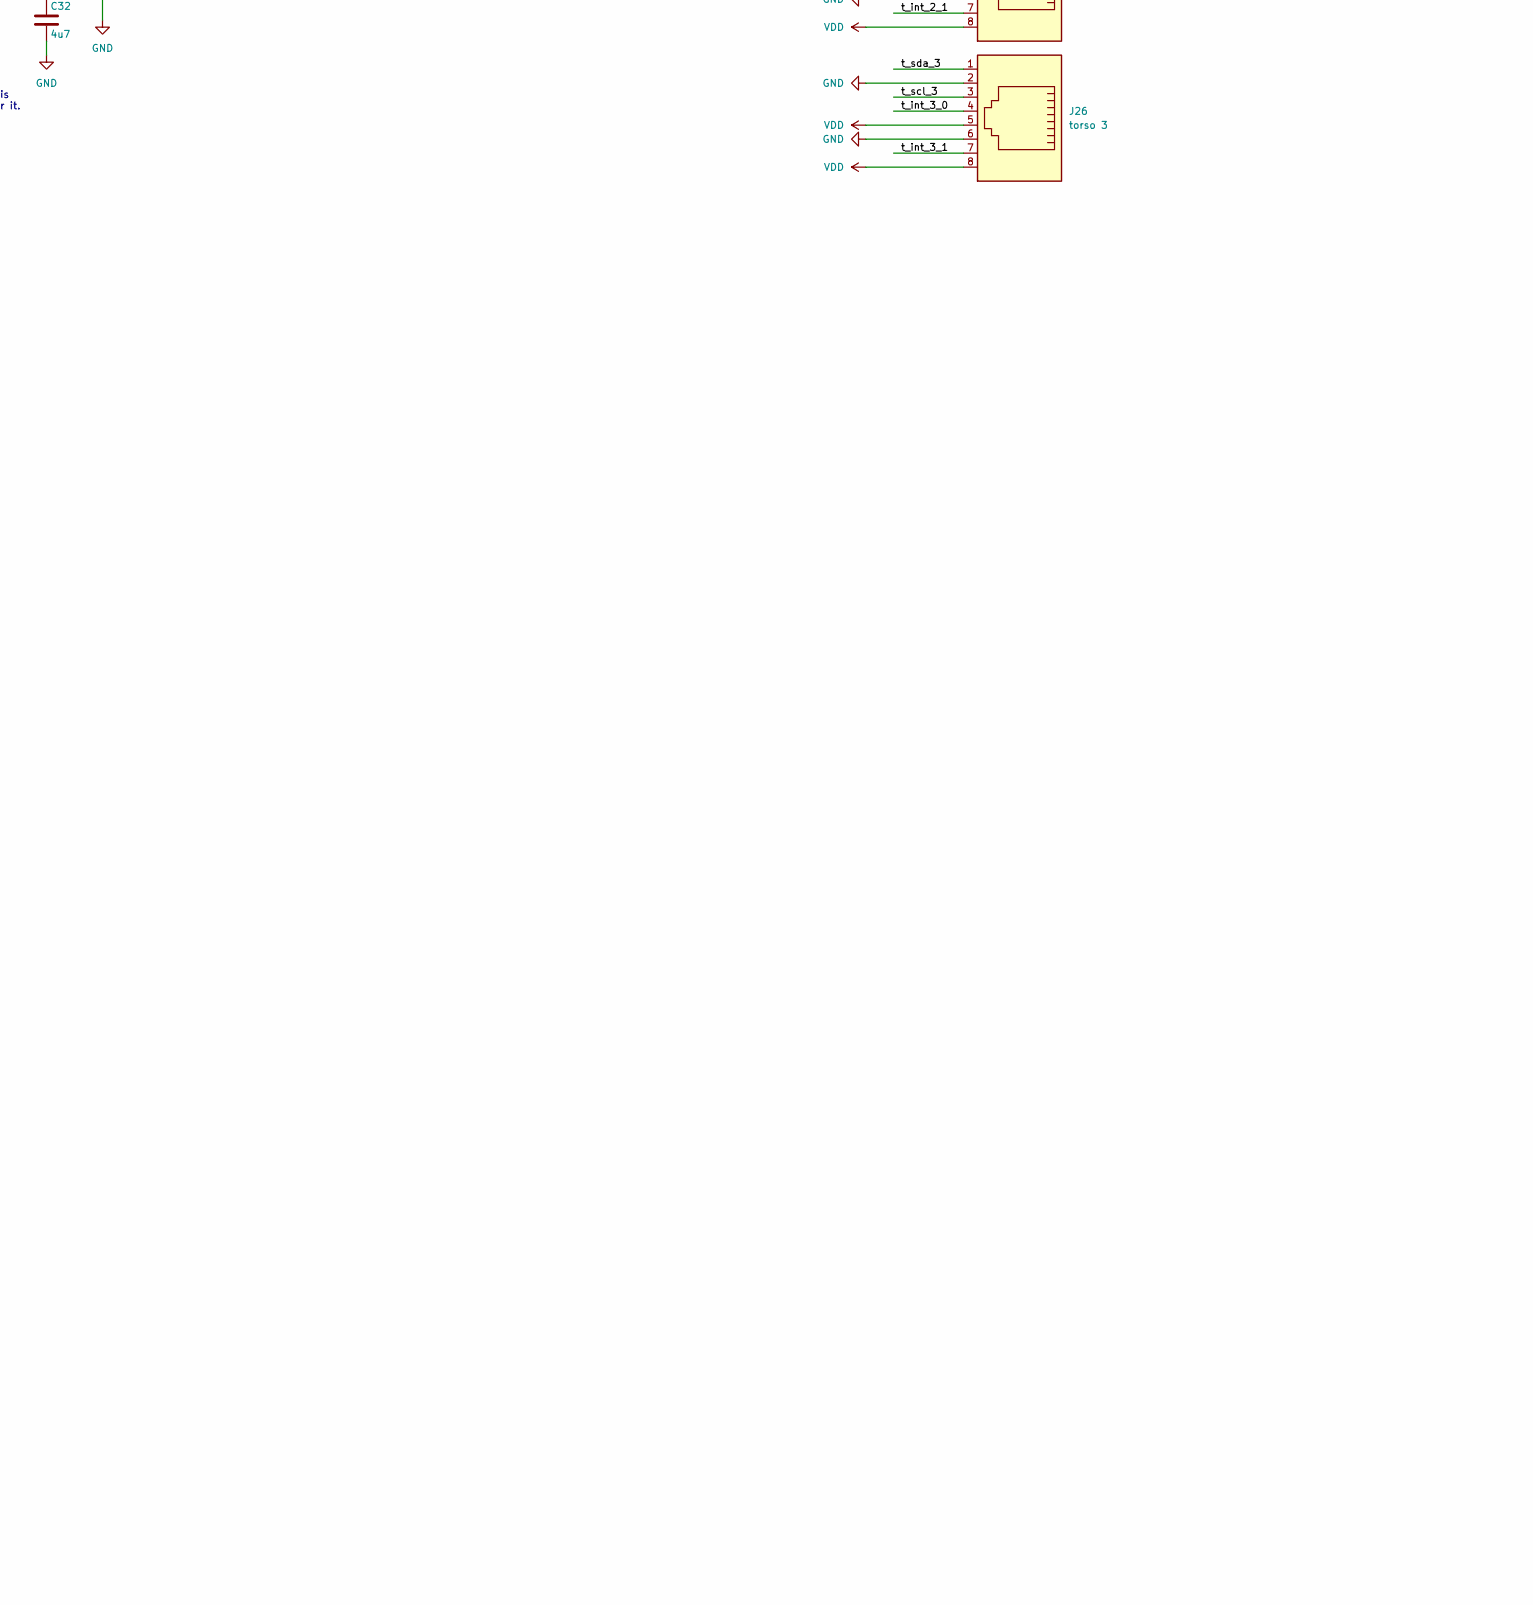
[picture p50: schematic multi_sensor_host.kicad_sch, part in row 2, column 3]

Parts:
C3, C6, C7, C8, C21, C22, C32, C33, C34, C35: 4u7; C_0603_1608Metric
C4, C9: 18p; C_0603_1608Metric
C23, C24, C27, C30, C31: 100n; C_0603_1608Metric
C28, C29: 2u2; C_0603_1608Metric
D1, D2: 1N5819; D_DO-41_SOD81_P7.62mm_Horizontal
D3, D4, D5, D6: LED; LED_D3.0mm
J1: left hand 0; RJ45_OST_PJ012-8P8CX_Vertical
J2: left hand 1; RJ45_OST_PJ012-8P8CX_Vertical
J3: bm_cfg; PinHeader_1x02_P2.54mm_Vertical
J4: left hand 2; RJ45_OST_PJ012-8P8CX_Vertical
J5: tx; PinHeader_1x02_P2.54mm_Vertical
J6: MY_USB_B; USB_B_Lumberg_2411_02_Horizontal
J8: rx; PinHeader_1x02_P2.54mm_Vertical
J9: uart1; PinHeader_1x04_P2.54mm_Vertical
J10: swd; PinHeader_1x03_P2.54mm_Vertical
J11: stm_boot; PinHeader_1x02_P2.54mm_Vertical
J13: right hand 0; RJ45_OST_PJ012-8P8CX_Vertical
J14: right hand 1; RJ45_OST_PJ012-8P8CX_Vertical
J15: right hand 2; RJ45_OST_PJ012-8P8CX_Vertical
J16: right hand 3; RJ45_OST_PJ012-8P8CX_Vertical
J17: rst; PinHeader_1x02_P2.54mm_Vertical
J18: left hand 3; RJ45_OST_PJ012-8P8CX_Vertical
J19: left leg 0; RJ45_OST_PJ012-8P8CX_Vertical
J20: left leg 1; RJ45_OST_PJ012-8P8CX_Vertical
J21: right lef 0; RJ45_OST_PJ012-8P8CX_Vertical
J22: right leg 1; RJ45_OST_PJ012-8P8CX_Vertical
J23: torso 0; RJ45_OST_PJ012-8P8CX_Vertical
J24: torso 1; RJ45_OST_PJ012-8P8CX_Vertical
J25: torso 2; RJ45_OST_PJ012-8P8CX_Vertical
J26: torso 3; RJ45_OST_PJ012-8P8CX_Vertical
L1: 4.7uH; L_1008_2520Metric
R83, R84, R85: 2k; C_0603_1608Metric
R86, R96, R97: 10k; C_0603_1608Metric
R87, R93: 10k; R_0603_1608Metric
R89, R90, R92: 1k; R_0603_1608Metric
R91: 100; R_0603_1608Metric
R94, R95: 100k; R_0603_1608Metric
R98: 1k; C_0603_1608Metric
TP1: +; TestPoint_Pad_D4.0mm
TP2: -; TestPoint_Pad_D4.0mm
TP4: Vdd; TestPoint_Pad_D2.0mm
TP7: gnd; TestPoint_Pad_D2.0mm
U8: MCP73812; SOT-23-5
U9: MCP1603; SOT-23-5_HandSoldering
U10: LQFP-64_10x10mm_P0.5mm
U11: MCP111; TSOT-23_HandSoldering
U12: BM71BLES1FC2-0B02AA; BM71BLES1FC2_MCH
Y1: Crystal; Crystal_HC52-8mm_Vertical

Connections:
/Vbatt: C8.1, D1.2 (A), R94.1, TP1.1, U8.3 (V_{BAT})
/Vbus: C7.1, D2.2 (A), J6.1 (VBUS), U8.1 (CE), U8.4 (V_{DD})
/Vin: C3.1, D1.1 (K), D2.1 (K), U9.1 (Vin), U9.3 (~SHDN~)
/batt_sense: C21.1, R94.2, R95.1, U10.14 (PA0-WKUP)
/bm_cfg: C22.1, J3.1, R86.2, U12.16 (P2_0)
/bm_led: D5.1 (K), U12.12 (P0_2)
/bm_rx: J8.1, R96.2, U12.7 (HCI_RXD)
/bm_tx: J5.1, U12.8 (HCI_TXD)
/boot0: J11.2, R87.2, U10.60 (BOOT0)
/clk-in: C4.2, U10.5 (PD0_OSC_IN), Y1.1
/clk-out: R91.1, U10.6 (PD1_OSC_OUT)
/data_serial: U10.51 (PC10___USART4_TX); also elsewhere on the board
/led-0: R89.1, U10.21 (PA5)
/led-1: R90.1, U10.22 (PA6)
/led-2: R92.1, U10.23 (PA7)
/lh_int_0_0: J1.4; also elsewhere on the board
/lh_int_0_1: J1.7; also elsewhere on the board
/lh_int_1_0: J2.4; also elsewhere on the board
/lh_int_1_1: J2.7; also elsewhere on the board
/lh_int_2_0: J4.4; also elsewhere on the board
/lh_int_2_1: J4.7; also elsewhere on the board
/lh_int_3_0: J18.4; also elsewhere on the board
/lh_int_3_1: J18.7; also elsewhere on the board
/lh_scl_0: J1.3; also elsewhere on the board
/lh_scl_1: J2.3; also elsewhere on the board
/lh_scl_2: J4.3; also elsewhere on the board
/lh_scl_3: J18.3; also elsewhere on the board
/lh_sda_0: J1.1; also elsewhere on the board
/lh_sda_1: J2.1; also elsewhere on the board
/lh_sda_2: J4.1; also elsewhere on the board
/lh_sda_3: J18.1; also elsewhere on the board
/ll_int_0_0: J19.4; also elsewhere on the board
/ll_int_0_1: J19.7; also elsewhere on the board
/ll_int_1_0: J20.4; also elsewhere on the board
/ll_int_1_1: J20.7; also elsewhere on the board
/ll_scl_0: J19.3; also elsewhere on the board
/ll_scl_1: J20.3; also elsewhere on the board
/ll_sda_0: J19.1; also elsewhere on the board
/ll_sda_1: J20.1; also elsewhere on the board
/parallel_load: U10.50 (PA15___JTDI); also elsewhere on the board
/rh_int_0_0: J13.4; also elsewhere on the board
/rh_int_0_1: J13.7; also elsewhere on the board
/rh_int_1_0: J14.4; also elsewhere on the board
/rh_int_1_1: J14.7; also elsewhere on the board
/rh_int_2_0: J15.4; also elsewhere on the board
/rh_int_2_1: J15.7; also elsewhere on the board
/rh_int_3_0: J16.4; also elsewhere on the board
/rh_int_3_1: J16.7; also elsewhere on the board
/rh_scl_0: J13.3; also elsewhere on the board
/rh_scl_1: J14.3; also elsewhere on the board
/rh_scl_2: J15.3; also elsewhere on the board
/rh_scl_3: J16.3; also elsewhere on the board
/rh_sda_0: J13.1; also elsewhere on the board
/rh_sda_1: J14.1; also elsewhere on the board
/rh_sda_2: J15.1; also elsewhere on the board
/rh_sda_3: J16.1; also elsewhere on the board
/rl_int_0_0: J21.4; also elsewhere on the board
/rl_int_0_1: J21.7; also elsewhere on the board
/rl_int_1_0: J22.4; also elsewhere on the board
/rl_int_1_1: J22.7; also elsewhere on the board
/rl_scl_0: J21.3; also elsewhere on the board
/rl_scl_1: J22.3; also elsewhere on the board
/rl_sda_0: J21.1; also elsewhere on the board
/rl_sda_1: J22.1; also elsewhere on the board
/rst: C32.1, J17.1, R97.2, U10.7 (NRST), U11.1 (Vout), U12.10 (RST_N); also elsewhere on the board
/scl_host_a: U10.58 (PB6__USART1_TX); also elsewhere on the board
/scl_host_b: U10.29 (PB10___USART3_TX); also elsewhere on the board
/sda_host_a: U10.59 (PB7__USART1_RX); also elsewhere on the board
/sda_host_b: U10.30 (PB11___USART3_RX); also elsewhere on the board
/shifter_clock: U10.52 (PC11__USART4_RX); also elsewhere on the board
/stm_rx: J5.2, U10.17 (PA3)
/stm_tx: J8.2, U10.16 (PA2)
/swd_clk: J10.1, U10.49 (PA14___JTCK-SWCLK)
/swd_io: J10.3, U10.46 (PA13___JTMS-SWDIO)
/t_int_0_0: J23.4; also elsewhere on the board
/t_int_0_1: J23.7; also elsewhere on the board
/t_int_1_0: J24.4; also elsewhere on the board
/t_int_1_1: J24.7; also elsewhere on the board
/t_int_2_0: J25.4; also elsewhere on the board
/t_int_2_1: J25.7; also elsewhere on the board
/t_int_3_0: J26.4; also elsewhere on the board
/t_int_3_1: J26.7; also elsewhere on the board
/t_scl_0: J23.3; also elsewhere on the board
/t_scl_1: J24.3; also elsewhere on the board
/t_scl_2: J25.3; also elsewhere on the board
/t_scl_3: J26.3; also elsewhere on the board
/t_sda_0: J23.1; also elsewhere on the board
/t_sda_1: J24.1; also elsewhere on the board
/t_sda_2: J25.1; also elsewhere on the board
/t_sda_3: J26.1; also elsewhere on the board
/uart1-rx: J9.1, R93.2, U10.43 (PA10___OTG_FS_ID/USART1_RX)
/uart1-tx: J9.2, U10.42 (PA9_USART1_TX)
/usb_d+: J6.3 (D+), U10.36 (PB15___OTG_HS_DP)
/usb_d-: J6.2 (D-), U10.35 (PB14___OTG_HS_DM)
GND: C3.2, C4.1, C6.2, C7.2, C8.2, C9.2, C21.2, C22.2, C23.2, C24.2, C27.2, C28.1, C29.1, C30.2, C31.2, C32.2, C33.2, C34.2, C35.2, D3.2 (A), D4.2 (A), D6.2 (A), J1.2, J1.6, J2.2, J2.6, J3.2, J4.2, J4.6, J6.4 (GND), J6.5 (Shield), J9.4, J10.2, J13.2, J13.6, J14.2, J14.6, J15.2, J15.6, J16.2, J16.6, J17.2, J18.2, J18.6, J19.2, J19.6, J20.2, J20.6, J21.2, J21.6, J22.2, J22.6, J23.2, J23.6, J24.2, J24.6, J25.2, J25.6, J26.2, J26.6, R85.1, R87.1, R95.2, TP2.1, TP7.1, U8.2 (V_{SS}), U9.2 (Gnd), U10.12 (VssA), U10.18 (Vss_1), U10.63 (Vss_2), U11.2 (Gnd), U12.2 (GND), U12.13 (GND); also elsewhere on the board
unnamed: C9.1, R91.2, Y1.2
unnamed: D3.1 (K), R90.2
unnamed: D4.1 (K), R92.2
unnamed: D5.2 (A), R98.2
unnamed: D6.1 (K), R89.2
unnamed: R83.1, R84.2
unnamed: R84.1, R85.2
unnamed: R83.2, U8.5 (PROG)
unnamed: L1.1, U9.5 (Lx)
unnamed: C28.2, U10.31 (Vcap_1)
unnamed: C29.2, U10.47 (Vcap_2)
VDD: C6.1, C23.1, C24.1, C27.1, C30.1, C31.1, C33.1, C34.1, C35.1, J1.5, J1.8, J2.5, J2.8, J4.5, J4.8, J9.3, J11.1, J13.5, J13.8, J14.5, J14.8, J15.5, J15.8, J16.5, J16.8, J18.5, J18.8, J19.5, J19.8, J20.5, J20.8, J21.5, J21.8, J22.5, J22.8, J23.5, J23.8, J24.5, J24.8, J25.5, J25.8, J26.5, J26.8, L1.2, R86.1, R93.1, R96.1, R97.1, R98.1, TP4.1, U9.4 (Vfb/Vout), U10.1 (VBAT), U10.13 (VDDA), U10.19 (VDD_4), U10.32 (VDD_1), U10.48 (VDD_2), U10.64 (VDD_3), U11.3 (Vdd), U12.14 (VBAT); also elsewhere on the board

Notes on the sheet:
ESP-12S doesn't have pullup inside the module.
Ethernet pairs are 1, 2 - orange 3, 6 - green 4, 5 - blue 7, 8 - brown
I probably need 3.08V version of this monitor. It is because for LiIon battery 3V is full discharge. And it is not good for it.
Right leg
Torso, neck, head.
Left arm
To battery
Right arm
Low speed: 1.5 Mb/s Full speed: 12 Mb/s High speed: 480 Mb/s
Left leg

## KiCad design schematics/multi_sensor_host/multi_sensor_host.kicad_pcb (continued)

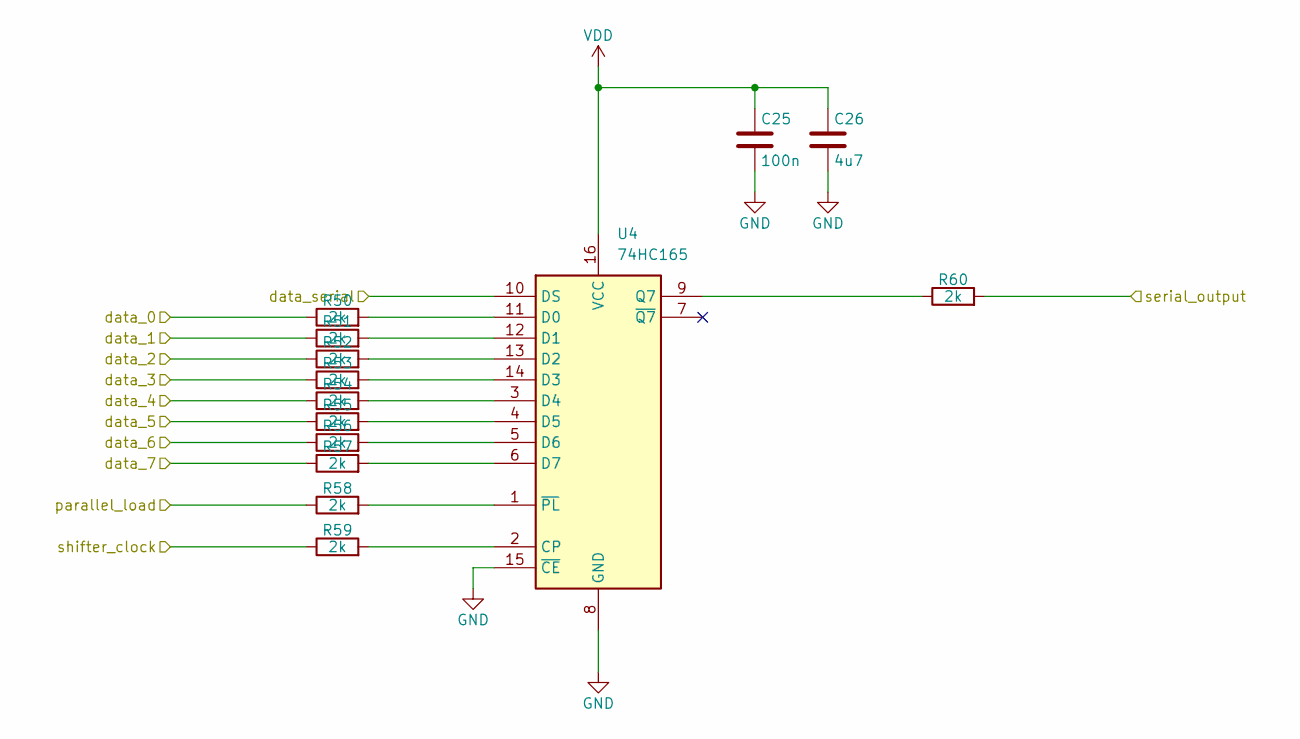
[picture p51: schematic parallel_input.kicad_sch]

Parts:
C25: 100n; C_0603_1608Metric
C26: 4u7; C_0603_1608Metric
R50, R51, R52, R53, R54, R55, R56, R57, R58, R59, R60: 2k; R_0603_1608Metric
U4: 74HC165; SO-16_3.9x9.9mm_P1.27mm

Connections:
/lh_int_0_0: R54.1; also elsewhere on the board
/lh_int_0_1: R55.1; also elsewhere on the board
/lh_int_1_0: R56.1; also elsewhere on the board
/lh_int_1_1: R57.1; also elsewhere on the board
/ll_int_0_0: R52.1; also elsewhere on the board
/ll_int_0_1: R53.1; also elsewhere on the board
/ll_int_1_0: R50.1; also elsewhere on the board
/ll_int_1_1: R51.1; also elsewhere on the board
/parallel_input_sheet/serial_output: R60.2; also elsewhere on the board
/parallel_load: R58.1; also elsewhere on the board
/shifter_clock: R59.1; also elsewhere on the board
GND: C25.2, C26.2, U4.8 (GND), U4.15 (~CE); also elsewhere on the board
unnamed: R59.2, U4.2 (CP)
unnamed: R50.2, U4.11 (D0)
unnamed: R51.2, U4.12 (D1)
unnamed: R52.2, U4.13 (D2)
unnamed: R53.2, U4.14 (D3)
unnamed: R54.2, U4.3 (D4)
unnamed: R55.2, U4.4 (D5)
unnamed: R56.2, U4.5 (D6)
unnamed: R57.2, U4.6 (D7)
unnamed: R60.1, U4.9 (Q7)
unnamed: R58.2, U4.1 (~PL)
VDD: C25.1, C26.1, U4.10 (DS), U4.16 (VCC); also elsewhere on the board

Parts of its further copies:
C15, C17, C19: 100n; C_0603_1608Metric
C16, C18, C20: 4u7; C_0603_1608Metric
R39, R40, R41, R42, R43, R44, R45, R46, R47, R48, R49, R61, R62, R63, R64, R65, R66, R67, R68, R69, R70, R71, R72, R73, R74, R75, R76, R77, R78, R79, R80, R81, R82: 2k; R_0603_1608Metric
U3, U5, U6: 74HC165; SO-16_3.9x9.9mm_P1.27mm

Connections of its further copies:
/data_serial: R82.2; also elsewhere on the board
/lh_int_2_0: R39.1; also elsewhere on the board
/lh_int_2_1: R40.1; also elsewhere on the board
/lh_int_3_0: R41.1; also elsewhere on the board
/lh_int_3_1: R42.1; also elsewhere on the board
/parallel_input_sheet1/serial_output: R49.2, U5.10 (DS)
/parallel_input_sheet2/serial_output: R71.2, U6.10 (DS)
/parallel_input_sheet/serial_output: U3.10 (DS); also elsewhere on the board
/parallel_load: R47.1, R69.1, R80.1; also elsewhere on the board
/rh_int_0_0: R65.1; also elsewhere on the board
/rh_int_0_1: R66.1; also elsewhere on the board
/rh_int_1_0: R67.1; also elsewhere on the board
/rh_int_1_1: R68.1; also elsewhere on the board
/rh_int_2_0: R72.1; also elsewhere on the board
/rh_int_2_1: R73.1; also elsewhere on the board
/rh_int_3_0: R74.1; also elsewhere on the board
/rh_int_3_1: R75.1; also elsewhere on the board
/rl_int_0_0: R76.1; also elsewhere on the board
/rl_int_0_1: R77.1; also elsewhere on the board
/rl_int_1_0: R78.1; also elsewhere on the board
/rl_int_1_1: R79.1; also elsewhere on the board
/shifter_clock: R48.1, R70.1, R81.1; also elsewhere on the board
/t_int_0_0: R63.1; also elsewhere on the board
/t_int_0_1: R64.1; also elsewhere on the board
/t_int_1_0: R61.1; also elsewhere on the board
/t_int_1_1: R62.1; also elsewhere on the board
/t_int_2_0: R45.1; also elsewhere on the board
/t_int_2_1: R46.1; also elsewhere on the board
/t_int_3_0: R43.1; also elsewhere on the board
/t_int_3_1: R44.1; also elsewhere on the board
GND: C15.2, C16.2, C17.2, C18.2, C19.2, C20.2, U3.8 (GND), U3.15 (~CE), U5.8 (GND), U5.15 (~CE), U6.8 (GND), U6.15 (~CE); also elsewhere on the board
unnamed: R48.2, U3.2 (CP)
unnamed: R39.2, U3.11 (D0)
unnamed: R40.2, U3.12 (D1)
unnamed: R41.2, U3.13 (D2)
unnamed: R42.2, U3.14 (D3)
unnamed: R43.2, U3.3 (D4)
unnamed: R44.2, U3.4 (D5)
unnamed: R45.2, U3.5 (D6)
unnamed: R46.2, U3.6 (D7)
unnamed: R49.1, U3.9 (Q7)
unnamed: R47.2, U3.1 (~PL)
unnamed: R70.2, U5.2 (CP)
unnamed: R61.2, U5.11 (D0)
unnamed: R62.2, U5.12 (D1)
unnamed: R63.2, U5.13 (D2)
unnamed: R64.2, U5.14 (D3)
unnamed: R65.2, U5.3 (D4)
unnamed: R66.2, U5.4 (D5)
unnamed: R67.2, U5.5 (D6)
unnamed: R68.2, U5.6 (D7)
unnamed: R71.1, U5.9 (Q7)
unnamed: R69.2, U5.1 (~PL)
unnamed: R81.2, U6.2 (CP)
unnamed: R72.2, U6.11 (D0)
unnamed: R73.2, U6.12 (D1)
unnamed: R74.2, U6.13 (D2)
unnamed: R75.2, U6.14 (D3)
unnamed: R76.2, U6.3 (D4)
unnamed: R77.2, U6.4 (D5)
unnamed: R78.2, U6.5 (D6)
unnamed: R79.2, U6.6 (D7)
unnamed: R82.1, U6.9 (Q7)
unnamed: R80.2, U6.1 (~PL)
VDD: C15.1, C16.1, C17.1, C18.1, C19.1, C20.1, U3.16 (VCC), U5.16 (VCC), U6.16 (VCC); also elsewhere on the board

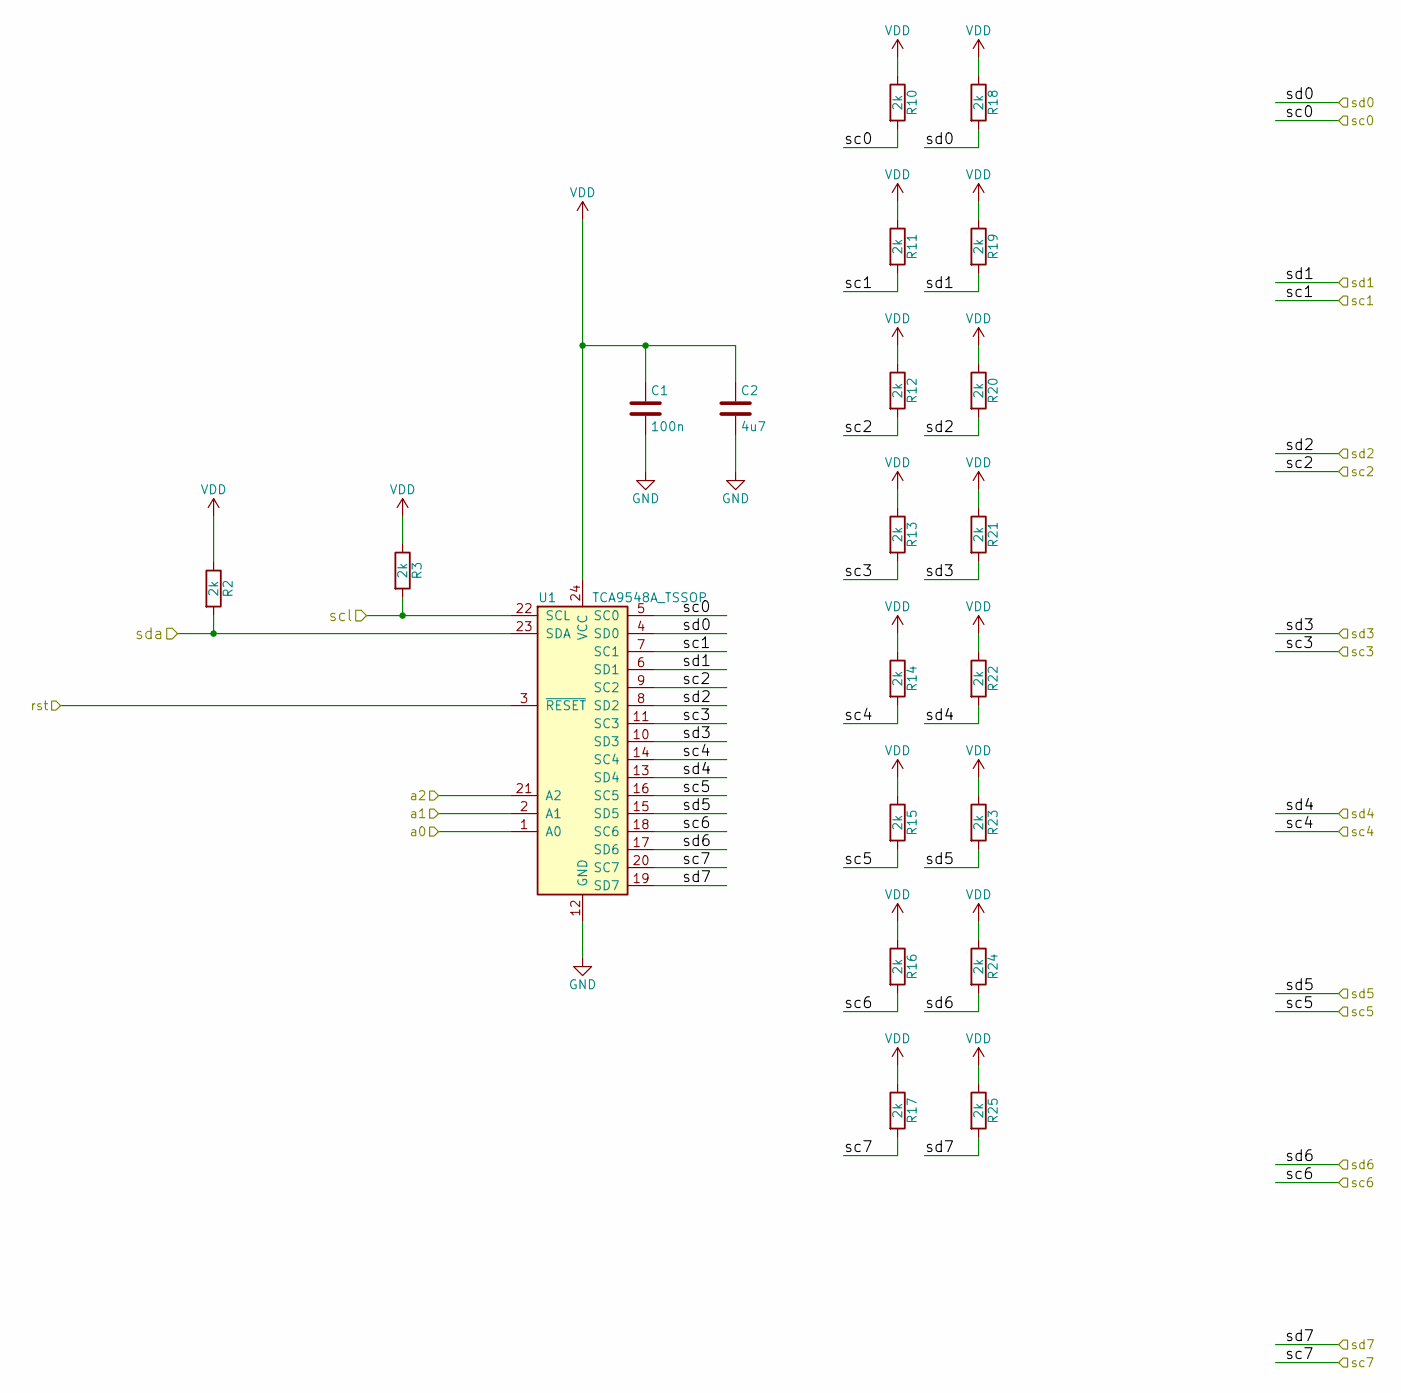
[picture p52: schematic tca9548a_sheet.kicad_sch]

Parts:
C1: 100n; C_0603_1608Metric
C2: 4u7; C_0603_1608Metric
R2, R3, R10, R11, R12, R13, R14, R15, R16, R17, R18, R19, R20, R21, R22, R23, R24, R25: 2k; C_0603_1608Metric
U1: TCA9548A_TSSOP; TSSOP-24_4.4x7.8mm_P0.65mm

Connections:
/lh_scl_0: R12.2, U1.9 (SC2); also elsewhere on the board
/lh_scl_1: R13.2, U1.11 (SC3); also elsewhere on the board
/lh_scl_2: R14.2, U1.14 (SC4); also elsewhere on the board
/lh_scl_3: R15.2, U1.16 (SC5); also elsewhere on the board
/lh_sda_0: R20.2, U1.8 (SD2); also elsewhere on the board
/lh_sda_1: R21.2, U1.10 (SD3); also elsewhere on the board
/lh_sda_2: R22.2, U1.13 (SD4); also elsewhere on the board
/lh_sda_3: R23.2, U1.15 (SD5); also elsewhere on the board
/ll_scl_0: R11.2, U1.7 (SC1); also elsewhere on the board
/ll_scl_1: R10.2, U1.5 (SC0); also elsewhere on the board
/ll_sda_0: R19.2, U1.6 (SD1); also elsewhere on the board
/ll_sda_1: R18.2, U1.4 (SD0); also elsewhere on the board
/rst: U1.3 (~RESET); also elsewhere on the board
/scl_host_a: R3.2, U1.22 (SCL); also elsewhere on the board
/sda_host_a: R2.2, U1.23 (SDA); also elsewhere on the board
/t_scl_2: R17.2, U1.20 (SC7); also elsewhere on the board
/t_scl_3: R16.2, U1.18 (SC6); also elsewhere on the board
/t_sda_2: R25.2, U1.19 (SD7); also elsewhere on the board
/t_sda_3: R24.2, U1.17 (SD6); also elsewhere on the board
GND: C1.2, C2.2, U1.1 (A0), U1.2 (A1), U1.12 (GND), U1.21 (A2); also elsewhere on the board
VDD: C1.1, C2.1, R2.1, R3.1, R10.1, R11.1, R12.1, R13.1, R14.1, R15.1, R16.1, R17.1, R18.1, R19.1, R20.1, R21.1, R22.1, R23.1, R24.1, R25.1, U1.24 (VCC); also elsewhere on the board

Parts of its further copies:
C13: 100n; C_0603_1608Metric
C14: 4u7; C_0603_1608Metric
R5, R6, R7, R8, R9, R26, R27, R28, R29, R30, R31, R32, R33, R34, R35, R36, R37, R38: 2k; C_0603_1608Metric
U2: TCA9548A_TSSOP; TSSOP-24_4.4x7.8mm_P0.65mm

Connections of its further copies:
/rh_scl_0: R9.2, U2.9 (SC2); also elsewhere on the board
/rh_scl_1: R26.2, U2.11 (SC3); also elsewhere on the board
/rh_scl_2: R27.2, U2.14 (SC4); also elsewhere on the board
/rh_scl_3: R28.2, U2.16 (SC5); also elsewhere on the board
/rh_sda_0: R33.2, U2.8 (SD2); also elsewhere on the board
/rh_sda_1: R34.2, U2.10 (SD3); also elsewhere on the board
/rh_sda_2: R35.2, U2.13 (SD4); also elsewhere on the board
/rh_sda_3: R36.2, U2.15 (SD5); also elsewhere on the board
/rl_scl_0: R29.2, U2.18 (SC6); also elsewhere on the board
/rl_scl_1: R30.2, U2.20 (SC7); also elsewhere on the board
/rl_sda_0: R37.2, U2.17 (SD6); also elsewhere on the board
/rl_sda_1: R38.2, U2.19 (SD7); also elsewhere on the board
/rst: U2.3 (~RESET); also elsewhere on the board
/scl_host_b: R6.2, U2.22 (SCL); also elsewhere on the board
/sda_host_b: R5.2, U2.23 (SDA); also elsewhere on the board
/t_scl_0: R8.2, U2.7 (SC1); also elsewhere on the board
/t_scl_1: R7.2, U2.5 (SC0); also elsewhere on the board
/t_sda_0: R32.2, U2.6 (SD1); also elsewhere on the board
/t_sda_1: R31.2, U2.4 (SD0); also elsewhere on the board
GND: C13.2, C14.2, U2.2 (A1), U2.12 (GND), U2.21 (A2); also elsewhere on the board
VDD: C13.1, C14.1, R5.1, R6.1, R7.1, R8.1, R9.1, R26.1, R27.1, R28.1, R29.1, R30.1, R31.1, R32.1, R33.1, R34.1, R35.1, R36.1, R37.1, R38.1, U2.1 (A0), U2.24 (VCC); also elsewhere on the board

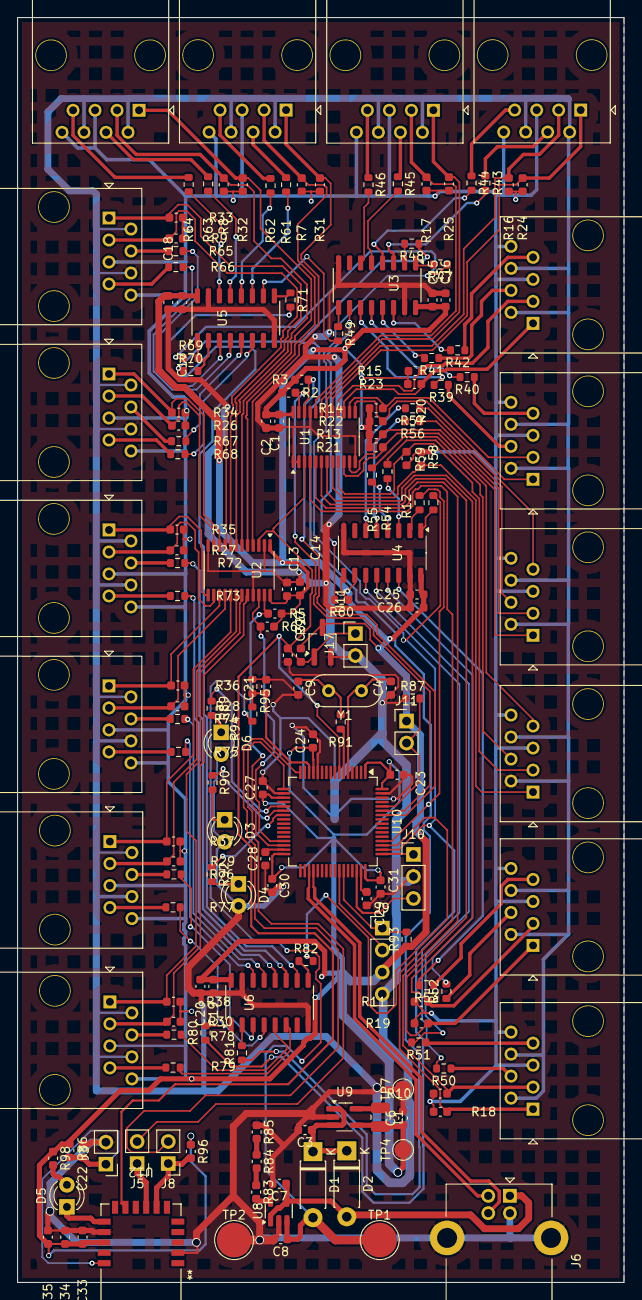
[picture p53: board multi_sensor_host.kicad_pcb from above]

Board: 2 copper layers, 70.0 x 146.0 mm, 173 parts (0 on the bottom side), 154 nets.

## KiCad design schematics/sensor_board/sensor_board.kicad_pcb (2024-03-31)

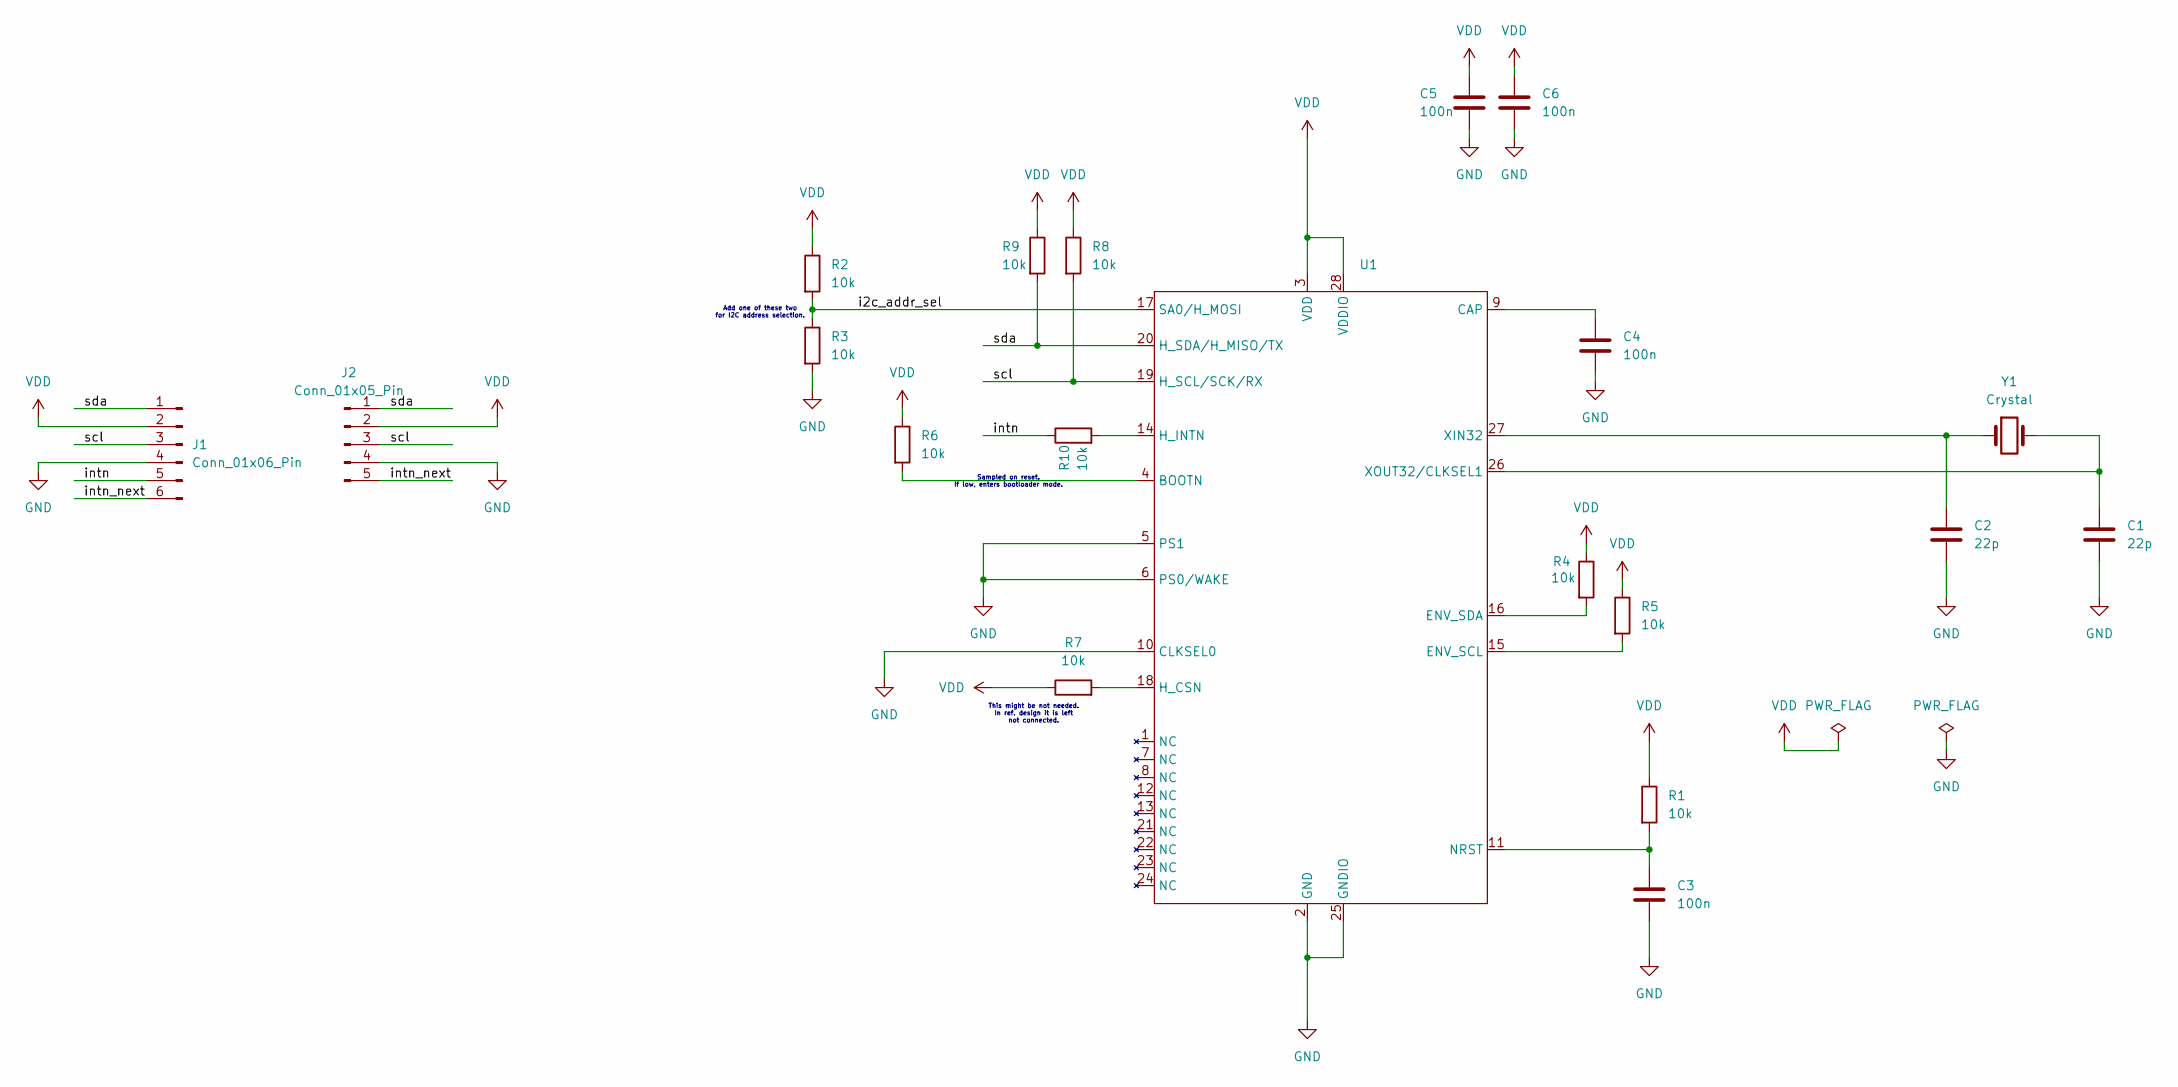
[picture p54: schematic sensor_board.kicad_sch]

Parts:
C1, C2: 22p; C_0603_1608Metric_Pad1.08x0.95mm_HandSolder
C3, C4, C5, C6: 100n; C_0603_1608Metric_Pad1.08x0.95mm_HandSolder
J1: Conn_01x06_Pin; PinHeader_1x06_P1.27mm_Vertical
J2: Conn_01x05_Pin; PinHeader_1x05_P1.27mm_Vertical
R1, R2, R3, R4, R5, R6, R7, R8, R9, R10: 10k; R_0603_1608Metric_Pad0.98x0.95mm_HandSolder
U1: LGA-28_5.2x3.8mm_P0.5mm
Y1: Crystal; Crystal_HC52-8mm_Vertical

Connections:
/i2c_addr_sel: R2.2, R3.1, U1.17 (SA0/H_MOSI)
/intn: J1.5, R10.1
/intn_next: J1.6, J2.5
/scl: J1.3, J2.3, R8.2, U1.19 (H_SCL/SCK/RX)
/sda: J1.1, J2.1, R9.2, U1.20 (H_SDA/H_MISO/TX)
GND: C1.2, C2.2, C3.2, C4.2, C5.2, C6.2, J1.4, J2.4, R3.2, U1.2 (GND), U1.5 (PS1), U1.6 (PS0/WAKE), U1.10 (CLKSEL0), U1.25 (GNDIO)
unnamed: R6.2, U1.4 (BOOTN)
unnamed: C4.1, U1.9 (CAP)
unnamed: R5.2, U1.15 (ENV_SCL)
unnamed: R4.2, U1.16 (ENV_SDA)
unnamed: R7.2, U1.18 (H_CSN)
unnamed: R10.2, U1.14 (H_INTN)
unnamed: C3.1, R1.2, U1.11 (NRST)
unnamed: C2.1, U1.27 (XIN32), Y1.1
unnamed: C1.1, U1.26 (XOUT32/CLKSEL1), Y1.2
VDD: C5.1, C6.1, J1.2, J2.2, R1.1, R2.1, R4.1, R5.1, R6.1, R7.1, R8.1, R9.1, U1.3 (VDD), U1.28 (VDDIO)

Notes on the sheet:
Sampled on reset. If low, enters bootloader mode.
Add one of these two for I2C address selection.
This might be not needed. In ref. design it is left not connected.



Board: 2 copper layers, 17.5 x 21.0 mm, 20 parts (6 on the bottom side), 16 nets.

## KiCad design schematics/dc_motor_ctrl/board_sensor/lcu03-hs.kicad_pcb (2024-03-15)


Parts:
C1: 100n; C_0603
P2: Side conns; Pin_Header_Angled_1x03
R1: 10k; R_0603
U1: a110x; SOT-23-wide

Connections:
/out: P2.3, R1.2, U1.2 (Vout)
GND: C1.2, P2.2, U1.3 (Gnd)
VCC: C1.1, P2.1, R1.1, U1.1 (Vcc)


Board: 2 copper layers, 7.0 x 8.2 mm, 4 parts (0 on the bottom side), 3 nets.

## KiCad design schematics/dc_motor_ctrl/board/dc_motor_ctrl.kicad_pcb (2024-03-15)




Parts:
C1, C5: 18p; C_0603_HandSoldering
C2, C3, C6, C8, C9, C10, C11, C13, C14, C15, C17, C18: 100n; C_0603_HandSoldering
C4, C7, C12, C19, C20: 4u7; C_0603_HandSoldering
C16: CP; CP_Radial_D10.0mm_P5.00mm
D1, D2, D5: LED; LED_D5.0mm
D3, D4: PMEG3030EP,115; SOD128
J1: power; Pin_Header_Straight_1x02_Pitch2.54mm
J2: CONN_02X02; Pin_Header_Straight_2x02_Pitch2.54mm
J3: CONN_02X04; Pin_Header_Straight_2x04_Pitch2.54mm
J4: hall_sen; Pin_Header_Straight_1x03_Pitch1.27mm
J5: motor; Pin_Header_Straight_1x02_Pitch2.54mm
P1: USB_B
P2: ~rst~; Pin_Header_Straight_1x01_Pitch1.27mm
P3: mode; Pin_Header_Straight_1x02_Pitch1.27mm
P4: swd; Pin_Header_Straight_1x03_Pitch1.27mm
R1, R2, R7: 1k 5%; R_0603_HandSoldering
R3, R5, R6, R8, R9, R10, R11, R12, R13, R15, R16, R17: 10k 5%; R_0603_HandSoldering
R4: 100 5%; R_0603_HandSoldering
R14: 0R5 5%; R_0603_HandSoldering
U1: crystal-4pin; CRYSTAL-SMD-5x3
U2: FT232RL; SSOP-28_5.3x10.2mm_Pitch0.65mm
U3: my-NCP1117ST50T3G; SOT-223
U4: SI8431; SOIC-16W_7.5x10.3mm_Pitch1.27mm
U5: drv8801; my_TSSOP-16-1EP_4.4x5mm_Pitch0.65mm
U6: NCP1117ST50T3G; SOT-223
stm1: STM32F103CBT6; LQFP48

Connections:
+5V: C20.1, J4.2, U6.2 (VO), U6.4 (VO)
/3v3: C2.1, C3.1, R7.1, U2.4 (VCCIO), U2.17 (3V3OUT), U4.1 (Vdd1), U4.7 (En1)
/12v: C14.1, C15.1, C16.1, D3.2 (A), J1.1, U5.9 (vbb)
/Vbus: C18.1, J2.1, P1.1 (VBUS), U2.20 (VCC)
/boot0: P3.2, R3.1, stm1.44 (BOOT0)
/boot1: R5.1, stm1.20 (PB2/BOOT1)
/clk-in: C1.2, U1.3 (xtal2), stm1.5 (PD0/OSC_IN)
/clk-out: R4.1, stm1.6 (PD1/OSC_OUT)
/d+: P1.3 (D+), U2.15 (USBD+)
/d-: P1.2 (D-), U2.16 (USBD-)
/ft_rts: U2.3 (RTS/D2), U4.4 (A2)
/ft_rx: U2.5 (RXD/D1), U4.5 (A3)
/ft_tx: U2.1 (TXD/D0), U4.3 (A1)
/hall_sen: J4.1, R16.1
/hall_sen_mcu: R16.2, R17.1, stm1.28 (PB15/SPI2_MOSI)
/led-0: R1.1, stm1.3 (PC14/OSC32_IN)
/led-1: R2.1, stm1.2 (PC13/TAMPER-RTC)
/motor+: J5.1, U5.7 (out+)
/motor-: J5.2, U5.10 (out-)
/phase: U5.3 (phase), stm1.46 (PB9/TIM4_CH4^I2C1_SDA)
/pwm: U5.6 (enable), stm1.18 (PB0/ADC_IN8/TIM3_CH3)
/scl_1: J3.7, R8.2, stm1.42 (PB6/I2C1_SCL/TIM4_CH1^USART1_TX)
/scl_2: J3.8, R10.2, stm1.21 (PB10/I2C2_SCL/USART3_TX^TIM2_CH3)
/sda_1: J3.5, R9.2, stm1.43 (PB7/I2C1_SDA/TIM4_CH3^USART1_RX)
/sda_2: J3.6, R11.2, stm1.22 (PB11/I2C2_SDA/USART3_RX^TIM2_CH4)
/st_cts: U4.13 (B2), stm1.32 (PA11/USART1_CTS/USBDM)
/st_rx: U4.14 (B1), stm1.31 (PA10/USART1_RX)
/st_tx: U4.12 (B3), stm1.30 (PA9/USART1_TX)
/swd-clk: P4.3, stm1.37 (JTCK/SWCLK^PA14)
/swd-io: P4.1, stm1.34 (JTMS/SWDIO^PA13)
/vcp: C14.2, U5.14 (vcp)
/~fault~: R15.2, U5.1 (~fault~), stm1.4 (PC15/OSC32_OUT)
/~mcu-rst~: C6.1, P2.1, R6.2, stm1.7 (NRST)
/~sleep~: U5.5 (~sleep~), stm1.45 (PB8/TIM4_CH3^I2C1_SCL)
GND: C1.1, C4.2, C5.2, C6.2, C7.2, C8.2, C9.2, C10.2, C11.2, C12.2, C15.2, C16.2, C17.2, C19.2, C20.2, D1.2 (A), D2.2 (A), J1.2, J2.4, J3.3, J3.4, J4.3, P4.2, R3.2, R5.2, R14.2, R17.2, U1.2, U1.4, U3.1 (GND), U4.9 (Gnd2), U4.15 (Gnd2), U5.4 (gnd), U5.13 (gnd), U5.17 (thermal_pad), U6.1 (GND), stm1.8 (Vssa), stm1.23 (Vss_1), stm1.35 (Vss_2), stm1.47 (Vss_3)
GNDA: C2.2, C3.2, C18.2, D5.2 (A), J2.3, P1.4 (GND), P1.5 (Shield), U2.7 (GND), U2.18 (GND), U2.21 (GND), U2.25 (AGND), U2.26 (TEST), U4.2 (Gnd1), U4.8 (Gnd1)
unnamed: C5.1, R4.2, U1.1 (xtal)
unnamed: C13.1, U5.12 (cp2)
unnamed: C13.2, U5.11 (cp1)
unnamed: C4.1, C19.1, D3.1 (K), D4.1 (K), U3.3 (VI), U6.3 (VI)
unnamed: D1.1 (K), R1.2
unnamed: D2.1 (K), R2.2
unnamed: D4.2 (A), J2.2
unnamed: D5.1 (K), R7.2
unnamed: R12.1, U5.2 (mode_1)
unnamed: R13.1, U5.16 (mode_2)
unnamed: R14.1, U5.8 (sense)
VDD: C7.1, C8.1, C9.1, C10.1, C11.1, C12.1, C17.1, J3.1, J3.2, P3.1, R6.1, R8.1, R9.1, R10.1, R11.1, R12.2, R13.2, R15.1, U3.2 (VO), U3.4 (VO), U4.10 (En2), U4.16 (Vdd2), stm1.1 (Vbat), stm1.9 (Vdda), stm1.24 (Vdd_1), stm1.36 (Vdd_2), stm1.48 (Vdd_3)

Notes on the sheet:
This means slow decay using upper bridge part.
Though MCU is 5V tolerant but still it is better to have protection.


Board: 2 copper layers, 64.5 x 39.1 mm, 58 parts (1 on the bottom side), 48 nets.

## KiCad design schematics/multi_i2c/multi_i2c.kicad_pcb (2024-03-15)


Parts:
C1, C2, C6, C7: 100n; C_0603
C3, C4, C5, C8: 4u7; C_0603
P1: USB_B
R1, R2: 10k; R_0603
R3, R4, R5, R6: 0; R_0603
U1: CP2102
U2: CY8CKIT-059; cy8ckit-059
U3: NCP1117DT33G_MountingTab; SOT-223

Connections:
/Vbus: C5.1, C6.1, P1.1 (VBUS), U1.8 (Vbus), U3.3 (VI)
/cts: U1.23 (CTS), U2.20 (2.6)
/d+: P1.3 (D+), U1.4 (D+)
/d-: P1.2 (D-), U1.5 (D-)
/rts: U1.24 (RTS), U2.19 (2.7)
/rx: R2.2, U1.25 (RXD), U2.18 (12.7/tx)
/scl-a: R3.2, U2.11 (12.0/scl); also elsewhere on the board
/scl-b: R3.1, R5.1; also elsewhere on the board
/sda-a: R4.2, U2.12 (12.1/sda); also elsewhere on the board
/sda-b: R4.1, R6.1; also elsewhere on the board
/suspend: U1.12 (SUSPEND), U2.21 (2.5)
/tx: U1.26 (TXD), U2.17 (12.6/rx)
GND: C1.2, C2.2, C3.2, C4.2, C5.2, C6.2, C7.2, C8.2, P1.4 (GND), P1.5 (Shield), U1.0 (Gnd), U1.3 (Gnd), U2.2 (gnd), U2.28 (gnd), U2.52 (gnd), U3.1 (GND); also elsewhere on the board
unnamed: C1.1, R1.2, U1.9 (~RST)
unnamed: C4.1, U1.18 (Vpp/nc)
unnamed: R5.2, U2.13 (12.2)
unnamed: R6.2, U2.14 (12.3)
VDD: C2.1, C3.1, C7.1, C8.1, R1.1, R2.1, U1.6 (Vdd), U1.7 (REGIN), U1.10 (nc), U1.13 (nc), U1.14 (nc), U1.15 (nc), U1.16 (nc), U1.17 (nc), U1.19 (nc), U1.20 (nc), U1.21 (nc), U1.22 (nc), U2.1 (vdd_io), U2.27 (Vdd), U3.2 (VO), U3.4 (VO); also elsewhere on the board

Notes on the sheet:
USB scheme.
Solder either upper two or lower two to make all I2C connected to one and the same bus or to two separate buses.
Just for compatibility with CP2109 and may be not installed for CP2102. 4u7 capacitor.


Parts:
C9: 100n; C_0603
C10, C21, C22, C23, C24, C25, C26, C27, C28: 4u7; C_0603
J2, J3, J4, J5, J6, J7, J8, J9: CONN_01X04; Pin_Header_Straight_1x04_Pitch1.27mm
R7, R8, R9, R16, R17, R18, R19, R20, R21, R22, R23, R24, R25, R26, R27, R28, R29, R30, R31: 2k; R_0603
R10, R11, R12, R13, R14, R15: 0; R_0603
U4: TCA9548A_TSSOP; TSSOP-24_4.4x7.8mm_Pitch0.65mm

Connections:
/i2c_mult_a/a0-a: R14.2, R15.1, U4.1 (A0)
/i2c_mult_a/a1-a: R12.2, R13.1, U4.2 (A1)
/i2c_mult_a/a2-a: R10.2, R11.1, U4.21 (A2)
/i2c_mult_a/sc1-a: J2.4, R17.2, U4.7 (SC1)
/i2c_mult_a/sc2-a: J3.4, R18.2, U4.9 (SC2)
/i2c_mult_a/sc3-a: J4.4, R19.2, U4.11 (SC3)
/i2c_mult_a/sc4-a: J5.4, R20.2, U4.14 (SC4)
/i2c_mult_a/sc5-a: J6.4, R21.2, U4.16 (SC5)
/i2c_mult_a/sc6-a: J7.4, R22.2, U4.18 (SC6)
/i2c_mult_a/sc7-a: J8.4, R23.2, U4.20 (SC7)
/i2c_mult_a/sd1-a: J2.3, R25.2, U4.6 (SD1)
/i2c_mult_a/sd2-a: J3.3, R26.2, U4.8 (SD2)
/i2c_mult_a/sd3-a: J4.3, R27.2, U4.10 (SD3)
/i2c_mult_a/sd4-a: J5.3, R28.2, U4.13 (SD4)
/i2c_mult_a/sd5-a: J6.3, R29.2, U4.15 (SD5)
/i2c_mult_a/sd6-a: J7.3, R30.2, U4.17 (SD6)
/i2c_mult_a/sd7-a: J8.3, R31.2, U4.19 (SD7)
/scl-b: R9.2, U4.22 (SCL); also elsewhere on the board
/sda-b: R8.2, U4.23 (SDA); also elsewhere on the board
GND: C9.2, C10.2, C21.2, C22.2, C23.2, C24.2, C25.2, C26.2, C27.2, C28.2, J2.2, J3.2, J4.2, J5.2, J6.2, J7.2, J8.2, J9.2, R11.2, R13.2, R15.2, U4.12 (GND); also elsewhere on the board
unnamed: R7.2, U4.3 (~RESET)
VDD: C9.1, C10.1, C21.1, C22.1, C23.1, C24.1, C25.1, C26.1, C27.1, C28.1, J2.1, J3.1, J4.1, J5.1, J6.1, J7.1, J8.1, J9.1, R7.1, R8.1, R9.1, R10.1, R12.1, R14.1, R16.1, R17.1, R18.1, R19.1, R20.1, R21.1, R22.1, R23.1, R24.1, R25.1, R26.1, R27.1, R28.1, R29.1, R30.1, R31.1, U4.24 (VCC); also elsewhere on the board

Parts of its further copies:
C11: 100n; C_0603
C12, C13, C14, C15, C16, C17, C18, C19, C20: 4u7; C_0603
J1, J10, J11, J12, J13, J14, J15, J16: CONN_01X04; Pin_Header_Straight_1x04_Pitch1.27mm
R32, R33, R34, R41, R42, R43, R44, R45, R46, R47, R48, R49, R50, R51, R52, R53, R54, R55, R56: 2k; R_0603
R35, R36, R37, R38, R39, R40: 0; R_0603
U5: TCA9548A_TSSOP; TSSOP-24_4.4x7.8mm_Pitch0.65mm

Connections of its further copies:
/i2c_mult_b/a0-a: R39.2, R40.1, U5.1 (A0)
/i2c_mult_b/a1-a: R37.2, R38.1, U5.2 (A1)
/i2c_mult_b/a2-a: R35.2, R36.1, U5.21 (A2)
/i2c_mult_b/sc1-a: J10.4, R42.2, U5.7 (SC1)
/i2c_mult_b/sc2-a: J11.4, R43.2, U5.9 (SC2)
/i2c_mult_b/sc3-a: J12.4, R44.2, U5.11 (SC3)
/i2c_mult_b/sc4-a: J13.4, R45.2, U5.14 (SC4)
/i2c_mult_b/sc5-a: J14.4, R46.2, U5.16 (SC5)
/i2c_mult_b/sc6-a: J15.4, R47.2, U5.18 (SC6)
/i2c_mult_b/sc7-a: J16.4, R48.2, U5.20 (SC7)
/i2c_mult_b/sd1-a: J10.3, R50.2, U5.6 (SD1)
/i2c_mult_b/sd2-a: J11.3, R51.2, U5.8 (SD2)
/i2c_mult_b/sd3-a: J12.3, R52.2, U5.10 (SD3)
/i2c_mult_b/sd4-a: J13.3, R53.2, U5.13 (SD4)
/i2c_mult_b/sd5-a: J14.3, R54.2, U5.15 (SD5)
/i2c_mult_b/sd6-a: J15.3, R55.2, U5.17 (SD6)
/i2c_mult_b/sd7-a: J16.3, R56.2, U5.19 (SD7)
/scl-a: R34.2, U5.22 (SCL); also elsewhere on the board
/sda-a: R33.2, U5.23 (SDA); also elsewhere on the board
GND: C11.2, C12.2, C13.2, C14.2, C15.2, C16.2, C17.2, C18.2, C19.2, C20.2, J1.2, J10.2, J11.2, J12.2, J13.2, J14.2, J15.2, J16.2, R36.2, R38.2, R40.2, U5.12 (GND); also elsewhere on the board
unnamed: R32.2, U5.3 (~RESET)
VDD: C11.1, C12.1, C13.1, C14.1, C15.1, C16.1, C17.1, C18.1, C19.1, C20.1, J1.1, J10.1, J11.1, J12.1, J13.1, J14.1, J15.1, J16.1, R32.1, R33.1, R34.1, R35.1, R37.1, R39.1, R41.1, R42.1, R43.1, R44.1, R45.1, R46.1, R47.1, R48.1, R49.1, R50.1, R51.1, R52.1, R53.1, R54.1, R55.1, R56.1, U5.24 (VCC); also elsewhere on the board

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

Board: 2 copper layers, 96.8 x 26.7 mm, 106 parts (1 on the bottom side), 58 nets.

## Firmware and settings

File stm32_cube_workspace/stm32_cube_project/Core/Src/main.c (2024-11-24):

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
/* Includes ------------------------------------------------------------------*/
#include "main.h"
#include "cmsis_os.h"
#include "usb_device.h"

/* USER CODE BEGIN Includes */
#include "task_led.h"
#include "task_imu.h"
#include "task_uart_output.h"
#include "task_bmi085.h"
/* USER CODE END Includes */

ADC_HandleTypeDef hadc1;

I2C_HandleTypeDef hi2c1;
I2C_HandleTypeDef hi2c2;

UART_HandleTypeDef huart1;
UART_HandleTypeDef huart2;

osThreadId defaultTaskHandle;
void SystemClock_Config(void);
static void MX_GPIO_Init(void);
static void MX_ADC1_Init(void);
static void MX_I2C1_Init(void);
static void MX_I2C2_Init(void);
static void MX_USART2_UART_Init(void);
static void MX_USART1_UART_Init(void);
void StartDefaultTask(void const * argument);

/**
  * @brief  The application entry point.
  * @retval int
  */
int main(void)
{

  /* MCU Configuration--------------------------------------------------------*/

  /* Reset of all peripherals, Initializes the Flash interface and the Systick. */
  HAL_Init();

  /* Configure the system clock */
  SystemClock_Config();

  /* Initialize all configured peripherals */
  MX_GPIO_Init();
  MX_ADC1_Init();
  MX_I2C1_Init();
  MX_I2C2_Init();
  MX_USART2_UART_Init();
  MX_USART1_UART_Init();
  /* USER CODE BEGIN RTOS_MUTEX */
  /* add mutexes, ... */
  /* USER CODE END RTOS_MUTEX */

  /* USER CODE BEGIN RTOS_SEMAPHORES */
  /* add semaphores, ... */
  /* USER CODE END RTOS_SEMAPHORES */

  /* USER CODE BEGIN RTOS_TIMERS */
  /* start timers, add new ones, ... */
  /* USER CODE END RTOS_TIMERS */

  /* USER CODE BEGIN RTOS_QUEUES */
  /* add queues, ... */
  /* USER CODE END RTOS_QUEUES */

  /* Create the thread(s) */
  /* definition and creation of defaultTask */
  //osThreadDef(defaultTask, StartDefaultTask, osPriorityNormal, 0, 128);
  //defaultTaskHandle = osThreadCreate(osThread(defaultTask), NULL);

  /* USER CODE BEGIN RTOS_THREADS */
  /* add threads, ... */
  //task_imu_init();
  task_led_init();
  task_bmi085_init();
  task_uart_output_init();
  /* USER CODE END RTOS_THREADS */

  /* Start scheduler */
  osKernelStart();

  /* We should never get here as control is now taken by the scheduler */

  /* Infinite loop */
  /* USER CODE BEGIN WHILE */
  while (1)
  {
    /* USER CODE END WHILE */

    /* USER CODE BEGIN 3 */
  }
  /* USER CODE END 3 */
}

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
/* USER CODE BEGIN Header_StartDefaultTask */
/**
  * @brief  Function implementing the defaultTask thread.
  * @param  argument: Not used
  * @retval None
  */
/* USER CODE END Header_StartDefaultTask */
void StartDefaultTask(void const * argument)
{
  /* init code for USB_DEVICE */
  MX_USB_DEVICE_Init();
  /* USER CODE BEGIN 5 */
  /* Infinite loop */
  for(;;)
  {
	  HAL_GPIO_TogglePin( LED_0_GPIO_Port, LED_0_Pin );
	  HAL_GPIO_TogglePin( LED_1_GPIO_Port, LED_1_Pin );
	  HAL_GPIO_TogglePin( LED_2_GPIO_Port, LED_2_Pin );
	  osDelay(500);
  }
  /* USER CODE END 5 */
}

/**
  * @brief  Period elapsed callback in non blocking mode
  * @note   This function is called  when TIM1 interrupt took place, inside
  * HAL_TIM_IRQHandler(). It makes a direct call to HAL_IncTick() to increment
  * a global variable "uwTick" used as application time base.
  * @param  htim : TIM handle
  * @retval None
  */
void HAL_TIM_PeriodElapsedCallback(TIM_HandleTypeDef *htim)
{
  if (htim->Instance == TIM1) {
    HAL_IncTick();
  }
}

/**
  * @brief  This function is executed in case of error occurrence.
  * @retval None
  */
void Error_Handler(void)
{
  /* USER CODE BEGIN Error_Handler_Debug */
  /* User can add his own implementation to report the HAL error return state */
  __disable_irq();
  while (1)
  {
  }
  /* USER CODE END Error_Handler_Debug */
}

#ifdef  USE_FULL_ASSERT
/**
  * @brief  Reports the name of the source file and the source line number
  *         where the assert_param error has occurred.
  * @param  file: pointer to the source file name
  * @param  line: assert_param error line source number
  * @retval None
  */
void assert_failed(uint8_t *file, uint32_t line)
{
  /* USER CODE BEGIN 6 */
  /* User can add his own implementation to report the file name and line number,
     ex: printf("Wrong parameters value: file %s on line %d\r\n", file, line) */
  /* USER CODE END 6 */
}
#endif /* USE_FULL_ASSERT */

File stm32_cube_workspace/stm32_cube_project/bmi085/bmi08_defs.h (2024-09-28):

/**
* Copyright (c) 2024 Bosch Sensortec GmbH. All rights reserved.
*
* BSD-3-Clause
*
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
* 1. Redistributions of source code must retain the above copyright
*    notice, this list of conditions and the following disclaimer.
*
* 2. Redistributions in binary form must reproduce the above copyright
*    notice, this list of conditions and the following disclaimer in the
*    documentation and/or other materials provided with the distribution.
*
* 3. Neither the name of the copyright holder nor the names of its
*    contributors may be used to endorse or promote products derived from
*    this software without specific prior written permission.
*
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
* @file       bmi08_defs.h
* @date       2024-07-29
* @version    v1.9.0
*
*/

#ifndef BMI08_DEFS_H_
#define BMI08_DEFS_H_

/*********************************************************************/
/**\ header files */
#ifdef __KERNEL__
#include <linux/types.h>
#include <linux/kernel.h>
#else
#include <stdint.h>
#include <stddef.h>
#include <stdbool.h>
#endif

/*********************************************************************/
/** \name       Common macros                   */
/*********************************************************************/

#if !defined(UINT8_C) && !defined(INT8_C)
#define INT8_C(x)               S8_C(x)
#define UINT8_C(x)              U8_C(x)
#endif

#if !defined(UINT16_C) && !defined(INT16_C)
#define INT16_C(x)              S16_C(x)
#define UINT16_C(x)             U16_C(x)
#endif

#if !defined(INT32_C) && !defined(UINT32_C)
#define INT32_C(x)              S32_C(x)
#define UINT32_C(x)             U32_C(x)
#endif

#if !defined(INT64_C) && !defined(UINT64_C)
#define INT64_C(x)              S64_C(x)
#define UINT64_C(x)             U64_C(x)
#endif

/**\name C standard macros */
#ifndef NULL
#ifdef __cplusplus
#define NULL                    0
#else
#define NULL                    ((void *) 0)
#endif
#endif

#ifndef TRUE
#define TRUE                    UINT8_C(1)
#endif

#ifndef FALSE
#define FALSE                   UINT8_C(0)
#endif

/**
 * BMI08_INTF_RET_TYPE is the read/write interface return type which can be overwritten by the build system.
 */
#ifndef BMI08_INTF_RET_TYPE
#define BMI08_INTF_RET_TYPE     int8_t
#endif

/**
 * The last error code from read/write interface is stored in the device structure as intf_rslt.
 */
#ifndef BMI08_INTF_RET_SUCCESS
#define BMI08_INTF_RET_SUCCESS  INT8_C(0)
#endif

/*************************** BMI08 Accelerometer Macros *****************************/

/** Register map */
/* Accel registers */

/**\name    Accel Chip Id register */
#define BMI08_REG_ACCEL_CHIP_ID                 UINT8_C(0x00)

/**\name    Accel Error condition register */
#define BMI08_REG_ACCEL_ERR                     UINT8_C(0x02)

/**\name    Accel Status flag register */
#define BMI08_REG_ACCEL_STATUS                  UINT8_C(0x03)

/**\name    Accel X LSB data register */
#define BMI08_REG_ACCEL_X_LSB                   UINT8_C(0x12)

/**\name    Accel X MSB data register */
#define BMI08_REG_ACCEL_X_MSB                   UINT8_C(0x13)

/**\name    Accel Y LSB data register */
#define BMI08_REG_ACCEL_Y_LSB                   UINT8_C(0x14)

/**\name    Accel Y MSB data register */
#define BMI08_REG_ACCEL_Y_MSB                   UINT8_C(0x15)

/**\name    Accel Z LSB data register */
#define BMI08_REG_ACCEL_Z_LSB                   UINT8_C(0x16)

/**\name    Accel Z MSB data register */
#define BMI08_REG_ACCEL_Z_MSB                   UINT8_C(0x17)

/**\name    Sensor time byte 0 register */
#define BMI08_REG_ACCEL_SENSORTIME_0            UINT8_C(0x18)

/**\name    Sensor time byte 1 register */
#define BMI08_REG_ACCEL_SENSORTIME_1            UINT8_C(0x19)

/**\name    Sensor time byte 2 register */
#define BMI08_REG_ACCEL_SENSORTIME_2            UINT8_C(0x1A)

/**\name    Accel Interrupt status0 register */
#define BMI08_REG_ACCEL_INT_STAT_0              UINT8_C(0x1C)

/**\name    Accel Interrupt status1 register */
#define BMI08_REG_ACCEL_INT_STAT_1              UINT8_C(0x1D)

/**\name    Accel general purpose register 0*/
#define BMI08_REG_ACCEL_GP_0                    UINT8_C(0x1E)

/**\name    Sensor temperature MSB data register */
#define BMI08_REG_TEMP_MSB                      UINT8_C(0x22)

/**\name    Sensor temperature LSB data register */
#define BMI08_REG_TEMP_LSB                      UINT8_C(0x23)

/**\name    Accel general purpose register 4*/
#define BMI08_REG_ACCEL_GP_4                    UINT8_C(0x27)

/**\name    Accel Internal status register */
#define BMI08_REG_ACCEL_INTERNAL_STAT           UINT8_C(0x2A)

/**\name    Accel configuration register */
#define BMI08_REG_ACCEL_CONF                    UINT8_C(0x40)

/**\name    Accel range setting register */
#define BMI08_REG_ACCEL_RANGE                   UINT8_C(0x41)

/**\name    Accel Interrupt pin 1 configuration register */
#define BMI08_REG_ACCEL_INT1_IO_CONF            UINT8_C(0x53)
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

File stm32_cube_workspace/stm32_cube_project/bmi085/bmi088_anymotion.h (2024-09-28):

/**
* Copyright (c) 2024 Bosch Sensortec GmbH. All rights reserved.
*
* BSD-3-Clause
*
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
* 1. Redistributions of source code must retain the above copyright
*    notice, this list of conditions and the following disclaimer.
*
* 2. Redistributions in binary form must reproduce the above copyright
*    notice, this list of conditions and the following disclaimer in the
*    documentation and/or other materials provided with the distribution.
*
* 3. Neither the name of the copyright holder nor the names of its
*    contributors may be used to endorse or promote products derived from
*    this software without specific prior written permission.
*
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
* @file       bmi088_anymotion.h
* @date       2024-07-29
* @version    v1.9.0
*
*/

/*! \file bmi088_anymotion.h
 * \brief Sensor Driver for BMI088_ANYMOTION family of sensors */

/*!
 * @defgroup bmi088_anymotion BMI088_ANYMOTION
 */

#ifndef BMI088_ANYMOTION_H_
#define BMI088_ANYMOTION_H_

#ifdef __cplusplus
extern "C" {
#endif

/*********************************************************************/
/*                          Header files                             */
/*********************************************************************/
#include "bmi08.h"

/*********************************************************************/
/*                     Macro Definitions                             */
/*********************************************************************/

/**\name    Accel unique chip identifier */
#define BMI088_ANYMOTION_ACCEL_CHIP_ID_PRIM                   UINT8_C(0x1A)
#define BMI088_ANYMOTION_ACCEL_CHIP_ID_SEC                    UINT8_C(0x1E)

/**\name    Orientation result register*/
#define BMI088_ANYMOTION_ACCEL_ANY_MOT_INT                    UINT8_C(0x02)
#define BMI088_ANYMOTION_ACCEL_ERR_INT_ENABLE                 UINT8_C(0x80)

/**\name  BMI09 Accel Range */
#define BMI088_ANYMOTION_ACCEL_RANGE_3G                       UINT8_C(0x00)
#define BMI088_ANYMOTION_ACCEL_RANGE_6G                       UINT8_C(0x01)
#define BMI088_ANYMOTION_ACCEL_RANGE_12G                      UINT8_C(0x02)
#define BMI088_ANYMOTION_ACCEL_RANGE_24G                      UINT8_C(0x03)

#define BMI088_ANYMOTION_ACCEL_ANY_MOT_INT_DISABLE            UINT8_C(0x00)
#define BMI088_ANYMOTION_ACCEL_ANY_MOT_INT_ENABLE             UINT8_C(0x02)
#define BMI088_ANYMOTION_ACCEL_ERR_INT_DISABLE                UINT8_C(0x00)

/**\name    Axis Remap Feature size */
#define BMI088_ANYMOTION_FEATURE_SIZE                         UINT8_C(0x1E)

/**\name    Accel remap start address */
#define BMI088_ANYMOTION_ADDR_AXES_REMAP_START                UINT8_C(0x1C)

/**\name    Mask definition for config version */
#define BMI088_ANYMOTION_CONFIG_MAJOR_MASK                    UINT16_C(0x3C0)
#define BMI088_ANYMOTION_CONFIG_MINOR_MASK                    UINT8_C(0x3F)

/**\name    Bit position for major version from config */
#define BMI088_ANYMOTION_CONFIG_MAJOR_POS                     UINT8_C(0x06)

/**\name    Config ID start address */
#define BMI088_ANYMOTION_ADDR_CONFIG_ID_START                 UINT8_C(0x1A)

#define BMI088_ANYMOTION_E_REMAP_ERROR                        INT8_C(-11)

#define BMI088_ANYMOTION_STATUS_SET                           UINT8_C(1)
#define BMI088_ANYMOTION_STATUS_CLEAR                         UINT8_C(0)

/* Power mode switching delay 30ms - refer data sheet table 3 */
#define BMI088_ANYMOTION_GYRO_POWER_MODE_SWITCHING_DELAY_MS   UINT8_C(30)

/* Accel device init delay - refer data sheet section 3 */
#define BMI088_ANYMOTION_ACCEL_DEVICE_INIT_DELAY_MS           UINT8_C(50)

/* Accel power mode switching delay - data sheet section 4.1.1 */
#define BMI088_ANYMOTION_ACCEL_POWER_MODE_SWITCHING_DELAY_MS  UINT8_C(5)

/* Delay required to get temperature data 1.28s - refer data sheet section 5.3.7 */
#define BMI088_ANYMOTION_TEMPERATURE_DATA_READ_DELAY_MS       UINT8_C(1300)

/* Self-test: Resulting minimum difference signal in mg for BMI088_ANYMOTION */
#define BMI088_ANYMOTION_ST_ACC_X_AXIS_SIGNAL_DIFF            UINT16_C(1000)
#define BMI088_ANYMOTION_ST_ACC_Y_AXIS_SIGNAL_DIFF            UINT16_C(1000)
#define BMI088_ANYMOTION_ST_ACC_Z_AXIS_SIGNAL_DIFF            UINT16_C(500)

/**\name     Feature start Addresses  */
#define BMI088_ANYMOTION_ACCEL_ANYMOTION_ADR                  UINT8_C(0x00)

/**\name    Accel Any-motion Macros  */
#define BMI088_ANYMOTION_ACCEL_ANYMOTION_LEN                  UINT8_C(0x02)
#define BMI088_ANYMOTION_ACCEL_ANYMOTION_THRESHOLD_MASK       UINT16_C(0x07FF)
#define BMI088_ANYMOTION_ACCEL_ANYMOTION_THRESHOLD_SHIFT      UINT8_C(0x00)
#define BMI088_ANYMOTION_ACCEL_ANYMOTION_SEL_MASK             UINT16_C(0x0800)
#define BMI088_ANYMOTION_ACCEL_ANYMOTION_SEL_SHIFT            UINT8_C(0x0B)
#define BMI088_ANYMOTION_ACCEL_ANYMOTION_DURATION_MASK        UINT16_C(0x1FFF)
#define BMI088_ANYMOTION_ACCEL_ANYMOTION_DURATION_SHIFT       UINT8_C(0x00)
#define BMI088_ANYMOTION_ACCEL_ANYMOTION_X_EN_MASK            UINT16_C(0x2000)
#define BMI088_ANYMOTION_ACCEL_ANYMOTION_X_EN_SHIFT           UINT8_C(0x0D)
#define BMI088_ANYMOTION_ACCEL_ANYMOTION_Y_EN_MASK            UINT16_C(0x4000)
#define BMI088_ANYMOTION_ACCEL_ANYMOTION_Y_EN_SHIFT           UINT8_C(0x0E)
#define BMI088_ANYMOTION_ACCEL_ANYMOTION_Z_EN_MASK            UINT16_C(0x8000)
#define BMI088_ANYMOTION_ACCEL_ANYMOTION_Z_EN_SHIFT           UINT8_C(0x0F)

/*********************************************************************/
/*! @name       Macro Definitions for Axes re-mapping                */
/*********************************************************************/

/**\name Enable/Disable Selections */
#define BMI088_ANYMOTION_X_AXIS                               UINT8_C(0)
#define BMI088_ANYMOTION_Y_AXIS                               UINT8_C(1)
#define BMI088_ANYMOTION_Z_AXIS                               UINT8_C(2)

/**\name Define values of axis and its sign for re-map settings */
#define BMI088_ANYMOTION_MAP_X_AXIS                           UINT8_C(0x00)
#define BMI088_ANYMOTION_MAP_Y_AXIS                           UINT8_C(0x01)
#define BMI088_ANYMOTION_MAP_Z_AXIS                           UINT8_C(0x02)
#define BMI088_ANYMOTION_MAP_POSITIVE                         UINT8_C(0x00)
#define BMI088_ANYMOTION_MAP_NEGATIVE                         UINT8_C(0x01)

/*! @name Macros for the user-defined values of axes and their polarities */
#define BMI088_ANYMOTION_X                                    UINT8_C(0x01)
#define BMI088_ANYMOTION_NEG_X                                UINT8_C(0x09)
#define BMI088_ANYMOTION_Y                                    UINT8_C(0x02)
#define BMI088_ANYMOTION_NEG_Y                                UINT8_C(0x0A)
#define BMI088_ANYMOTION_Z                                    UINT8_C(0x04)
#define BMI088_ANYMOTION_NEG_Z                                UINT8_C(0x0C)
#define BMI088_ANYMOTION_AXIS_MASK                            UINT8_C(0x07)
#define BMI088_ANYMOTION_AXIS_SIGN                            UINT8_C(0x08)
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

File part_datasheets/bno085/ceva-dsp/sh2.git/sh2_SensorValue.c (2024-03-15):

/*
 * Copyright 2015-21 CEVA, Inc.
 *
 * Licensed under the Apache License, Version 2.0 (the "License");
 * you may not use this file except in compliance with the License and 
 * any applicable agreements you may have with CEVA, Inc.
 * You may obtain a copy of the License at
 *
 *   http://www.apache.org/licenses/LICENSE-2.0
 *
 * Unless required by applicable law or agreed to in writing, software
 * distributed under the License is distributed on an "AS IS" BASIS,
 * WITHOUT WARRANTIES OR CONDITIONS OF ANY KIND, either express or implied.
 * See the License for the specific language governing permissions and
 * limitations under the License.
 */

/*
 * BNO080 Sensor Event decoding
 */

#include "sh2_SensorValue.h"
#include "sh2_err.h"
#include "sh2_util.h"

#include <stdio.h>

#define SCALE_Q(n) (1.0f / (1 << n))

const float scaleRadToDeg = 180.0f / 3.14159265358f;

// ------------------------------------------------------------------------
// Forward declarations

static int decodeRawAccelerometer(sh2_SensorValue_t *value, const sh2_SensorEvent_t *event);
static int decodeAccelerometer(sh2_SensorValue_t *value, const sh2_SensorEvent_t *event);
static int decodeLinearAcceleration(sh2_SensorValue_t *value, const sh2_SensorEvent_t *event);
static int decodeGravity(sh2_SensorValue_t *value, const sh2_SensorEvent_t *event);
static int decodeRawGyroscope(sh2_SensorValue_t *value, const sh2_SensorEvent_t *event);
static int decodeGyroscopeCalibrated(sh2_SensorValue_t *value, const sh2_SensorEvent_t *event);
static int decodeGyroscopeUncal(sh2_SensorValue_t *value, const sh2_SensorEvent_t *event);
static int decodeRawMagnetometer(sh2_SensorValue_t *value, const sh2_SensorEvent_t *event);
static int decodeMagneticFieldCalibrated(sh2_SensorValue_t *value, const sh2_SensorEvent_t *event);
static int decodeMagneticFieldUncal(sh2_SensorValue_t *value, const sh2_SensorEvent_t *event);
static int decodeRotationVector(sh2_SensorValue_t *value, const sh2_SensorEvent_t *event);
static int decodeGameRotationVector(sh2_SensorValue_t *value, const sh2_SensorEvent_t *event);
static int decodeGeomagneticRotationVector(sh2_SensorValue_t *value, const sh2_SensorEvent_t *event);
static int decodePressure(sh2_SensorValue_t *value, const sh2_SensorEvent_t *event);
static int decodeAmbientLight(sh2_SensorValue_t *value, const sh2_SensorEvent_t *event);
static int decodeHumidity(sh2_SensorValue_t *value, const sh2_SensorEvent_t *event);
static int decodeProximity(sh2_SensorValue_t *value, const sh2_SensorEvent_t *event);
static int decodeTemperature(sh2_SensorValue_t *value, const sh2_SensorEvent_t *event);
static int decodeReserved(sh2_SensorValue_t *value, const sh2_SensorEvent_t *event);
static int decodeTapDetector(sh2_SensorValue_t *value, const sh2_SensorEvent_t *event);
static int decodeStepDetector(sh2_SensorValue_t *value, const sh2_SensorEvent_t *event);
static int decodeStepCounter(sh2_SensorValue_t *value, const sh2_SensorEvent_t *event);
static int decodeSignificantMotion(sh2_SensorValue_t *value, const sh2_SensorEvent_t *event);
static int decodeStabilityClassifier(sh2_SensorValue_t *value, const sh2_SensorEvent_t *event);
static int decodeShakeDetector(sh2_SensorValue_t *value, const sh2_SensorEvent_t *event);
static int decodeFlipDetector(sh2_SensorValue_t *value, const sh2_SensorEvent_t *event);
static int decodePickupDetector(sh2_SensorValue_t *value, const sh2_SensorEvent_t *event);
static int decodeStabilityDetector(sh2_SensorValue_t *value, const sh2_SensorEvent_t *event);
static int decodePersonalActivityClassifier(sh2_SensorValue_t *value, const sh2_SensorEvent_t *event);
static int decodeSleepDetector(sh2_SensorValue_t *value, const sh2_SensorEvent_t *event);
static int decodeTiltDetector(sh2_SensorValue_t *value, const sh2_SensorEvent_t *event);
static int decodePocketDetector(sh2_SensorValue_t *value, const sh2_SensorEvent_t *event);
static int decodeCircleDetector(sh2_SensorValue_t *value, const sh2_SensorEvent_t *event);
static int decodeHeartRateMonitor(sh2_SensorValue_t *value, const sh2_SensorEvent_t *event);
static int decodeArvrStabilizedRV(sh2_SensorValue_t *value, const sh2_SensorEvent_t *event);
static int decodeArvrStabilizedGRV(sh2_SensorValue_t *value, const sh2_SensorEvent_t *event);
static int decodeGyroIntegratedRV(sh2_SensorValue_t *value, const sh2_SensorEvent_t *event);
static int decodeIZroRequest(sh2_SensorValue_t *value, const sh2_SensorEvent_t *event);
static int decodeRawOptFlow(sh2_SensorValue_t *value, const sh2_SensorEvent_t *event);
static int decodeDeadReckoningPose(sh2_SensorValue_t *value, const sh2_SensorEvent_t *event);
static int decodeWheelEncoder(sh2_SensorValue_t *value, const sh2_SensorEvent_t *event);

// ------------------------------------------------------------------------
// Public API
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

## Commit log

2024-03-15 Put all in.
    [csr-spi-ftdi.sch, dc_motor_ctrl.kicad_pcb, dc_motor_ctrl.sch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]
2024-03-17 I think it is finished.
    [sensor_board.kicad_pcb, sensor_board.kicad_sch]
2024-03-17 Shift registers capable of wirking with TTL logic. Need the one which is both serial and parallel to be able to chain them in series.
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2024-03-21 Added resistor to the interrupt signal.
    [sensor_board.kicad_pcb, sensor_board.kicad_sch]
2024-03-31 Making the host board for multiple sensors.
    [multi_sensor_host.kicad_pcb, multi_sensor_host.kicad_sch, parallel_input.kicad_sch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]
2024-03-31 4 shift registers are added.
    [multi_sensor_host.kicad_sch, parallel_input.kicad_sch, tca9548a_sheet.kicad_sch]
2024-03-31 Added battery charger.
    [multi_sensor_host.kicad_sch]
2024-03-31 Replaced linear regulator with fixed 3.3V Buck converter MCP1603.
    [multi_sensor_host.kicad_sch]
2024-03-31 Inserted ESP-12S WIFI module.
    [multi_sensor_host.kicad_sch]
2024-03-31 Added stm32f405rgt6.
    [multi_sensor_host.kicad_sch]
2024-03-31 Selarated INT, SCL and SDA lines with GND and VDD so that crosstalk is reduced
    [sensor_board.kicad_pcb, sensor_board.kicad_sch]
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2024-04-04 Cannot re-save stm32f405rgt6. May be need to copy it again from the other project.
    [multi_sensor_host.kicad_sch, parallel_input.kicad_sch, tca9548a_sheet.kicad_sch]
2024-04-07 Fixed STM MCU symbol.
    [multi_sensor_host.kicad_sch]
2024-04-08 Added two 27 pin sockets.
    [multi_sensor_host.kicad_sch]
2024-04-08 Added all 5 sockets.
    [multi_sensor_host.kicad_sch]
2024-04-08 No errors, no warnings.
    [multi_sensor_host.kicad_sch, parallel_input.kicad_sch, tca9548a_sheet.kicad_sch]
2024-04-10 Replaced ESP-21S with BM71 Microchip UART BLE module.
    [multi_sensor_host.kicad_sch]
2024-04-11 Added power monitor. Split grounding and signals across ethernet cable twisted pairs.
    [multi_sensor_host.kicad_sch]
2024-04-14 Assigned footprints. Also, just in case found a chip I2C to diff. pair.
    [multi_sensor_host.kicad_sch, parallel_input.kicad_sch, tca9548a_sheet.kicad_sch]
2024-04-14 Assigning URLs.
    [multi_sensor_host.kicad_pcb, multi_sensor_host.kicad_sch, parallel_input.kicad_sch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]
2024-04-14 Assigning URLs...
    [multi_sensor_host.kicad_sch, parallel_input.kicad_sch, tca9548a_sheet.kicad_sch]
2024-04-14 Version with x4 RJ45 sockets. But probably it is not the best idea because there is just one instance of this x4 socker cheaper than 4 single ones.
    [multi_sensor_host.kicad_pcb, multi_sensor_host.kicad_sch]
2024-04-14 Revert "Version with x4 RJ45 sockets. But probably it is not the best idea because"
    This reverts commit d093a493317f39921dd6a9879e5a0815c2525c06.
    [multi_sensor_host.kicad_pcb, multi_sensor_host.kicad_sch]
2024-04-14 Assigned RJ45 URL and footprint.
    [multi_sensor_host.kicad_pcb, multi_sensor_host.kicad_sch]
2024-04-18 Placing footprints...
    [multi_sensor_host.kicad_pcb]
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2024-04-21 Placing components...
    [multi_sensor_host.kicad_pcb, multi_sensor_host.kicad_sch, parallel_input.kicad_sch]
2024-04-21 Placing components, tracing wires.
    [multi_sensor_host.kicad_pcb, multi_sensor_host.kicad_sch, tca9548a_sheet.kicad_sch]
2024-04-28 Finished. But it is too sparse. Probably can make it x2 more dense.
    [multi_sensor_host.kicad_pcb]
2024-04-28 Moving footprints...
    [multi_sensor_host.kicad_pcb]
2024-05-03 Prepared to move the MCU.
    [multi_sensor_host.kicad_pcb]
2024-05-05 Making wires thicker... Added Gnd zone.
    [multi_sensor_host.kicad_pcb]
2024-05-05 Probably good enough...
    [multi_sensor_host.kicad_pcb]
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2024-09-06 Added bno055 support from the old project. Doesn't compile now.
    [task_imu.c, task_led.c]
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2024-09-09 Debugging command reception. Currently receiving commands doesn't quite work. Will tru interrupt-based UART routine.
    [task_uart_output.c]
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2024-09-28 Making a BMI085 board.
    [board_bmi085.kicad_pcb]
2024-10-15 The BMI085 board has a bug. Pin 7 is not connected to Vdd. When fixed by soldering a wire on top to the nearest Vdd pin on a filtering capacitor, it starts working. Also, I2C addresses should be mult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
    [bmi088_anymotion.h, bmi088_mm.h, bmi08_defs.h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]
2024-10-15 Accelerometer works after adding software reset in the beginning of the initialization routine.
    [task_bmi085.c, task_led.c]
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2024-10-18 The algorithm itself works. But the orientation drifts. Need to compensate for the bias.
    [task_bmi085.c]
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2024-10-23 Delay doesn't work outside of stasks. And that seem to be the problem I had for two days.
    [bmi085_io.c, task_bmi085.c]
2024-10-23 And this way the initialization always works. May be the issue was in memory allocation??? Too large structure declared???
    [bmi085_io.c, task_bmi085.c]
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2024-10-26 It seems, it works as intended byt the UART data rate is too slow to push through all the data. Need to speed it up...
    [task_bmi085.c, task_uart_output.c]
2024-10-27 Sometimes the data is shifted. Need to figure out what exactly is going on. Due to that quaternions are weired. CRC8 fixes the problem but the frame is dropped.
    [task_bmi085.c, task_uart_output.c]
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2024-10-28 Re-done the sensor board. Now it can be up 4 sensors on a single cable.
    [board_bmi085.kicad_pcb, board_bmi085.kicad_sch]
2024-10-28 Little tail is not needed.
    [board_bmi085.kicad_pcb]
2024-10-30 Slightly re-routed wires so that through power and ground do not go through the IMU chip. Instead, they go around.
    [board_bmi085.kicad_pcb]
2024-10-30 Removed a tiny tail.
    [board_bmi085.kicad_pcb]
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2024-12-04 Added wires.
    [locking_mechanism.blend]
2024-12-04 More resolution.
    [locking_mechanism.blend]
2024-12-04 Another cutout and edge creases.
    [locking_mechanism.blend]
2024-12-04 Half editing done, probably.
    [locking_mechanism.blend]
2024-12-04 Created the other half as a reference to the first one. Because of that they are edited simultaneously.
    [locking_mechanism.blend]
2024-12-04 Added tabs.
    [locking_mechanism.blend]
2024-12-05 Made remeshed versions for 3d printing.
    [locking_mechanism.blend]
2024-12-05 Applied boolean. Without it walls still exist.
    [locking_mechanism.blend]
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2025-01-03 Reverted, increased cable cutout vertical size. Also added screw holes.
2025-01-03 Moved screw cutouts to the correct group.
2025-01-08 This is the reason why on one slot it caused failure.
    [bmi085_io.c]
2025-01-10 Finger piece design.
    [hand.blend]
2025-01-11 The utility tool for BM71.
    [BLEDK_UI_Parameter_Table.xls, my_multi_imu_configuration.txt]
2025-01-11 Made all fingers.
    [hand.blend]
2025-01-13 Changed dimensions for pinky and thumb adapters.
    [hand.blend]
2025-01-15 Palm piece.
    [hand.blend]
2025-01-17 Made it thinner.
    [hand.blend]
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2025-01-20 Made combined meshes.
    [imu_case.blend]
2025-01-21 Added separate left and right palm pieces.
    [hand.blend]
2025-01-26 Rigid edges.
    [hand.blend]
2025-02-23 Foot and toe holders.
    [foot_holder_right.stl, toe_right_a.stl, toe_right_b.stl]
2025-03-11 Left versions.
    [foot_holder_left.stl, foot_holder_right.stl, toe_left_a.stl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]
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2025-03-31 Just saving everything.
    [case_for_host_board_bottom.stl, case_for_host_board_top.stl, generic_holder.stl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]

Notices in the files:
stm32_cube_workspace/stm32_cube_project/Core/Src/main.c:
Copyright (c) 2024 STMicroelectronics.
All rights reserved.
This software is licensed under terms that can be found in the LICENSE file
